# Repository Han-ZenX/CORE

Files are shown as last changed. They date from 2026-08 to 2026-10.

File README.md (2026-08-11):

# CORE - 高端频率计核心计算模块

本项目是高端频率计的核心计算模块，基于 **Xilinx ZYNQ7020** 核心板实现高精度频率测量。系统采用 **FPGA 采集 + DDR 存储 + ARM 计算** 的异构协同架构，充分发挥 ZYNQ 平台 PL（可编程逻辑）与 PS（处理系统）协同工作的优势，实现高精度、高实时性的频率测量。

## 核心架构

```
┌─────────────────────────────────────────────────┐
│                 ZYNQ7020 核心板                  │
│                                                  │
│  ┌────────────┐   AXI   ┌─────────┐   ┌───────┐ │
│  │ FPGA (PL)  │ ──────► │   DDR   │ ─► │ ARM   │ │
│  │ 信号采集    │         │ 数据缓存 │    │ (PS)  │ │
│  │ 高精度计数  │         └─────────┘    │ 频率  │ │
│  └────────────┘                        │ 计算  │ │
│                                        └───────┘ │
└─────────────────────────────────────────────────┘
```

- **FPGA 采集**：利用 PL 端实现高速信号采集与精密计数，保证测量闸门时间的硬件级精度
- **DDR 存储**：采集数据经 AXI 总线高速写入 DDR，实现大容量、连续测量数据缓存
- **ARM 计算**：PS 端运行本仓库固件，完成数据处理、频率解算与结果输出

## 仓库结构

```
CORE-master/
├── firmware/            # 固件源码（ARM 端，分层架构）
│   ├── boards/          # 板级配置（支持多硬件平台切换）
│   ├── src/
│   │   ├── app/         # 应用层：测量任务与业务流程
│   │   ├── hal/         # 硬件抽象层：屏蔽底层差异
│   │   ├── drivers/     # 驱动层：外设与 PL 交互驱动
│   │   └── services/    # 服务层：日志、通信等通用服务
│   └── CMakeLists.txt   # 固件构建配置
├── hardware/            # 硬件设计资料
│   ├── schematic/       # 原理图
│   ├── pcb/             # PCB 设计文件
│   ├── pinout/          # 引脚定义
│   ├── bom/             # 物料清单
│   ├── gerber/          # Gerber 制板文件
│   └── 3d/              # 结构 3D 模型
├── software/            # 上位机软件
│   ├── desktop/         # 桌面端
│   ├── mobile/          # 移动端
│   └── cloud/           # 云端服务
├── tests/               # 测试代码（单元 / 集成 / 硬件在环）
├── tools/               # 构建脚本与工具
└── docs/                # 架构、API、用户手册等文档
```

## 固件分层设计

固件采用四层架构，配合 `boards/` 板级配置系统实现多硬件平台适配：

| 层级 | 职责 |
|---|---|
| `app` | 应用逻辑：测量流程控制、频率解算、结果管理 |
| `services` | 通用服务：日志、通信协议、系统服务管理 |
| `hal` | 硬件抽象：统一接口，隔离平台差异 |
| `drivers` | 外设驱动：PL 端数据交互、外设控制 |

## 构建

固件使用 CMake 构建：

```powershell
cd firmware
cmake -B build
cmake --build build
```

也可使用项目脚本：

```powershell
python tools/scripts/build.py
```

## 许可

详见 [LICENSE](LICENSE)。

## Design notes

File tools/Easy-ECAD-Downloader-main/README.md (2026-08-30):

<p align="center">
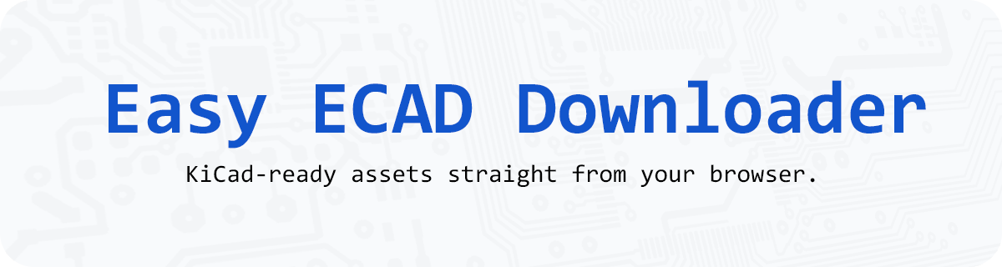
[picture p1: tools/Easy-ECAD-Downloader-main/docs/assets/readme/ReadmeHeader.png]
Easy ECAD Downloader
  
</p>

<p align="center">
  
  
  
  
  
</p>

<p align="center">
  <a href="https://chromewebstore.google.com/detail/easyeda-downloader/egbkokdcahpjimldjjaobimnofbdnncb"><strong>Install for Chrome</strong></a>
  &nbsp;|&nbsp;
  <a href="https://addons.mozilla.org/en-GB/firefox/addon/easy-ecad-downloader/"><strong>Install for Firefox</strong></a>
  &nbsp;|&nbsp;
  <a href="#quick-start"><strong>Quick start</strong></a>
  &nbsp;|&nbsp;
  <a href="#faq"><strong>FAQ</strong></a>
</p>

Easy ECAD Downloader is a browser extension for exporting KiCad-compatible CAD assets from supported distributor product pages.

It works on supported JLCPCB, LCSC, Mouser, Farnell, element14, and Newark part pages, and can download the available KiCad files for you: symbols, footprints, 3D models, and datasheets.

<br>

<p>
  
  <strong>Important:</strong> Generated library files should always be reviewed before manufacturing. Verify pin mapping, footprint dimensions, 3D model alignment, and datasheet accuracy before using exported files in production designs.
</p>
<br clear="left">

##  Contents

- [Installation](#installation)
- [Quick start](#quick-start)
- [Usage walkthrough](#usage-walkthrough)
- [Output structure](#output-structure)
- [Supported sources and outputs](#supported-sources-and-outputs)
- [Settings](#settings)
- [FAQ](#faq)
- [Technical overview](#technical-overview)
- [Contributing](#contributing)
- [Supporting docs](#supporting-docs)
- [License and attribution](#license-and-attribution)

##  Installation

| Browser | Install from | Notes |
|---|---|---|
| Chrome, Edge, Brave, and other Chromium browsers | [Chrome Web Store](https://chromewebstore.google.com/detail/easyeda-downloader/egbkokdcahpjimldjjaobimnofbdnncb) | Full support for EasyEDA-backed pages and SamacSys-backed Mouser/Farnell/element14/Newark downloads. |
| Firefox | [Firefox Add-ons](https://addons.mozilla.org/en-GB/firefox/addon/easy-ecad-downloader/) | Works for EasyEDA-backed pages. SamacSys-backed Mouser/Farnell/element14/Newark downloads need the optional Firefox relay setup. |

##  Quick start

1. Open a supported JLCPCB, LCSC, Mouser, Farnell, element14, or Newark component page.
2. Click the Easy ECAD Downloader extension icon.
3. Review the detected manufacturer and source part details.
4. Choose which assets to export.
5. Click `Download`.
6. Open the generated files from KiCad and review them before use.

##  Usage walkthrough

### 1. Open a supported component page

The content script detects supported part contexts from EasyEDA-backed JLCPCB/LCSC pages or SamacSys-backed Mouser/Farnell/element14/Newark pages.

<p align="center">
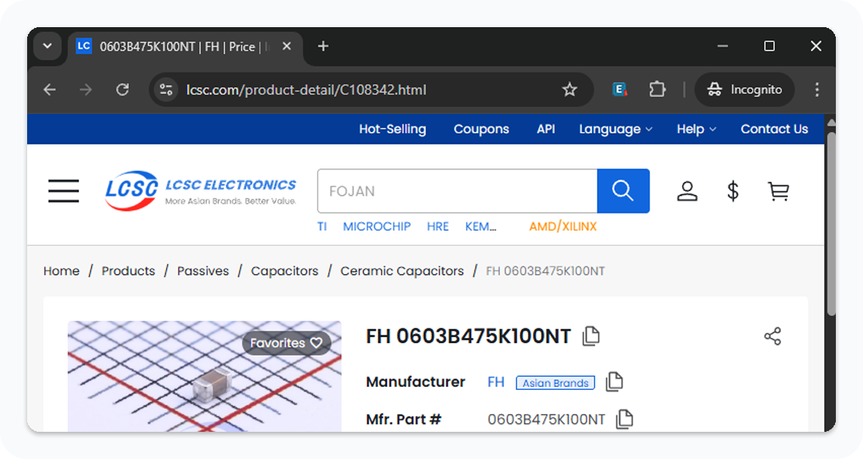
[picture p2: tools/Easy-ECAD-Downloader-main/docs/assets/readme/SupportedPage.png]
Supported component page
  
</p>

### 2. Preview and download from the popup

The popup shows manufacturer details, source-specific part metadata, symbol and footprint previews, and the available export options.

<p align="center">
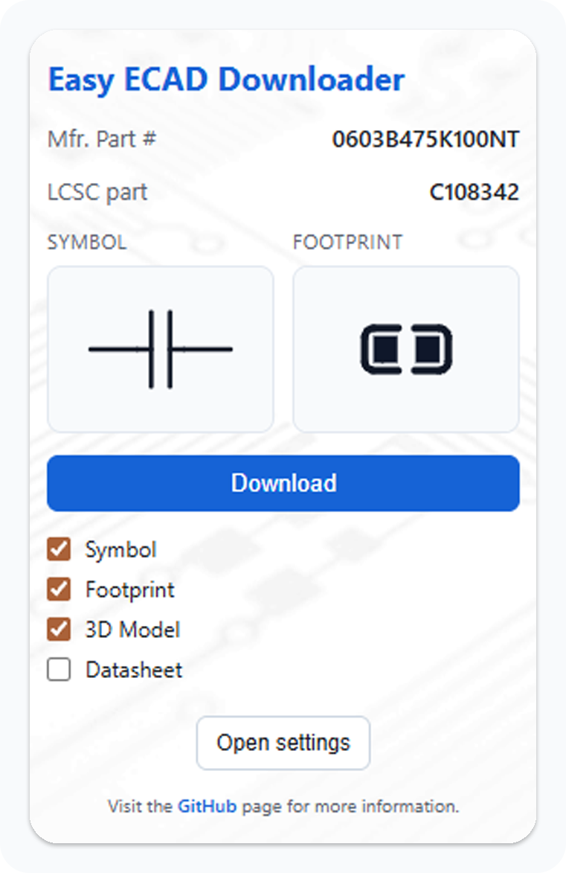
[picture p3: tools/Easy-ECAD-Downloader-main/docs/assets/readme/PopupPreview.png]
Easy ECAD Downloader popup preview
  
</p>

### 3. Use the generated KiCad files

Library mode creates a KiCad-style symbol library, footprint library, model folder, and datasheet folder under your browser downloads directory.

<p align="center">
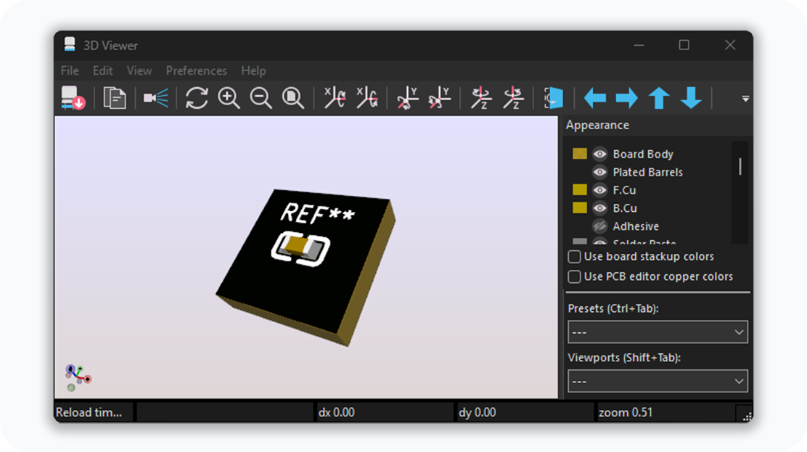
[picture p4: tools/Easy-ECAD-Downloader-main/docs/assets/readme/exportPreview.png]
KiCad 3D viewer export preview
  
</p>

##  Output structure

When `Save each file separately` is disabled, files are grouped under `Downloads/<library root>/`. The default library root is `easyECADDownloader`.

```text
Downloads/
`-- easyECADDownloader/
    |-- easyECADDownloader.kicad_sym
    |-- easyECADDownloader.pretty/
    |   `-- <component>.kicad_mod
    |-- easyECADDownloader.3dshapes/
    |   |-- <component>.step
    |   `-- <component>.wrl
    `-- datasheets/
        `-- <component>.pdf
```

When `Save each file separately` is enabled, selected files are saved as loose downloads instead of being grouped into a shared KiCad library folder. Exact filenames can vary by source.

```text
Downloads/
|-- <component>.kicad_sym
|-- <component>.kicad_mod
|-- <component>.step
|-- <component>.wrl
`-- <component>-datasheet.pdf
```

When a footprint and matching 3D model are exported together, the footprint model reference is rewritten to the generated model path. If no 3D model is exported, stale model references are removed from the generated footprint.

##  Supported sources and outputs

| Source flow | Pages | Symbol | Footprint | 3D model | Datasheet | Notes |
|---|---|---:|---:|---:|---:|---|
| EasyEDA-backed | JLCPCB, LCSC | Yes | Yes | When available | When available | Uses the detected LCSC id and upstream EasyEDA payload. |
| SamacSys-backed | Mouser, Farnell, element14, Newark | Yes | Yes | When available | No | Downloads the upstream KiCad ZIP and repackages selected assets. |

##  Settings

<p align="center">
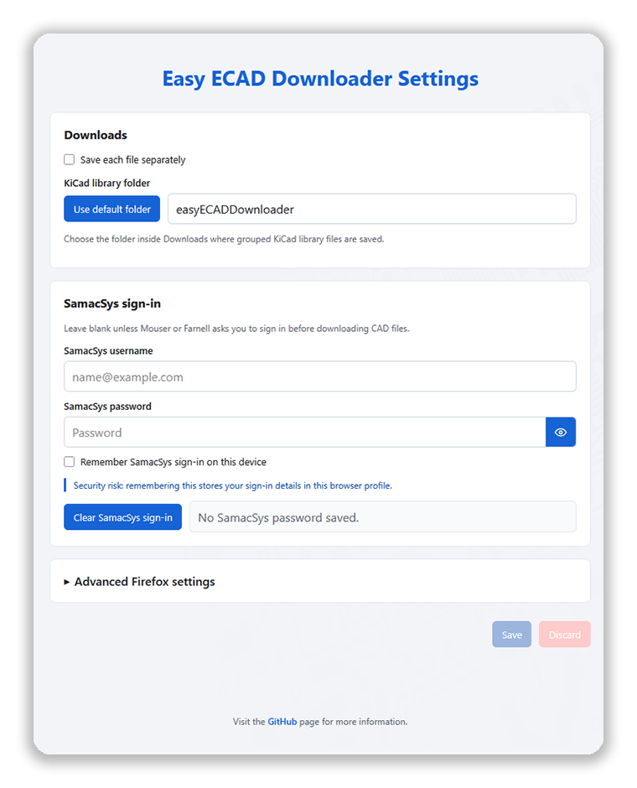
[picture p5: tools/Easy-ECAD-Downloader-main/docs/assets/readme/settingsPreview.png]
Easy ECAD Downloader settings page
  
</p>

| Setting | Purpose |
|---|---|
| `Save each file separately` | Switches between loose downloads and grouped KiCad library output. |
| `KiCad library folder` | Sets the Downloads-relative folder used for library mode, such as `easyECADDownloader` or `KiCad/easyECAD`. |
| `SamacSys username` and `SamacSys password` | Optional upstream sign-in details for Mouser/Farnell/element14/Newark CAD ZIP downloads. |
| `Advanced Firefox settings` | Configures the user-managed Firefox relay URL and helper-service auth when SamacSys export is needed in Firefox. |

Password and token fields are blank when the settings page opens, and each field has a local show/hide button for checking typed values. New values are kept for the current browser session by default. Tick the relevant `Remember ... on this device` box only if you accept the risk of storing that secret in the browser profile.

##  FAQ

<details>
<summary><strong>View frequently asked questions</strong></summary>

<br>

<details>
<summary><strong>What does Easy ECAD Downloader do?</strong></summary>

<br>

Easy ECAD Downloader is a browser extension for downloading KiCad-compatible ECAD assets from supported distributor pages. It helps export available symbols, footprints, 3D models, and datasheets from JLCPCB, LCSC, Mouser, Farnell, element14, and Newark product pages.

</details>

<details>
<summary><strong>Which websites does Easy ECAD Downloader support?</strong></summary>

<br>

Easy ECAD Downloader supports JLCPCB, LCSC, Mouser, Farnell, element14, and Newark product pages. JLCPCB and LCSC use EasyEDA-backed component data, while Mouser, Farnell, element14, and Newark use SamacSys-backed CAD downloads.

</details>

<details>
<summary><strong>What KiCad files can Easy ECAD Downloader create?</strong></summary>

<br>

Depending on the part and source data, Easy ECAD Downloader can create KiCad symbol libraries, footprint files, 3D model files, and datasheet PDFs. Common output files include `.kicad_sym`, `.kicad_mod`, `.pretty`, `.step`, `.wrl`, and PDF datasheets.

</details>

<details>
<summary><strong>Where are the downloaded KiCad files saved?</strong></summary>

<br>

In library mode, Easy ECAD Downloader saves files into a KiCad-style library folder under your browser Downloads directory. By default, this is `Downloads/easyECADDownloader/`. The output is grouped into a symbol library, a `.pretty` footprint folder, a 3D models folder, and a datasheets folder when applicable. If `Save each file separately` is enabled, selected files are saved directly into the browser downloads folder.

</details>

<details>
<summary><strong>Do I still need to check the downloaded symbol or footprint?</strong></summary>

<br>

Yes. Generated CAD assets should always be reviewed before manufacturing. Check pin mapping, pad numbering, footprint dimensions, polarity, orientation, courtyard and clearance assumptions, 3D model placement, and datasheet accuracy before ordering boards.

</details>

<details>
<summary><strong>How do I import JLCPCB or EasyEDA footprints and symbols into KiCad easily?</strong></summary>

<br>

Open a supported JLCPCB or LCSC component page, click the Easy ECAD Downloader extension icon, preview the available assets, and download the KiCad output. The extension converts the available EasyEDA-backed component data into KiCad-compatible symbol, footprint, and 3D model files where those assets exist.

</details>

<details>
<summary><strong>Can I download EasyEDA footprints for KiCad?</strong></summary>

<br>

Yes. For supported JLCPCB and LCSC pages, Easy ECAD Downloader downloads EasyEDA-backed component data and exports KiCad-compatible footprint files. When available, it can also export the matching symbol, 3D model, and datasheet.

</details>

<details>
<summary><strong>How do I download JLCPCB footprints for KiCad?</strong></summary>

<br>

Find the supported JLCPCB or LCSC component page, open Easy ECAD Downloader, and download the available KiCad footprint. This avoids manually redrawing the land pattern when source CAD data is already available.

</details>

<details>
<summary><strong>Can I convert an LCSC part number into a KiCad symbol, footprint, and 3D model?</strong></summary>

<br>

Yes, for supported LCSC or JLCPCB parts with available EasyEDA-backed data. Easy ECAD Downloader detects the part from the browser page and exports the available KiCad assets without requiring a command-line workflow.

</details>

<details>
<summary><strong>Is Easy ECAD Downloader an EasyEDA to KiCad converter?</strong></summary>

<br>

Yes, for component-level library assets. Easy ECAD Downloader converts supported EasyEDA-backed component data into KiCad-compatible symbols, footprints, and 3D models. It is not a full EasyEDA project, schematic, or PCB-layout migration tool.

</details>

<details>
<summary><strong>Can I download KiCad footprints from Mouser?</strong></summary>

<br>

Yes, when the Mouser product page provides supported ECAD data. Easy ECAD Downloader uses the Mouser and SamacSys CAD flow to download the available KiCad files and organize the selected symbol, footprint, and 3D model assets.

</details>

<details>
<summary><strong>Can I download KiCad footprints from Farnell, element14, or Newark?</strong></summary>

<br>

Yes, when the Farnell, element14, or Newark product page links to supported SamacSys ECAD data. Easy ECAD Downloader can export the available KiCad symbol, footprint, and 3D model files from the supported download flow.

</details>

<details>
<summary><strong>Is Easy ECAD Downloader a Library Loader alternative for KiCad?</strong></summary>

<br>

For supported JLCPCB, LCSC, Mouser, Farnell, element14, and Newark pages, yes. Easy ECAD Downloader can reduce the need for a separate Library Loader workflow by detecting the part page, downloading the available CAD assets, and organizing KiCad-compatible output. Library Loader may still be useful for unsupported distributors, unsupported parts, or non-KiCad workflows.

</details>

<details>
<summary><strong>How do I add downloaded symbols and footprints to KiCad?</strong></summary>

<br>

Add the generated `.kicad_sym` file through KiCad's symbol library manager and add the generated `.pretty` folder through KiCad's footprint library manager. KiCad tracks symbol and footprint libraries separately, so add both if you downloaded both asset types.

</details>

<details>
<summary><strong>Why is a KiCad symbol, footprint, 3D model, or datasheet missing?</strong></summary>

<br>

Easy ECAD Downloader can only export files that are available from the source page or linked component metadata. Some components have a footprint but no symbol, no 3D model, no datasheet, or incomplete upstream CAD data.

</details>

</details>

##  Technical overview

<p align="center">
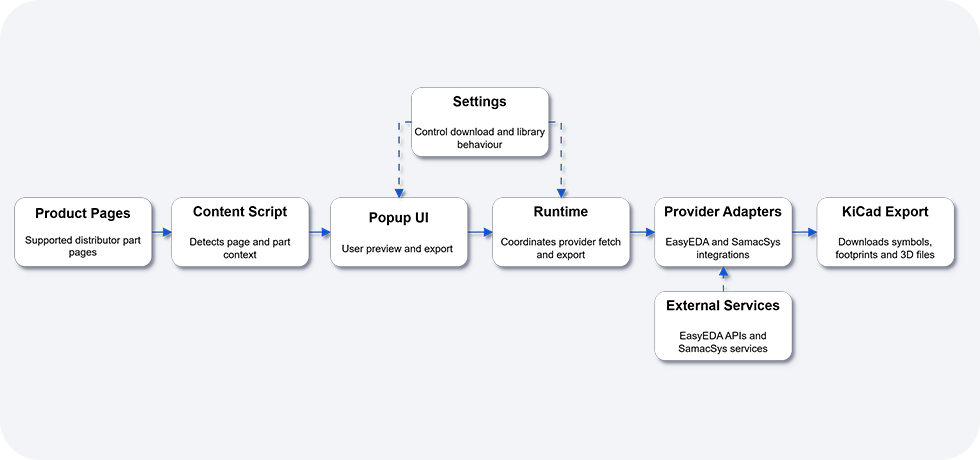
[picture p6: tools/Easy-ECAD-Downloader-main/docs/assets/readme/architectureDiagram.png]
Extension architecture overview
  
</p>

At a high level, the content script detects supported part pages, the popup requests previews and downloads, the service-worker runtime routes provider-specific work, and the source adapters fetch or repackage upstream CAD assets for KiCad.

Key implementation areas:

- `src/content_script.js`: DOM inspection and provider-aware part detection.
- `src/popup.js`: popup UI, settings, preview requests, and export requests.
- `src/service_worker_runtime.js`: provider routing and worker orchestration.
- `src/core/`: shared settings, downloads, preview data, and storage-backed library helpers.
- `src/sources/`: EasyEDA and SamacSys source adapters.
- `src/kicad/`: EasyEDA parsing, KiCad emitters, shared conversion helpers, and OBJ-to-WRL conversion.
- `tests/`: regression suite for behavior, conversion, browser runtime boundaries, and repository hygiene.

##  Contributing

Read [contributing.md](contributing.md) for development setup, local validation, contribution expectations, and manual extension-loading instructions. Read [AGENTS.md](AGENTS.md) for repository working rules.

Good contributions include parser fixes for real component pages, regression tests for failed exports, output-format corrections, browser compatibility fixes, and documentation that makes the workflow clearer for KiCad users.

##  Supporting docs

- [systemDesign.md](systemDesign.md): design source of truth.
- [CHANGELOG.md](CHANGELOG.md): notable changes by release or branch delta.
- [SECURITY.md](SECURITY.md): vulnerability reporting and credential-handling notes.
- [docs/architecture-notes.md](docs/architecture-notes.md): short implementation notes.
- [docs/firefox-samacsys-proxy.md](docs/firefox-samacsys-proxy.md): Cloudflare Worker relay example for Firefox SamacSys support.

##  License and attribution

This project includes and is derived from:

`easyeda2kicad.py`  
Copyright (c) uPesy  
Licensed under the GNU Affero General Public License v3.0

Additional code in this repository remains under the repository license.

See [LICENSE](LICENSE) for details.

<p align="center" style="font-size: 18px;">
  Made with heart for open-source electronics.
</p>

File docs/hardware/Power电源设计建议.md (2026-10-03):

# Power 电源设计建议

> 针对 `hardware/schematic/v1.0/CORE/Power.kicad_sch` 的审查结果。**第 1、2 条是原理图错误，不改上不了电**；其余为设计改进。

@fig:pw_now 图 1　当前电源网络与问题位置

## 一、必须修改

| 问题 | 依据 | 建议 |
|---|---|---|
| 1. **核心板 +5V 没有电源来源** | Power 页输出叫 `+VBUS_5V`，ZynqCore 页（核心板 5V 输入）和 Comm_Periph 页叫 `+5V`。KiCad 按电源符号 Value 区分网络，**两者不连通** | 统一网络名，或用 0Ω / 磁珠把 `+VBUS_5V` 接到 `+5V` |
| 2. USB_D+ / USB_D- 无去向 | Power 页的本地标签，其他页没有同名网络 | J10 只供电：D+/D- 打 NC、删标签。要接 PS 端 USB OTG：改层次标签接到核心板 |

（Storage 页 FT2232H 的 J12 电源网络叫 `+VBUS`，是第三个独立网络；若只用于 VBUS 检测则没问题，需确认。）

## 二、供电能力不够

| 问题 | 说明 | 建议 |
|---|---|---|
| 3. **Rd=5.1k 只能拿到 USB 默认电流** | 接电脑 USB 2.0 口仅 500 mA（2.5 W）。7020 核心板 + DDR3 + 千兆 PHY + LCD + 底板外设满载约 **3~5 W** | 加 DC 圆座（5V/3A）做主电源，与 VBUS 二极管 OR；或明确要求 5V/3A Type-C 适配器 |
| 4. TPS78633 散热 | 压差 1.7 V，0.8 A 时耗散 **约 1.4 W**；SOT-223 热阻约 50~60 °C/W，温升 70~80 °C | 先估算底板 3.3V 电流，**超过 0.5 A 换同步 Buck**（TPS62130 / SY8089）；否则 TAB 下铺铜加散热过孔 |

## 三、保护与可靠性

| 问题 | 建议 |
|---|---|
| 5. VBUS 入口无保护 | 串 **PPTC（2A）→ TVS（SMBJ5.0A）→ 防反接**（PMOS 或肖特基） |
| 6. VBUS 电容总量约 20 µF | USB 规范要求 **≤10 µF**，否则插入浪涌可能触发电脑口过流保护。入口留 10 µF + 100 nF，大电容放到开关之后 |
| 7. 无电源开关、无指示灯 | 加拨动开关或负载开关（TPS22918），加一颗电源 LED |
| 8. SHIELD 直接接 GND | 可用；重视 EMC/ESD 时改 1 MΩ ∥ 4.7 nF 接地 |

## 四、1.8V 支路

| 问题 | 建议 |
|---|---|
| 9. AMS1117-1.8 压差仅 1.5 V | 典型压差 1.1~1.3 V，大电流余量不足；负载几十 mA 可接受 |
| 10. 1.8V 是否需要 | FT2232HL **自带 1.8V 片内 LDO**（VREGOUT）。若只给 FT2232H 用，**AMS1117 可整个去掉**；TXS02612 等也需要则换 ME6211-1.8 / RT9013-18 |
| 11. AMS1117 输出电容稳定性 | 老款要求一定 ESR（手册推荐 22 µF 钽电容），全陶瓷可能振荡；换钽电容或换陶瓷稳定型 LDO |

（TPS78633 外围正确：EN 经 0Ω 接 IN，NR 10 nF，输出 10 µF 陶瓷，均符合手册。）

## 五、修改后拓扑

@fig:pw_fix 图 2　建议的电源路径（绿色为新增器件；只用 USB 供电时可省去 DC 圆座一路，但须用 5V/3A 适配器；1.8V 支路见第四节）

| 优先级 | 修改项 | 涉及文件 |
|---|---|
| **立即** | `+VBUS_5V` 与 `+5V` 统一；处理 `USB_D±` | Power、ZynqCore |
| **高** | 确认整板功耗，决定是否加 DC 圆座、3.3V 是否换 Buck | Power |
| 中 | PPTC + TVS + 防反接，VBUS 电容 ≤10 µF，开关与 LED | Power |
| 低 | 1.8V 支路精简或换 LDO | Power、Storage |

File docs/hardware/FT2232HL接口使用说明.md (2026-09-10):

# FT2232HL 接口使用说明

本文说明 FT2232HL 在 CORE 板上作为调试桥的用法：双通道如何分配、JTAG 与 UART 如何共存、主机端如何识别、配置 EEPROM 如何接线与量产烧录。

> 适用范围：FT2232HL（LQFP-64），配置 EEPROM 为 93LC56BT-I/OT。文中 `x` 代表通道字母，A 通道引脚为 `ADBUS/ACBUS`，B 通道为 `BDBUS/BCBUS`。

---

## 0. 总览

@fig:ft_arch 图 1　双通道架构与主机端枚举关系

FT2232HL 是一颗 **USB 复合设备**：一个 USB 口、一组 VID:PID（默认 `0403:6010`），下挂 **两个完全独立的 USB Interface**，各驱动一个通道引擎。

这带来本文最重要的一个结论：

**JTAG 和 UART 不需要"切换"，让 Channel A 跑 JTAG、Channel B 跑 UART，两者同时在线。**

绝大多数商用调试器（FT2232H Mini Module、Digilent HS2、Olimex ARM-USB-OCD）都是这个方案。只有在引脚实在不够、被迫让一个通道兼两职时，才会遇到切换问题（见第 4 节）。

---

## 1. 支持的全部通讯模式

每个通道可独立配置为下列任一模式：

| 模式 | 可用通道 | 最高速率 | 用途 |
| --- | --- | --- | --- |
| UART / RS232 | A、B | 12 Mbaud | 串口，带 RTS/CTS、DTR/DSR 硬件流控 |
| MPSSE 之 JTAG | A、B | 30 MHz | 芯片调试 |
| MPSSE 之 SPI | A、B | 30 MHz | **仅 Master**，支持模式 0/1/2/3 |
| MPSSE 之 I2C | A、B | 约 400 kHz | 软件模拟，有硬件前提，见第 6 节 |
| 异步 Bit-Bang | A、B | 约 1 MB/s | 8 位 GPIO 直接读写 |
| 同步 Bit-Bang | A、B | — | 时钟驱动的 GPIO |
| 异步 245 FIFO | A、B | 8 MB/s | 8 位并口 |
| 同步 245 FIFO | **仅 A** | 40 MB/s | FPGA 高速数据流 |
| CPU-FIFO（同步/异步） | A、B | — | 模拟 CPU 总线，带地址线 |
| Fast Opto-Isolated Serial | A、B | — | 光隔离串行 |

### 1.1 一条硬限制

**同步 245 FIFO 会让整颗芯片进入单通道状态**，启用后 Channel B 完全不可用。

如果需要"40 MB/s 高速口 + 独立串口"的组合，FT2232HL 做不到，应改用 FT600/FT601，或另加一颗 FT232。

### 1.2 不支持的

- **SPI Slave**：只能做主机
- **CAN / LIN 协议层**：RS485 可外挂收发器，用 RTS 或 TXDEN 引脚控方向
- **USB Host**：本芯片只能作为 USB device
- **硬件 I2C 控制器**：I2C 是 MPSSE 模拟出来的

---

## 2. 推荐的通道分配

| 方案 | Channel A | Channel B | 说明 |
| --- | --- | --- | --- |
| **调试板标配** | MPSSE 之 JTAG | UART | 最常用，两者同时可用 |
| **带 Flash 烧录** | MPSSE（JTAG / SPI 运行时切） | UART | 用 `flashrom` 直烧板载 SPI Flash，省一个编程器 |

第二种方案之所以成立，是因为 **JTAG 与 SPI 的引脚天然对应**：TCK 即 SCK、TDI 即 MOSI、TDO 即 MISO，硬件走线不用动，只有片选 CS# 需要单独安排（占用 TMS 那根线，或改用某个 GPIOL 引脚）。

`flashrom` 原生支持本芯片作 SPI 编程器：

```
flashrom -p ft2232_spi:type=2232H,port=A -w firmware.bin
```

---

## 3. 引脚复用对照

@fig:ft_pinmux 图 2　同一组数据引脚在四种模式下的功能

图 2 中红框标出的 **xD0 至 xD3 是复用冲突区**。这四根线在不同模式下含义完全不同，所以同一通道换模式时，**外部走线也必须跟着换**，否则会出现 JTAG 的 TCK 直接怼到目标板串口 RX 上这类硬件冲突。

xD4 至 xD7 与 xCBUS0 至 xCBUS7 在 MPSSE 下恒为通用 GPIO（GPIOL0-3 / GPIOH0-7），可自由用作复位、片选、LED 指示等。

---

## 4. 同一通道内切换模式

**只在被迫共用一个通道时才需要这一节。** 优先用第 2 节的分通道方案。

### 4.1 MPSSE 不是 EEPROM 选项

这是最容易误解的一点：**EEPROM 里只能选 `RS232 UART` 或 `245 FIFO`，没有 MPSSE 这个选项。**

MPSSE 是**运行时**通过 D2XX 命令进入的：

```c
FT_SetBitMode(h, 0x00, FT_BITMODE_RESET);   // 0x00 -> back to UART
FT_SetBitMode(h, 0x00, FT_BITMODE_MPSSE);   // 0x02 -> enter MPSSE (JTAG/SPI/I2C)
```

完整流程：关闭串口应用 → `FT_Open` → `FT_SetBitMode(MPSSE)` → 执行 JTAG 操作 → 用完 `FT_BITMODE_RESET` 退回 UART。

### 4.2 驱动占用问题

同一个通道不能同时被 VCP 和 D2XX 打开，这是切换时最常卡住的地方。

**Windows**：VCP 驱动把通道枚举成 COM 口后，D2XX 抢不到。用 FT_PROG 把该通道的 Driver 从 `Virtual COM Port` 改成 `D2XX Direct`，重新插拔生效。

**Linux**：`ftdi_sio` 会自动绑定，OpenOCD 打不开。先解绑：

```
echo -n "1-1.2:1.0" | sudo tee /sys/bus/usb/drivers/ftdi_sio/unbind
```

其中 `:1.0` 是 Channel A，`:1.1` 是 Channel B，具体总线编号用 `lsusb -t` 查。

按第 8 节的建议把 A 通道 EEPROM 配成 D2XX，这一步就可以省掉。

---

## 5. 主机端如何识别 JTAG 与 UART

### 5.1 Type-C 接口本身不参与识别

Type-C 只是 USB 的物理载体。CC 引脚负责插入检测、正反插方向、供电能力广播（Rp/Rd）以及 DP/TBT 这类 Alt Mode 协商，**没有"这个口是 JTAG 还是 UART"的语义**，也不该有 —— 正反插必须功能一致。

板子作为纯 UFP 时，CC1/CC2 各接一个 **5.1 kΩ 下拉到 GND** 即可。不要试图用 CC 状态去切 JTAG/UART，那是滥用协议。

### 5.2 识别发生在 USB 枚举层

| 项目 | Channel A | Channel B |
| --- | --- | --- |
| USB Interface | `0` | `1` |
| 默认描述符 | `Dual RS232-HS A` | `Dual RS232-HS B` |
| Linux 设备节点 | `/dev/ttyUSB0` | `/dev/ttyUSB1` |
| Linux 稳定路径 | `/dev/serial/by-id/...-if00-port0` | `...-if01-port0` |
| Windows | `USB Serial Converter A` | `USB Serial Converter B` |

**枚举顺序是固定的**，A 恒为 Interface 0，不会因插拔顺序改变。

生产上不要依赖 `ttyUSB0` 这种会随插拔顺序变化的名字，用 `by-id` 路径或序列号定位。

### 5.3 让设备自我标识

按第 8 节配置后，OpenOCD 可以精确锁定目标：

```
ftdi vid_pid 0x0403 0x6010
ftdi device_desc "CORE Debug A"
ftdi serial "CORE001"
ftdi channel 0
```

`ftdi channel` 的取值：`0` 为 Channel A，`1` 为 Channel B。

---

## 6. I2C 的两个硬件前提

@fig:ft_i2c 图 3　MPSSE 做 I2C 时的外部接线要求

MPSSE 的 I2C 是模拟出来的，必须满足两个外部条件，否则完全不工作：

1. **xD1 与 xD2 必须外部短接成一根 SDA。** MPSSE 的输入与输出引脚物理分离，不短接就读不到从机的 ACK。
2. **SCL 与 SDA 都要外接 2.2 kΩ 至 4.7 kΩ 上拉。** MPSSE 引脚不是真开漏，靠固件把引脚切成输入态来模拟高阻态，没有上拉就没有高电平。

结论：**I2C 能用但别扭**。做产线烧录 EEPROM、读配置芯片够用；做高速传感器采集不合适，速率上限约 400 kHz。

---

## 7. 配置 EEPROM 的接线

@fig:ft_eeprom 图 4　93LC56B 接法与救砖测试点

| FT2232H | 93LC56B | 备注 |
| --- | --- | --- |
| EECS | CS | 直连 |
| EECLK | CLK | 直连 |
| EEDATA | DI | 直连 |
| EEDATA | DO | **必须串 2.2 kΩ** |

**2.2 kΩ 不能省。** FT2232H 把 DI 与 DO 合并到一根 EEDATA 线上，靠这个电阻避免双向驱动冲突。FTDI 官方参考设计（FT2232H 数据手册典型应用电路、AN_113）即为此接法。

### 7.1 选型注意

- **必须用 B 版**。`93LC56B` 是固定 128 x 16（x16 组织），FT2232H 只认这种；`93LC56A` 是 x8 组织，**不能用**。
- SOT-23-6（后缀 `OT`）封装的 ORG 引脚不引出，内部固定为 x16，正合适。
- 引脚编号请对照 Microchip 数据手册的 OT 封装图确认，**不要照搬 SOIC-8 的顺序**。
- 工作电压 2.5 V 至 5.5 V，与 FT2232H 的 3.3 V EEPROM 接口兼容。

### 7.2 留一个救砖测试点

**布板时给 EEPROM 的 CS 引脚留一个测试点。** 一旦写错 VID/PID 导致设备无法枚举，把 CS（或 DO）临时短接到 GND，FT2232H 读不到有效 EEPROM 就会回退片内默认值重新枚举；此时松开短接，用 FT_PROG 的 `Erase` 擦掉重烧即可。

有这个测试点，能省掉一次返修。

---

## 8. 出厂配置与量产烧录

### 8.1 先澄清一个概念

**FT_PROG 是运行在 PC 上的 Windows 上位机软件，不是芯片里的东西。** 它通过 USB 与 FT2232H 通信，由 FT2232H 代为读写旁边的 EEPROM。

**93LC56BT-I/OT 出厂是空白的（全 `0xFF`）**，不含任何 FTDI 配置数据，Microchip 出厂只做电性测试。

### 8.2 空白 EEPROM 时的行为

芯片检测到 EEPROM 空白（或根本没挂 EEPROM）时，会回退到片内固化默认值，**照样能枚举**：

| 项目 | 空白 EEPROM 时的默认值 |
| --- | --- |
| VID:PID | `0403:6010` |
| Product Description | `Dual RS232-HS` |
| Serial Number | **无**，所有板子都一样 |
| Channel A / B 模式 | 都是 UART + VCP |

所以首件焊好后直接插 USB 就能被 FT_PROG 认到并烧录，**不需要预烧 EEPROM**。代价是没有序列号、没有自定义描述符、JTAG 通道会被 VCP 驱动抢走。

### 8.3 CORE 板建议配置

| 配置项 | 值 | 理由 |
| --- | --- | --- |
| VID:PID | 保持 `0403:6010` | 省掉自签驱动的麻烦 |
| Product Description | `CORE Debug` | 设备管理器里一眼可辨 |
| Serial Number | `CORE` + 自动递增 | 多板同插时可区分 |
| Channel A Driver | **D2XX Direct** | JTAG 通道，不产生 COM 口 |
| Channel B Driver | **Virtual COM Port** | UART 通道，产生 COM 口 |
| Channel A / B Hardware | 都填 `RS232 UART` | MPSSE 是运行时切的，EEPROM 无此选项 |

这样配置后，**系统里只有一个 COM 口，那必然是 UART**，零歧义；`ftdi_sio` 也不会去抢 JTAG 通道，第 4.2 节的解绑操作可以省掉。

### 8.4 小批量烧录

1. 拿第一块板在 FT_PROG 里配好所有选项
2. `File` → `Save As Template`，存成 `.xml`
3. 后续板子：`Devices` → `Scan and Parse` → 载入模板 → `Program`

**务必开启序列号自动递增**：在 `USB String Descriptors` 里勾选 `Auto Generate Serial No.`，设好 Prefix（如 `CORE`），每次 Program 自动加一。没有唯一序列号的话，两块板同时插上就分不清了。

FT_PROG 支持一次扫描多个已连接设备并批量 Program，接 USB Hub 可以同时烧一排。

### 8.5 产线脚本化

| 方案 | 平台 | 说明 |
| --- | --- | --- |
| `ftdi_eeprom`（libftdi） | Linux | 配置文件驱动，最容易接入产线脚本，推荐 |
| D2XX `FT_EEPROM_Program` | 跨平台 | 自写烧录程序，可对接 MES 或序列号数据库 |
| FT_PROG 命令行 | Windows | 3.x 版本带 CLI，参数见软件内 Help |

---

## 9. 检查清单

投板前逐项确认：

- Channel A 与 Channel B 的用途已明确分配，未出现一个通道兼两职
- 若用 I2C：xD1 与 xD2 已外部短接，SCL/SDA 上拉电阻已放置
- EEPROM 的 DO 到 EEDATA 之间已串 2.2 kΩ
- EEPROM 型号是 `93LC56B`（x16），不是 `93LC56A`
- EEPROM CS 引脚已引出测试点
- Type-C 的 CC1/CC2 各有 5.1 kΩ 下拉到 GND
- 未使用同步 245 FIFO 模式，或已接受 Channel B 不可用的代价

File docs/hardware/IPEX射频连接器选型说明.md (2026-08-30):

# IPEX 射频连接器选型说明

IPEX 是 I-PEX 公司的微型射频同轴连接器系列,正式名称是 **MHF 系列**。1 代和 3 代最核心的区别是**尺寸**,但最要命的实用区别是——**两者物理上完全不能互配。**

## 主要参数对比

| | IPEX 1 (MHF1) | IPEX 3 (MHF3) |
|---|---|---|
| 别名 | U.FL(Hirose 等效型号) | — |
| 配对后高度 | 约 2.5 mm | 约 1.6 mm |
| 插座尺寸 | 约 2.6 x 2.6 mm | 约 2.0 x 2.0 mm |
| 频率范围 | DC ~ 6 GHz | DC ~ 12 GHz |
| 常配线径 | 1.13 mm / 1.37 mm | 0.81 mm / 1.13 mm |
| 特性阻抗 | 50 ohm | 50 ohm |
| 插拔寿命 | 约 30 次 | 约 30 次 |
| 普及度 / 成本 | 最高 / 最低 | 较低 / 较高 |

(具体数值各厂商略有出入,正式选型请以对应料号的 datasheet 为准。线径越细走线越柔,但插入损耗越大,长走线优先选粗线。)

完整代际关系顺带列一下,方便辨认:

| 代次 | 型号 | 高度 | 典型场景 |
|---|---|---|---|
| 1 代 | MHF1 / U.FL | ~2.5 mm | WiFi 模块、路由器、开发板 |
| 2 代 | MHF2 / W.FL | ~2.0 mm | 过渡型号,较少见 |
| 3 代 | MHF3 | ~1.6 mm | 小型化设备、部分 M.2 |
| 4 代 | MHF4 | ~1.2 mm | M.2 无线网卡、5G 模组主流 |
| 4L | MHF4L | ~1.0 mm | 极限薄型设备 |

需要注意 **U.FL 是 Hirose(广濑)的商标**,与 I-PEX 的 MHF1 是互相兼容的等效产品,不是同一家公司的型号。

---

## 几个实际会踩的坑

**① 绝对不能混插。** 1 代和 3 代的插座内径、中心针尺寸都不同。强行按压 3 代插头到 1 代插座上(或反过来),轻则接触不良、驻波比飙升,重则直接把插座撑坏。需要跨代连接**只能用转接线**。

**② 插拔寿命只有约 30 次,且这是个真实限制。** 这类连接器设计上是"装配一次"的,不是给你反复调试用的。频繁插拔会导致外圈弹片失去弹性,表现为接触时好时坏、天线性能忽高忽低——这种间歇性故障很难排查。**建议做法:调试期用一根 IPEX 转 SMA 的转接线固定在板上,后续所有插拔都在 SMA 那一端进行。**

**③ 拔的时候要用专用拔具,或垂直向上撬。** 斜着拽会把插座从 PCB 上撕下来,连焊盘一起。

**④ 频率上限影响选型。** 2.4G / 5.8G 应用(WiFi、蓝牙、图传)用 1 代完全够。但 WiFi 6E 的 6 GHz 频段、或更高频段会触及 1 代上限,应选 3 代或 4 代。

---

## 怎么选

| 使用场景 | 推荐 |
|---|---|
| 开发板、原型验证 | **IPEX 1** — 最便宜,线材最好买,装配最省心 |
| 2.4G / 5.8G 应用 | **IPEX 1** — 频率完全覆盖 |
| 成品设备空间紧张,或需 6 GHz 以上 | IPEX 3 / 4 |
| 对接 M.2 形态无线模组 | 先查模组 datasheet,**现在主流是 MHF4,不是 3 代** |

**没有明确的高度约束或频率需求时,默认选 IPEX 1**,不要仅为"更先进"而选高代次。

## 怎么识别手上的是哪一代

最可靠的方法是量插座外径:

| 实测外径 | 判定 |
|---|---|
| 约 2.6 mm | **1 代** |
| 约 2.0 mm | **3 代** |
| 约 1.6 mm | **4 代** |

目视对比也行,1 代明显比 3 代粗一圈。

## 采购提醒

电商平台上 IPEX 代次的**标注错误率很高**,同一卖家不同链接口径不一致的情况常见。买线材时优先看实物尺寸标注,或直接买注明 I-PEX 原厂料号的产品(如 `20279-001E-01`、`20449-001E-01`)。转接线要**同时确认两端的代次和线径**。

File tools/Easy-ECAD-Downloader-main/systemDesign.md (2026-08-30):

# System Design: Easy ECAD Downloader

## 1. Purpose

This document describes the current implemented design of the Easy ECAD Downloader browser extension.

The extension supports three provider flows:

- EasyEDA-backed JLCPCB and LCSC pages
- Mouser pages that expose the SamacSys / Component Search Engine ECAD button
- Farnell, element14, and Newark pages that expose the Supplyframe / SamacSys ECAD link

The repository remains intentionally compact. If code and design diverge, update one of them in the same change.

## 2. Implemented workflow

### 2.1 Supported operator flow

1. Open a supported JLCPCB, LCSC, Mouser, Farnell, element14, or Newark product page.
2. Optionally open the extension settings page to configure download layout or advanced SamacSys options.
3. Open the extension popup.
4. Ask the content script for a provider-aware part context via `GET_PART_CONTEXT`.
5. Ask the service worker for `GET_PART_PREVIEWS`.
6. Choose which artifacts to export.
7. Ask the service worker to export the current part with `EXPORT_PART`.

### 2.2 Explicit non-goals

The current repository does not implement:

- browser automation outside the popup/content-script/service-worker model
- end-to-end browser-run integration tests in real Chrome or Firefox
- a project-hosted proxy or cloud backend for Mouser / SamacSys Firefox support
- a broader application-layer architecture beyond the existing file split

## 3. Supported contexts and assumptions

- The content script is injected only on matching JLCPCB, LCSC, Mouser, Farnell, element14, and Newark pages.
- EasyEDA-backed pages expose an LCSC-style part id such as `C12345`.
- Mouser support depends on the ECAD button `#lnk_CadModel[data-testid="ProductInfoECAD"]`.
- Farnell, element14, and Newark support depend on a Supplyframe / SamacSys link exposed in the `ECAD / MCAD` section.
- The content script returns a generic part context, not a provider-specific ad hoc message shape.
- EasyEDA previews are generated locally from CAD payload primitives.
- SamacSys distributor previews come from SamacSys JSON preview endpoints and are displayed as PNG data URLs.
- EasyEDA datasheet availability comes from URLs exposed by the upstream payload.
- SamacSys distributor datasheet export is currently unsupported.
- SamacSys distributor preview and export work directly in Chrome.
- Firefox SamacSys support is opt-in and depends on a user-managed relay URL stored by the extension settings page.
- SamacSys ZIP export may still require upstream authentication.
- On Chrome direct requests, the worker first tries the normal browser session and retries the ZIP request once with configured upstream auth if the first ZIP request returns `401`.
- On Firefox relay mode, the worker uses the relay path and returns a sign-in-required error if the upstream ZIP request remains unauthorized.
- In Firefox relay mode, the service worker forwards matching `componentsearchengine.com` cookies through the relay so authenticated ZIP downloads can reuse the user's upstream browser session.
- Firefox relay mode can send a separate relay `Authorization` header on the Worker POST when the user configures helper-service auth.
- Firefox relay mode can forward an upstream SamacSys `Authorization` header for ZIP endpoints that rely on HTTP Basic auth instead of cookies alone.
- The Manifest V3 background is declared for both Chrome and Firefox: Chrome uses `background.service_worker`, while Firefox uses the background-document fallback from `background.scripts`. This combined manifest relies on Firefox 121 or newer.
- The configurable library download root must remain relative to the browser's Downloads directory.

## 4. Repository architecture

### 4.1 User-to-backend flow

There is no application-owned cloud backend in this repository. The service worker is the browser-local backend boundary, and it calls external upstream provider services when previews or exports require network data.

```mermaid
flowchart LR
    user["User on supported product page"]
    productPage["JLCPCB / LCSC / Mouser / Farnell / element14 / Newark DOM"]
    contentScript["Content script\nsrc/content_script.js"]
    popup["Extension popup\nsrc/popup.js"]
    settingsPage["Settings page\nsrc/settings_page.js"]
    storage["Browser storage\nchrome.storage.local/session"]
    serviceWorker["Extension backend\nsrc/service_worker.js"]
    converter["EasyEDA converter\nsrc/kicad_converter.js"]
    zipReader["SamacSys ZIP reader\nsrc/vendor/zip_reader.js"]
    downloads["Browser downloads\nchrome.downloads"]
    easyeda["EasyEDA APIs\nCAD, STEP, OBJ, datasheet URLs"]
    samacsys["SamacSys / Component Search Engine\nentry, preview, ZIP, WRL"]

    user --> productPage
    user --> popup
    user --> settingsPage
    popup -- "GET_PART_CONTEXT" --> contentScript
    contentScript --> productPage
    contentScript -- "provider-aware part context" --> popup
    popup <--> storage
    settingsPage <--> storage
    popup -- "GET_PART_PREVIEWS / EXPORT_PART" --> serviceWorker
    serviceWorker <--> storage
    serviceWorker --> easyeda
    serviceWorker --> samacsys
    serviceWorker --> converter
    serviceWorker --> zipReader
    converter --> serviceWorker
    zipReader --> serviceWorker
    serviceWorker --> downloads
    downloads --> user
```

### 4.2 `src/content_script.js`

Owns page inspection only:

- detect EasyEDA/LCSC identifiers from definition lists, known tables, and page text
- detect Mouser SamacSys ECAD availability from the ECAD button
- detect Farnell, element14, or Newark SamacSys ECAD availability from the `Supply Frame Models Link`
- read provider-specific source part metadata from the page DOM
- reconstruct the Mouser SamacSys entry URL from `loadPartDiv(...)`
- reconstruct the Farnell, element14, or Newark SamacSys entry URL from the Supplyframe link metadata
- reply to popup-originated `GET_PART_CONTEXT` requests

It remains a DOM-reading boundary with no network or download logic.

### 4.3 `src/popup.js`

Owns popup UI state and user interaction:

- cache popup DOM elements
- load current settings from extension storage for provider gating
- query the active tab and request the current provider-aware part context
- render the fixed `Mfr. Part #` row plus a dynamic provider-specific source row
- request previews and datasheet availability
- gate downloads based on provider support and checkbox selection
- open the dedicated settings page from the popup settings button
- send `EXPORT_PART` requests to the service worker

It remains the UI-facing boundary. It does not own fetch, archive extraction, or conversion logic.

### 4.4 `src/settings_page.js`

Owns persistent settings UI:

- load and save ordinary settings through `chrome.storage.local`
- keep helper tokens and SamacSys credentials in `chrome.storage.session` unless the user explicitly opts to remember them on this device
- keep form edits local to the page until the user chooses `Save`, with `Discard` restoring the last loaded settings
- expose the download layout controls, including loose-file mode and library folder root
- expose SamacSys username/password auth inputs for Mouser/Farnell/element14/Newark downloads
- let users temporarily show or hide typed password and token values without changing stored settings
- expose Firefox-only helper-service auth and relay URL inside a hidden-by-default advanced Firefox settings menu
- normalize settings through `src/core/settings.js`

It does not request part contexts, previews, exports, or downloads.

### 4.5 `src/service_worker.js`

Owns runtime registration only:

- register the Manifest V3 background message listener
- delegate request handling to the runtime/router module

The operational core now lives behind this entrypoint rather than inside one file.

### 4.6 `src/service_worker_runtime.js` and supporting modules

Own the service-worker backend orchestration:

- normalize part context and route preview/export requests by provider
- enforce runtime-specific blocking such as Firefox SamacSys gating when no relay is configured
- compose source adapters with shared download, storage, and settings helpers
- shape success and error responses back to the popup

The runtime is intentionally split into:

- source adapters under `src/sources/`
- shared worker business logic under `src/core/`

Within `src/sources/`, the current SamacSys-backed distributors share:

- `src/sources/samacsys_distributor_adapter.js` for provider-facing preview/export orchestration
- `src/sources/samacsys_common.js` for shared SamacSys page, preview, ZIP, and asset-rewrite helpers

This keeps the message boundary stable while allowing future sources to be added without expanding the entrypoint.

### 4.7 `src/kicad_converter.js`

Keeps the public conversion API stable and delegates implementation to focused converter modules under `src/kicad/`.

Those modules own:

- EasyEDA symbol parsing
- EasyEDA footprint parsing
- coordinate, unit, and text-style conversion
- KiCad symbol text generation
- KiCad footprint text generation
- OBJ-to-WRL conversion

Mouser parts do not flow through this converter for symbol or footprint generation because the upstream ZIP already contains KiCad assets.

### 4.8 `src/vendor/zip_reader.js`

Owns small runtime archive extraction support:

- ZIP central-directory parsing
- stored-entry reads
- deflate-entry reads through runtime decompression primitives

It exists so the service worker can extract the KiCad subtree from the SamacSys ZIP without adding a build step.

### 4.9 `tests`

The test suite remains the primary regression net for:

- page-detection logic
- popup state transitions and messaging
- service-worker orchestration and download behavior
- EasyEDA conversion behavior
- repository governance and footer discipline

## 5. Core data flow

### 5.1 Detect the current part

- The popup queries the active tab.
- The popup asks the content script for `GET_PART_CONTEXT`.
- On EasyEDA-backed pages, the content script returns:
  - provider `easyedaLcsc`
  - source label `LCSC part`
  - source part number equal to the detected LCSC id
  - manufacturer part number when the page exposes `Mfr. Part #`
  - lookup metadata containing the LCSC id
- On Mouser pages, the content script returns:
  - provider `mouserSamacsys`
  - source label `Mouser part`
  - source part number equal to `Mouser No`
  - manufacturer part number equal to `Mfr. No`
  - lookup metadata containing manufacturer name and a reconstructed SamacSys entry URL
- On Farnell, element14, and Newark pages, the content script returns:
  - provider `farnellSamacsys`
  - source label `Farnell part`, `element14 part`, or `Newark part` based on the current site
  - source part number equal to the detected page order code or page part identifier
  - manufacturer part number from the SamacSys link metadata or page text
  - lookup metadata containing manufacturer name and a reconstructed SamacSys entry URL

### 5.2 Request previews

- The popup asks the service worker for `GET_PART_PREVIEWS`.
- EasyEDA-backed pages:
  - fetch the EasyEDA CAD payload
  - synthesize symbol and footprint SVG previews
  - derive datasheet availability from the payload
- Mouser, Farnell, element14, and Newark pages:
  - fetch the SamacSys entry URL
  - follow the part-page redirect and parse the ZIP form and preview token
  - fetch `symbol.php` and `footprint.php` JSON previews
  - return PNG data URLs
  - report datasheet unavailable
- In Firefox, those same SamacSys requests are sent through the optional user-managed relay when configured; otherwise they fail early with the existing proxy-required error.
- In Firefox relay mode, the worker attaches the current SamacSys cookie header to proxied requests when browser cookies are available.
- In Firefox relay mode, the worker sends any configured relay `Authorization` header only on the Worker POST itself.
- In Firefox relay mode, the worker forwards upstream SamacSys `Authorization` only when it can generate one from configured SamacSys username/password credentials.
### 5.3 Export EasyEDA-backed parts

- The service worker fetches the EasyEDA payload using the detected LCSC id.
- The converter produces KiCad symbol and footprint text.
- Symbol, footprint, 3D, and datasheet exports follow the existing current-provider settings:
  - loose-file downloads when `downloadIndividually` is `true`
  - KiCad-style library structure when `downloadIndividually` is `false`
- Library-mode symbol exports merge into a stored symbol library keyed by the resolved library root.
- Footprint model references are reconciled after 3D export attempts finish:
  - loose-file footprints reference `${KIPRJMOD}/<modelFilename>` when a model was exported
  - library-mode footprints reference `../<libraryName>.3dshapes/<modelFilename>` when a model was exported
  - stale footprint `(model ...)` blocks are removed when no selected 3D model artifact is exported
- EasyEDA OBJ-to-WRL conversion recenters model geometry in X/Y, bottom-aligns the model in Z, and writes footprint model offsets in KiCad 3D units so the WRL aligns with the generated footprint.
- Library-mode datasheet exports are written under `<libraryRoot>/datasheets/`.

### 5.4 Export SamacSys distributor parts

- The service worker fetches the SamacSys entry URL and resolves the part page.
- In Firefox with a configured relay, the service worker sends those SamacSys HTTP requests through the relay instead of fetching upstream directly.
- In Firefox with a configured relay, the service worker also reads the matching upstream cookies through `chrome.cookies` and forwards them with those proxied requests.
- For authenticated ZIP flows that use HTTP Basic auth, the service worker resolves upstream SamacSys `Authorization` from the shared precedence and:
  - on Chrome direct requests, retries one ZIP request with that auth after an initial `401`
  - on Firefox relay requests, forwards that auth through the relay as part of the proxied upstream request
- When helper-service auth is configured, the relay POST itself also carries a separate relay `Authorization` header that is never forwarded upstream.
- The part page supplies:
  - a stable `partID`
  - a preview token
  - ZIP download form metadata
- The service worker downloads the SamacSys ZIP and extracts only:
  - `KiCad/*.kicad_sym`
  - `KiCad/*.kicad_mod`
  - `3D/*.stp` and `3D/*.step`
  - optional `3D/*.wrl`
- Loose-file mode downloads the extracted files directly into Downloads.
- Library mode repackages the extracted assets into the current KiCad structure:
  - symbol library merge into `<libraryRoot>/<libraryName>.kicad_sym`
  - footprints into `<libraryRoot>/<libraryName>.pretty/`
  - 3D assets into `<libraryRoot>/<libraryName>.3dshapes/`
- Library mode rewrites:
  - the symbol `Footprint` property to `<libraryName>:<footprintName>`
  - the footprint `(model ...)` path to `../<libraryName>.3dshapes/<modelFilename>`
- When 3D export is selected, the worker exports STEP models and any WRL files already present in the SamacSys ZIP without probing extra remote WRL endpoints.

## 6. Storage and settings behavior

- The popup stays focused on detection, previews, export selection, and opening the dedicated settings page.
- The settings page owns persistent controls for download layout, Firefox relay configuration, and optional SamacSys auth values.
- The settings page uses explicit `Save` and `Discard` actions rather than writing every field edit immediately.
- The settings page hides the advanced Firefox settings menu when opened in Chrome.
- `chrome.storage.local` stores ordinary extension settings:
  - `downloadIndividually`
  - `libraryDownloadRoot`
  - `samacsysFirefoxProxyBaseUrl`
  - `rememberSamacsysCredentials`
  - `rememberSamacsysFirefoxProxyAuthorizationHeader`
- `chrome.storage.session` stores session-only secret values by default:
  - `samacsysFirefoxProxyAuthorizationHeader`
  - `samacsysFirefoxUsername`
  - `samacsysFirefoxPassword`
- If a remember-on-this-device box is checked, the corresponding helper token or SamacSys username/password is stored in `chrome.storage.local` instead.
- `chrome.storage.local` also stores accumulated symbol library text used for append-style symbol exports in library mode.
- Stored symbol-library content is keyed by the resolved library root so separate library folders keep separate merged symbol libraries.

## 7. Error and warning handling

- Detection failures in the popup produce user-facing status messages and disable export.
- Service-worker preview failures return structured error responses to the popup.
- Export failures return structured error responses to the popup.
- Partial export issues that do not invalidate the whole request, such as missing selected datasheets, unavailable selected 3D models, or selected SamacSys asset categories absent from the upstream ZIP, are accumulated as warnings.
- SamacSys distributor requests in Firefox fail early with a structured unsupported error message when no relay is configured.
- Relay transport failures are surfaced distinctly from upstream SamacSys HTTP failures.
- SamacSys ZIP `401 Unauthorized` responses are rewritten into a sign-in-required error so the popup can tell the user what upstream precondition is missing.

## 8. External dependencies and browser APIs

### 8.1 Network dependencies

- EasyEDA component API for CAD payloads
- EasyEDA module endpoints for STEP and OBJ assets
- SamacSys / Component Search Engine entry page, preview JSON endpoints, and ZIP download endpoint

### 8.2 Browser APIs

- `chrome.runtime`
- `chrome.storage.local`
- `chrome.storage.session`
- `chrome.downloads`
- `chrome.cookies` for Firefox relay cookie forwarding on SamacSys requests
- `Blob` and `URL.createObjectURL`
- runtime decompression primitives used by the vendored ZIP reader

## 9. Output artifacts and naming rules

- EasyEDA symbol output uses a standalone `<lcscId>-<symbolName>.kicad_sym` file in loose mode or the shared library file in library mode.
- SamacSys distributor loose-file symbol output keeps the extracted `.kicad_sym` filename from the ZIP.
- Footprint output uses the extracted or generated `.kicad_mod` filename.
- SamacSys distributor footprint library-mode downloads rewrite the model path into the library `.3dshapes` directory.
- EasyEDA footprint downloads rewrite the first KiCad `(model ...)` path to the exported STEP or WRL artifact, preferring WRL when both are produced, and remove stale model blocks when no model artifact is exported.
- EasyEDA datasheet output uses a sanitized base name plus `-datasheet` and the detected extension. In library mode it is saved under `<libraryRoot>/datasheets/`.
- The library root name defaults to `easyECADDownloader` and can be changed to another Downloads-relative folder for library mode.

## 10. Maintainability and testing boundaries

- `src/kicad_converter.js` should stay the main unit-test target for pure conversion rules.
- `src/content_script.js` should stay small enough to test through DOM fixtures and message mocks.
- `src/popup.js` should be tested with DOM fixtures and mocked browser APIs rather than real extension runs.
- `src/service_worker_runtime.js` should be tested with mocked browser APIs, mocked fetch, mocked archive extraction, and controlled converter stubs.
- The current Vitest/Vite/jsdom test stack requires Node `20.19.0+`, `22.13.0+`, or `24+`.
- Production source should not be refactored solely to make tests easier; harnesses should adapt to the existing code shape.
- Local and CI validation share `npm run validate`, which runs ESLint, Vitest, `npm audit --audit-level=moderate`, and `git diff --check`.
- GitHub Actions runs validation with `npm ci` on Node `20.19.0`, `22.13.0`, and `24.x`.
- `SECURITY.md` owns vulnerability reporting expectations and credential-handling guidance.
- Repository hygiene tests reject high-confidence secret patterns plus common local environment, archive, log, editor, and temporary files.
- Repository hygiene tests reject non-placeholder email addresses in code and fixture text while leaving documentation and canonical source footer contact details intact.
- Repository hygiene tests decode long HTTP Basic auth examples and require decoded identities to use placeholder email domains.
- Git-history security tests run those security checks across every reachable commit; CI uses a full-history checkout so rewritten or rebased branches are scanned beyond the tip tree. This is a full-validation and CI gate, not a manual per-intermediate-commit requirement while iterating locally.
- Repository hygiene tests also enforce conventional file names, lower camelCase function declarations, and maintained-file line-count limits.

## 11. Repository rules that should remain true

- Do not change extension runtime behavior casually.
- Do not reorganize production files without a real architectural reason.
- Keep browser API orchestration in the service worker, UI state in the popup, DOM extraction in the content script, and conversion rules in the converter.
- Keep governance files and hygiene tests aligned with the codebase.

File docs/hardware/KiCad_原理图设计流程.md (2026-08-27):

# KiCad 原理图设计流程

本文按实际执行顺序，梳理 KiCad 原理图（Eeschema）从新建工程到输出网表的完整流程。

> 环境：KiCad 10.0.4，简体中文界面。界面项以「中文 / English」成对给出；标注 `[英文]` 的表示该处界面显示的就是英文原文（官方中文翻译未覆盖）。快捷键取自本机实际配置。

---

## 0. 流程总览

@fig:sch_flow 图 1　原理图设计八阶段

原理图的产出物只有一个：**一份准确描述电气连接、且每个元件都对应到可采购实物的网表**。所有工作都服务于这个目标。

其中阶段六（分配封装）和阶段七（ERC）是两个卡点：

- **封装错了**，板子回来元件焊不上，直接报废
- **ERC 没查干净**，漏连、短路会一路带到 PCB，等调试时才发现

---

## 1. 阶段一：工程与图纸准备

### 1.1 新建工程

用 KiCad 项目管理器新建工程，会同时生成 `.kicad_pro`、`.kicad_sch`、`.kicad_pcb`。

**不要单独打开 `.kicad_sch` 文件工作**——脱离工程时，库路径、网络类等工程级设置不会生效。

### 1.2 页面设置

`文件(F) / File` → `页面设置... / Page Settings...`

- 选择图幅（A4 / A3）。电路复杂时优先用层次化拆分成多张 A4，而不是硬塞进一张 A3
- 填写标题栏：图纸标题、版本号、日期、作者、公司

标题栏是后续版本管理的依据，每次改动改版本号，比事后翻 git log 直观。

### 1.3 原理图配置

`文件(F) / File` → `原理图配置... / Schematic Setup...`

重点是两项：

- **格式化**：字号、线宽、字段可见性的全局默认值
- **电气规则**：ERC 各类违规的严重级别（错误 / 警告 / 忽略）

### 1.4 栅格

原理图**必须在栅格上绘制**。KiCad 默认符号引脚间距是 2.54 mm（100 mil），连线时栅格也应保持 2.54 mm 或 1.27 mm。

栅格不对齐是新手最常见的隐性错误：**看上去线连到引脚上了，实际差几个像素，电气上没连接**。放大后能看到引脚末端的小方块没有变成连接点。

### 1.5 常见错误

- 用极小的栅格画线，导致连线与引脚"看起来连上了"但实际没连
- 一张图纸塞下整个系统，后期无法阅读也无法维护
- 标题栏留空，多版本迭代后分不清哪张是最新的

---

## 2. 阶段二：符号库准备

### 2.1 管理符号库

`偏好设置 / Preferences` → `管理符号库... / Manage Symbol Libraries...`

分全局库和工程库两级。**工程专用的自建符号应放工程库**，跟着工程走，换电脑不会丢。

### 2.2 什么时候需要自建符号

标准库覆盖不了的情况：

- 特定型号的芯片（本项目的 `ZYNQ7010&7020_CB` 核心板座）
- 非标连接器
- 需要按功能拆分成多个单元（Unit）的复杂器件

### 2.3 符号编辑器

`工具(T) / Tools` → `符号编辑器 / Symbol Editor`

画符号时的要点：

- 引脚必须放在 2.54 mm 栅格上，否则原理图里连不上线
- **引脚电气类型必须设对**，它直接决定 ERC 的判断
- 多单元器件（如四运放）拆成 Unit A/B/C/D，电源引脚单独放一个 Unit
- 引脚名和引脚号要与数据手册严格一致

### 2.4 引脚电气类型

| 中文 / English | 用于 |
|---|---|
| 输入 / Input | 只接收信号的引脚 |
| 输出 / Output | 驱动信号的引脚 |
| 双向 / Bidirectional | 数据总线、GPIO |
| 三态 / Tri-state | 可高阻的输出 |
| 无源 / Passive | 电阻、电容、连接器引脚 |
| 电源输入 / Power input | 芯片的 VCC、GND 引脚 |
| 电源输出 / Power output | 稳压器输出、电源符号 |
| 集电极开路 / Open collector | OC 门、I²C |
| 发射极开路 / Open emitter | OE 门 |
| 未指定 / Unspecified | 不参与 ERC 判断 |

**把不确定的引脚设成"无源"是常见的偷懒做法**，代价是 ERC 失去检查能力。宁可花时间设对。

### 2.5 常见错误

- 引脚不在栅格上，原理图里怎么都连不上
- 引脚号与数据手册对不上，PCB 焊盘全错
- 芯片的 VCC 设成"电源输出"，导致 ERC 漏报电源冲突

---

## 3. 阶段三：绘制电路

### 3.1 六种建立连接的方式

@fig:sch_connect 图 2　原理图中六种建立连接的方式

这是原理图最核心的知识点。**连接是否成立与视觉无关，只与上述规则有关。**

### 3.2 基本操作

| 操作 | 中文 / English | 快捷键 |
|---|---|---|
| 放置符号 | Add Symbol | `A` |
| 画导线 | Add Wire | `W` |
| 画总线 | Add Bus | `B` |
| 画图形线（非电气） | Draw Lines | `I` |
| 放置结点 | 添加结点 / Add Junction | `J` |
| 网络标签 | Add Net Label | `L` |
| 全局标签 | Add Global Label | `Ctrl+L` |
| 层次标签 | 添加层次标签 / Add Hierarchical Label | `H` |
| 电源符号 | Add Power Symbol | `P` |
| 无连接标志 | 添加 '无连接' 标志 / Add No Connect Flag | `Q` |
| 放置文本 | 添加文本 / Add Text | `T` |
| 总线入口 | Add Bus Entry | `Z` |
| 展开总线 | Unfold Bus | `C` |
| 切换连线朝向 | Switch Posture | `/` |
| 撤销上一段连线 | — | `Backspace` |

### 3.3 编辑操作

| 操作 | 快捷键 |
|---|---|
| 属性 / Properties | `E` |
| 编辑数值 / Value | `V` |
| 编辑位号 / Reference | `U` |
| 编辑封装 / Footprint | `F` |
| 移动 / Move | `M` |
| 拖动（保持连线）/ Drag | `G` |
| 逆时针旋转 / 顺时针旋转 | `R` / `Shift+R` |
| 水平镜像 / 垂直镜像 | `X` / `Y` |
| 自动摆放字段 | `O` |
| 重复上一次放置 | `Ins` |
| 交换位置 / Swap | `Alt+S` |

`M`（移动）和 `G`（拖动）的区别很重要：**`M` 会把元件拖走并断开连线，`G` 会保持连线跟随**。调整已连好的电路要用 `G`。

### 3.4 电源与地

用**电源符号（`P`）**处理电源和地，不要用导线到处拉。同名电源符号自动全局连通，图纸干净得多。

`PWR_FLAG` 是一个特殊符号：告诉 ERC "这个网络确实有电源驱动"。当电源来自连接器、电池等被标为"无源"的引脚时，必须加 `PWR_FLAG`，否则 ERC 会报"电源未驱动"。

### 3.5 绘图规范

好的原理图是给人读的，规范直接影响后期维护和评审效率：

- **信号从左到右**：输入在左，处理在中，输出在右
- **电源在上，地在下**
- **功能分区**：一个区域画一个功能模块，用文本框标注模块名
- **去耦电容画在芯片附近**，并标注它服务于哪个电源引脚
- **不要让导线穿过符号**
- **交叉但不相连的线不要放结点**，相连的必须放

### 3.6 网络命名规范

- 差分对必须成对命名 `xxx_P` / `xxx_N` 或 `xxx+` / `xxx-`，否则 PCB 里无法用差分对布线
- 名字用途明确：`CLK_125M` 好过 `NET1`
- 避免中文和空格

### 3.7 常见错误

- **交叉处漏放结点**：该连的没连，ERC 有时也查不出来
- **用网络标签跨图纸连接**：网络标签只在本张图纸内生效，跨图纸必须用全局标签
- **未使用的引脚不加无连接标志（`Q`）**：ERC 会一直报警告，淹没真正的错误
- **用 `M` 移动已连线元件**，连线断开而不自知
- **电源用导线拉**，图纸乱成一团

---

## 4. 阶段四：层次化设计

### 4.1 何时需要

超过一张图纸装不下、或电路有清晰的功能模块划分时，就应该层次化。本项目按功能拆成电源、射频前端、核心板接口、通信接口等子图是合适的。

@fig:sch_hierarchy 图 3　层次化原理图的父子对应关系

### 4.2 操作步骤

1. 在顶层图纸按 `S` 放置**图纸符号**，指定子图文件名
2. 双击进入子图（或 `进入图纸 / Enter Sheet`）
3. 在子图中用 `H` 放置**层次标签**，作为对外接口
4. 回到顶层，在图纸符号上添加**图纸引脚 / Add Sheet Pin**，名称与层次标签一致
5. 顶层用导线连接各图纸符号的引脚

**层次标签与图纸引脚同名即相连**，这是子图与父图之间唯一的连接方式。

### 4.3 导航

| 操作 | 中文 / English | 快捷键 |
|---|---|---|
| 层次导航 | 层次导航 / Hierarchy Navigator | `Ctrl+H` |
| 离开图纸 | 离开图纸 / Leave Sheet | `Alt+Back` |
| 上一层 | — | `Alt+Up` |
| 上一页 / 下一页 | — | `PgUp` / `PgDn` |
| 后退 / 前进 | — | `Alt+Left` / `Alt+Right` |

### 4.4 常见错误

- **层次标签与图纸引脚不同名**：看起来连了，实际断开
- **在子图里用全局标签代替层次标签**：能连通但破坏了模块封装性，子图无法复用
- **同一个子图文件被多个图纸符号引用**：这是 KiCad 支持的复用特性，但会共享同一份电路，位号需要特别处理

---

## 5. 阶段五：批注位号

### 5.1 执行批注

`工具(T) / Tools` → `批注原理图... / Annotate Schematic...`

给每个元件分配唯一位号（`R1`、`C2`、`U3`）。存在 `R?` 时无法导入 PCB。

### 5.2 批注选项

- **排序方式**：建议按 X 位置或 Y 位置排序，位号在图上分布有规律，查找方便
- **范围**：整个原理图 / 仅当前图纸
- **编号起点**：层次化设计中可以给每张子图分配不同的编号段（如电源图 100 起、射频图 200 起），一眼就能看出元件属于哪个模块

### 5.3 重新批注的风险

**PCB 已经布局布线后不要重新批注。** 位号变化会导致 PCB 里的元件与原理图对不上，更新 PCB 时可能出现大量"删除并重新添加"，布局白做。

如果必须调整，用 `从 PCB 更新原理图... / Update Schematic from PCB...` 反向同步。

---

## 6. 阶段六：分配封装

@fig:sch_dataflow 图 4　符号库 → 原理图 → 封装库 → PCB 的数据流

### 6.1 三种分配方式

1. **符号属性里直接填**：按 `F` 编辑封装字段
2. **分配封装工具**：`工具(T) / Tools` → `分配封装... / Assign Footprints...`，左侧库、中间元件、右侧候选封装，适合批量处理
3. **符号字段表**：`工具(T) / Tools` → `符号字段表 / Symbol Fields Table`，表格形式批量编辑，适合同类元件统一修改

### 6.2 核对清单

**这一步是全流程最容易埋雷的地方**，逐个核对：

- 封装的**焊盘数**与符号的**引脚数**一致
- 封装尺寸与**实际采购的元件**一致——原理图画 0402、实物买 0603，板子回来焊不上
- 连接器、插座与实物型号完全对应，注意**引脚顺序和镜像方向**
- 有极性的器件（二极管、电解电容、LED、钽电容）确认引脚 1 的位置
- 芯片封装确认是 QFN 还是 QFP、脚距对不对

### 6.3 建议做法

- 采购前就确定封装，按封装买料，而不是买完再找封装
- 自建封装必须对照数据手册的推荐焊盘图，不要凭感觉画
- 关键器件（BGA、精密连接器）打样前用 1:1 打印纸样比对实物

### 6.4 常见错误

- 封装尺寸与实物不符（最常见）
- 连接器封装镜像，导致信号全部接反
- 二极管、LED 极性反了
- 只顾着填封装名，没检查库里是否真的存在该封装

---

## 7. 阶段七：ERC 电气规则检查

`检查(I) / Inspect` → `电气规则检查 (ERC) / Electrical Rules Checker`

### 7.1 引脚类型冲突

ERC 的核心是根据引脚电气类型判断连接是否合法：

@fig:sch_erc 图 5　ERC 引脚类型冲突矩阵（常见组合）

### 7.2 必须清零的错误

| 错误 | 含义 | 处理 |
|---|---|---|
| 引脚未连接 | 有引脚悬空 | 确实不用的加无连接标志 `Q`；否则补线 |
| 输出引脚短接 | 两个输出直连 | 检查电路，改为总线或加缓冲 |
| 电源未驱动 | 电源网络没有驱动源 | 加 `PWR_FLAG` 或检查电源来源 |
| 标签只出现一次 | 网络标签只有一个引用 | 拼写错误，或漏连 |
| 层次标签无对应图纸引脚 | 父子接口不匹配 | 核对名称 |

### 7.3 关于 PWR_FLAG

电源来自连接器、电池、稳压器输出时，这些引脚往往被标为"无源"或"输出"，ERC 认为该网络"没有电源驱动"而报错。

在该网络上放一个 `PWR_FLAG` 符号即可——它相当于告诉 ERC "我确认这里有电源"。

**不要滥用**：如果到处贴 PWR_FLAG 来消除错误，等于关掉了电源检查。

### 7.4 哪些可以忽略

- 明确不使用的引脚（已加 `Q` 标志的）
- 测试点、预留焊盘
- 某些库符号自带的隐藏电源引脚警告

忽略之前要逐条确认，不要为了让 ERC 变绿而批量忽略。

### 7.5 完成判据

ERC 错误为 0；所有警告已逐条确认是可接受的。

---

## 8. 阶段八：输出

### 8.1 更新到 PCB

`工具(T) / Tools` → `从原理图更新 PCB... / Update PCB from Schematic...`

这是原理图与 PCB 之间的唯一同步通道。每次改完原理图都要执行一次。

### 8.2 物料清单

`工具(T) / Tools` → `生成物料清单... / Generate Bill of Materials...`

导出前确认每个元件的关键字段完整：数值、封装、型号、供应商编号。缺字段的 BOM 采购时要返工。

### 8.3 导出网表

`文件(F) / File` → `导出网表... / Export Netlist...`

只在需要给第三方 PCB 工具使用时才需要。KiCad 内部同步用"从原理图更新 PCB"即可，不需要手工导出网表。

### 8.4 输出 PDF

`文件(F) / File` → `绘制 / Plot`，格式选 PDF。用于评审、归档、发给同事。层次化设计会输出为多页 PDF。

---

## 9. 常用快捷键速查

| 分类 | 操作 | 快捷键 |
|---|---|---|
| 放置 | 符号 / 电源符号 | `A` / `P` |
| 放置 | 导线 / 总线 / 图形线 | `W` / `B` / `I` |
| 放置 | 结点 / 无连接标志 | `J` / `Q` |
| 放置 | 网络标签 / 全局标签 / 层次标签 | `L` / `Ctrl+L` / `H` |
| 放置 | 图纸 / 文本 / 总线入口 | `S` / `T` / `Z` |
| 放置 | 重复上一次放置 | `Ins` |
| 编辑 | 属性 | `E` |
| 编辑 | 数值 / 位号 / 封装 | `V` / `U` / `F` |
| 编辑 | 移动 / 拖动（保持连线） | `M` / `G` |
| 编辑 | 旋转（逆/顺） | `R` / `Shift+R` |
| 编辑 | 水平镜像 / 垂直镜像 | `X` / `Y` |
| 编辑 | 自动摆放字段 / 交换 | `O` / `Alt+S` |
| 编辑 | 用符号编辑器编辑 | `Ctrl+E` |
| 导航 | 层次导航 | `Ctrl+H` |
| 导航 | 离开图纸 / 上一层 | `Alt+Back` / `Alt+Up` |
| 导航 | 上一页 / 下一页 | `PgUp` / `PgDn` |
| 导航 | 后退 / 前进 | `Alt+Left` / `Alt+Right` |
| 网络 | 高亮 / 清除高亮 | `` ` `` / `~` |
| 网络 | 下一个 / 上一个网络项 | `Tab` / `Shift+Tab` |
| 连线 | 切换朝向 / 撤销上一段 | `/` / `Backspace` |

---

## 10. 本项目检查清单

CORE 底板原理图：73 个元件，主要接口为 8 路 SMA 射频输入、`ZYNQ7010&7020_CB` 核心板座、HR911131A 网口、USB-C、两路差分时钟。

| 检查项 | 状态 |
|---|---|
| 按功能层次化拆分（电源 / 射频 / 核心板 / 通信） | 待确认 |
| 差分网络成对命名 `_P` / `_N` | 待确认 |
| 8 路 SMA 通道电路一致，位号规律编号 | 待确认 |
| 核心板座引脚号与实物完全对应 | 待确认 |
| HR911131A 网口变压器引脚与数据手册核对 | 待确认 |
| USB-C 接口 CC 电阻、ESD 器件齐全 | 待确认 |
| 每个芯片电源引脚都有去耦电容 | 待确认 |
| 电源网络已加 PWR_FLAG | 待确认 |
| 未使用引脚全部加无连接标志 `Q` | 待确认 |
| 所有元件封装与实际采购件核对 | 待确认 |
| ERC 错误清零 | 待确认 |

---

## 相关文档

- 《KiCad PCB 设计流程》——原理图完成后的 PCB 阶段
- 《KiCad 传输线计算器使用说明》——阻抗线宽计算
- 《KiCad 差分对走线阻抗设计说明》——差分阻抗概念
- 《XC7Z020 PL 侧时钟引脚说明》——时钟引脚选型

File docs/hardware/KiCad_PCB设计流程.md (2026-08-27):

# KiCad PCB 设计流程

本文按实际执行顺序，梳理 KiCad 从原理图收尾到输出制造文件的完整 PCB 设计流程。

> 环境：KiCad 10.0.4，简体中文界面。界面项以「中文 / English」成对给出；标注 `[英文]` 的表示该处界面显示的就是英文原文（官方中文翻译未覆盖）。快捷键取自本机实际配置。

---

## 0. 流程总览

@fig:flow 图 1　PCB 设计十阶段与返工代价

| 阶段 | 主要工作 | 完成标志 | 返工代价 |
|---|---|---|---|
| 一 | 开工前决策 | 层数、板厂、板框尺寸确定 | **极高**，推翻重来 |
| 二 | 原理图收尾 | ERC 无错误，封装全部分配 | 高 |
| 三 | 电路板配置 | 叠层、设计规则、网络类填写完毕 | **高**，已布线全部失效 |
| 四 | 从原理图更新 PCB | 元件全部导入，无封装错误 | 低 |
| 五 | 板框与结构 | Edge.Cuts 闭合，安装孔与接口定位 | 高 |
| 六 | 布局 | 器件摆放完成并锁定 | **高**，布线全废 |
| 七 | 布线 | 全部网络连通，阻抗线达标 | 中 |
| 八 | 铺铜与回流 | 平面完整，缝合过孔布置 | 低 |
| 九 | 检查 | DRC 零错误，目视清单通过 | — |
| 十 | 制造输出 | Gerber、钻孔、位置文件、BOM | 低 |

核心原则：**越难改的越先定。** 上表中"返工代价"高的阶段，必须在进入下一阶段前彻底确认。

新手最常见的失败模式是**跳过阶段一到三直接开始摆件布线**，等到布了一半才发现层数不够、线宽不对、叠层没定，此时前面的工作几乎全部作废。

---

## 1. 阶段一：开工前的决策

这一阶段不碰 KiCad，但决定后面所有工作。

### 1.1 层数与叠层

**这是最不可逆的决策。** 判断依据：

- 有 BGA、大量高速信号、需要阻抗控制 → **至少四层**
- 只有低速数字和电源 → 两层可行
- 高密度 BGA、多组差分总线 → 六层及以上

四层板的标准分配：**信号 - GND - 电源 - 信号**。中间的完整 GND 平面是所有高速信号的参考层，价值远超省下的板费。

@fig:stackup 图 2　四层板 1.6 mm 叠层剖面（嘉立创 JLC04161H-7628）

注意图中标红的 **H**：F.Cu 层走线的参考平面是紧邻的 In1.Cu，两者间距只有 0.2104 mm。这个值决定了外层走线的阻抗，也是后面计算线宽时唯一该填进 `H` 的数。

### 1.2 向板厂索取工艺参数

下单前需要拿到：

- 叠层结构表（各层厚度、Dk、Df、铜厚）
- 最小线宽/线距、最小过孔、最小焊环
- 阻抗计算器或阻抗表

嘉立创四层板（1oz 外层）的关键限值：最小线宽/线距 **0.09/0.09 mm**，最小过孔 **0.15/0.25 mm**，线宽公差 **±20%**，阻抗公差 **±10%**。

### 1.3 列出阻抗需求清单

把所有需要控制阻抗的网络列出来，逐条确定目标值。这份清单在阶段三要填进网络类。

### 1.4 确定板框与结构约束

外壳尺寸、安装孔位置、连接器朝向、限高区域。这些由结构决定，PCB 必须服从。

### 1.5 常见错误

- **为省钱选两层板**，结果高速信号没有完整参考平面，调试阶段耗掉的时间远超省下的板费
- **没问板厂就自己假设叠层参数**，算出的线宽与实际阻抗对不上
- **板框尺寸等结构确认后再说**，导致布局返工

---

## 2. 阶段二：原理图收尾

### 2.1 差分对网络命名

**必须在画 PCB 之前做对。** KiCad 靠网络名后缀识别差分对：

- 成对命名为 `xxx_P` / `xxx_N`，或 `xxx+` / `xxx-`
- 命名不匹配的话，PCB 里按差分对布线快捷键 `6` 不会进入差分模式

### 2.2 批注原理图

`工具(T) / Tools` → `批注原理图... / Annotate Schematic...`

给所有元件分配唯一位号。存在 `R?`、`C?` 这类未批注元件时无法导入 PCB。

### 2.3 分配封装

`工具(T) / Tools` → `分配封装... / Assign Footprints...`

**这一步最容易埋雷。** 逐个核对：

- 封装的引脚数与符号一致
- 封装尺寸与实际采购的元件一致（0402 还是 0603）
- 连接器、插座的封装要与实物型号完全对应
- 有极性的器件（二极管、电解电容、LED）确认引脚顺序

### 2.4 电气规则检查

`检查(I) / Inspect` → `电气规则检查 (ERC) / Electrical Rules Checker`

必须清零的错误：引脚未连接、输出引脚短接、电源未驱动。可以忽略的：明确知道悬空的测试点、未使用的引脚（应加"未连接"标记）。

### 2.5 常见错误

- **封装选错尺寸**：原理图画 0402、实物买 0603，板子回来焊不上
- **连接器封装引脚顺序反了**：镜像错误，插上去信号全串
- **ERC 报错直接忽略**：未驱动的电源网络往往意味着真的漏连了
- **差分网络名不成对**：`CLK_P` 配 `CLK_M`，KiCad 认不出来

### 2.6 完成判据

ERC 零错误；所有元件有唯一位号和已验证的封装。

---

## 3. 阶段三：电路板配置

`文件(F) / File` → `电路板配置 / Board Setup`

**这一阶段的所有设置必须在布线之前定死。** 布完线再改，已有走线会全部违规甚至需要重布。

### 3.1 物理叠层

左侧 `电路板堆叠 / Board Stackup` → `物理叠层 / Physical Stackup`

1. `铜层 / Copper Layers` 选择层数
2. 逐层填写厚度、材料、`Epsilon R`、`Loss Tan`——**用板厂给的实际值，不要用 KiCad 默认值**
3. 确认底部 `电路板叠层厚度 / Board Thickness` 符合目标
4. 需要板厂做阻抗测试时，勾选 `阻抗控制 / Impedance controlled`

> 注意：叠层表里那一列中文叫「线宽」，实际是英文的 **Thickness（厚度）**，与走线宽度无关。这是中文翻译不准确。

### 3.2 板层编辑器

`板层编辑器 / Board Editor Layers`

给内层改名并设置类型，例如 `In1.Cu` 改名 `GND`（类型选电源层）、`In2.Cu` 改名 `PWR`。层类型不影响电气，但布线时不容易点错层。

### 3.3 约束

`设计规则 / Design Rules` → `约束 [Constraints]`

按板厂工艺能力填写全局最小值：最小线宽、最小间距、最小过孔内外径、最小焊环、最小孔间距。同时确认**盲埋孔保持禁用**（四层板用通孔即可，开盲埋孔打样价格翻数倍）。

### 3.4 网络类

`设计规则 / Design Rules` → `网络类 / Net Classes`

按用途建立独立网络类，把阶段一的阻抗清单填进来：

| 网络类 | 走线宽度 / Track Width | Diff Pair Width | 差分对间隙 / Diff Pair Gap |
|---|---|---|---|
| `Default` | 0.2 mm | — | — |
| `POWER` | 0.5~1 mm（按电流） | — | — |
| `RF_50R` | 阻抗计算结果 | — | — |
| `CLK_DIFF` | — | 阻抗计算结果 | 阻抗计算结果 |
| `USB_DIFF` | — | 阻抗计算结果 | 阻抗计算结果 |

线宽从叠层参数算出，各参数的物理含义如下图：

@fig:microstrip 图 3　微带线截面与 KiCad 计算器参数对应

详细算法见《KiCad 传输线计算器使用说明》。

### 3.5 泪滴

`设计规则 / Design Rules` → `泪滴 / Teardrops`

**此时先不要开启。** 泪滴会让走线的选择和拖动变得别扭，应在布线全部完成后再加。

### 3.6 违规严重级别

`设计规则 / Design Rules` → `违规严重级别 / Violation Severity`

把确实要管的规则设为错误，明确不管的设为忽略。目的是让后期 DRC 的输出干净可读，不被噪声淹没。

### 3.7 常见错误

- **沿用 KiCad 默认叠层参数**（εr = 4.5、介质 0.1 mm）去算线宽，与实际板厂叠层差一倍
- **把 H 填成板厚 1.6 mm**，算出的线宽宽到离谱
- **布完线才改网络类线宽**：已布走线不会自动更新，需要全部重布
- **改了 `Diff Pair Gap` 以为差分对会自动更新**：不会，已布的差分对保持旧间距，DRC 也未必报错
- **一上来就开泪滴**，整个布线过程被拖慢

### 3.8 完成判据

叠层参数与板厂一致；所有阻抗网络的线宽/间距已填入对应网络类；约束值不超出板厂工艺能力。

---

## 4. 阶段四：从原理图更新 PCB

在 PCB 编辑器中：`工具(T) / Tools` → `从原理图更新 PCB... / Update PCB from Schematic...`

### 4.1 检查导入结果

对话框会列出将要执行的操作。重点看：

- **封装缺失**：符号未分配封装，或封装库路径失效
- **引脚数不匹配**：符号 5 个引脚、封装 4 个焊盘之类
- **意外的删除操作**：说明原理图和 PCB 的位号对不上

有错误就回原理图修正，不要强行导入。

### 4.2 后续每次修改原理图

改完原理图都要重新执行一次这个操作，PCB 才会同步。反向操作是 `从 PCB 更新原理图... / Update Schematic from PCB...`，一般只在 PCB 里调整了引脚交换时才用。

### 4.3 常见错误

- **看到一堆"删除元件"仍然点确定**：位号对不上时会把已布好的部分清掉
- **改完原理图忘了更新 PCB**：板子按旧网表布线，回来发现连错

---

## 5. 阶段五：板框与结构

### 5.1 绘制板框

选中 `Edge.Cuts` 层，用 `放置(P) / Place` 里的绘制工具画板框。

要点：

- 板框必须**完全闭合**，不能有断点或重叠线段，否则无法生成外形
- 圆角用圆弧，不要用多段折线近似
- 板框尺寸以结构图为准

### 5.2 安装孔与结构件

- 安装孔按结构图精确定位，用带焊盘的孔（金属化）还是无铜孔（非金属化）要明确
- 定位孔、螺柱避让区先摆上
- 板边连接器（本项目的 SMA、USB-C、RJ45）位置由结构决定，**先摆并锁定**

### 5.3 规则域

`规则域 / Rule Area`（旧称 Keepout Area）用于定义禁布区，例如：

- 天线下方禁止铺铜
- 网口变压器隔离带禁止铺铜
- 螺柱周围禁止走线

### 5.4 3D 核对

`视图(V) / View` → `3D 查看器 / 3D Viewer`（`Alt+3`）

在布局前先看一次 3D，确认板框、安装孔、板边接口的位置和朝向正确。

### 5.5 常见错误

- **板框没闭合**：Gerber 出来没有外形，板厂无法加工
- **板框用折线拟合圆角**：锣边不平滑，且尺寸有误差
- **安装孔忘了设为非金属化**：螺丝导通到 GND 造成意外短路
- **板边器件距板框太近**：走线和焊盘距板边需 ≥ 0.2 mm，V 割处 ≥ 0.4 mm

---

## 6. 阶段六：布局

**布局决定 70% 的成败。布局没定死，绝不进入布线。**

@fig:layout 图 4　CORE 底板布局分区示意

### 6.1 布局顺序

1. **结构约束件**：板边连接器、安装孔、指示灯、按键——位置由外壳决定，摆完立即 `锁定 / Lock`
2. **主芯片**：核心板座、主控、FPGA，决定整板走线走向
3. **去耦电容**：紧贴对应芯片的电源引脚，越近越好
4. **电源模块**：稳压器、电感、大电容，注意大电流路径短而宽
5. **晶振与时钟源**：紧靠使用它的芯片，远离干扰源
6. **接口相关器件**：网口变压器、ESD 器件、共模电感，靠近对应接口
7. **其余小器件**：上下拉电阻、滤波电容等，随后填空

### 6.2 三条布局原则

**就近原则**：有电气关联的器件放在一起。去耦电容到电源引脚的环路面积必须最小。

**分区原则**：模拟区、数字区、电源区、射频区物理分开。本项目的 SMA 射频前端应与数字部分明确分区。

**信号流向原则**：按信号从输入到输出的顺序排列器件，避免信号来回穿越板面。

### 6.3 常用操作

| 操作 | 快捷键 |
|---|---|
| 移动 / Move | `M` |
| 单独移动（不带走线）/ Move Individually | `Ctrl+M` |
| 逆时针旋转 / Rotate | `R` |
| 顺时针旋转 | `Shift+R` |
| 翻转到另一面 / Flip | `F` |
| 属性 / Properties | `E` |
| 缩放到适合屏幕 | `Home` |

摆好位置的器件及时**锁定**，避免后续误拖动。

### 6.4 常见错误

- **去耦电容摆得离芯片很远**，中间还隔着过孔——等于没有去耦
- **射频区和数字区混在一起**，射频底噪被数字开关噪声淹没
- **晶振旁边走高速线或放开关电源**，时钟被干扰
- **只看平面不看 3D**，元件高度冲突或连接器朝向反了
- **布局没锁定**，布线过程中不小心拖动了器件

### 6.5 完成判据

所有器件摆放到位并锁定；3D 视图确认无干涉；分区清晰；去耦电容全部贴紧电源引脚。

---

## 7. 阶段七：布线

### 7.1 布线优先级

**越敏感、越难改的越先走。** 不要按原理图顺序或从左到右布。

@fig:priority 图 5　布线优先级阶梯

关键在于：优先级 3、4 类信号一旦被普通信号挤占空间就再也走不出干净路径，而 LED、按键这类线无论多晚布都能绕过去。

### 7.2 布线操作

| 操作 | 中文 / English | 快捷键 |
|---|---|---|
| 单端布线 | 布线(单端) / Route Single Track | `X` |
| 差分对布线 | 布线(差分) / Route Differential Pair | `6` |
| 放置过孔 | Add Via | `V` |
| 切换拐角朝向 | Switch Posture | `/` |
| 45° 圆弧拐角 | — | `Ctrl+Shift+W` |
| 90° 圆弧拐角 | — | `Alt+W` |
| 循环切换拐角模式 | — | `Ctrl+/` |
| 撤销上一段 | — | `Backspace` |
| 45° 拖动 | — | `D` |
| 自由角度拖动 | — | `G` |
| 切换上一层/下一层 | — | `+` / `-` |
| 高亮网络 | 高亮网络 / Highlight Net | `` ` `` |
| 清除高亮 | — | `~` |
| 走线显示模式（实心/线框） | — | `K` |

### 7.3 布线要点

- **参考平面完整性优先于走线美观**。高速线下方的 GND 平面不能有割缝。
- **换层要谨慎**。信号换层意味着回流路径也要换层，必须在换层过孔附近放 GND 缝合过孔。
- **差分对严格对称**，对内 skew 尽量小。
- **90° 直角拐弯避免**，用 45° 或圆弧。
- **差分对上尽量不串联元件**。若必须串（如调试跳线），两个元件必须并排、同朝向、同 X 坐标，且焊盘下方参考平面挖空。

### 7.4 等长调整

全部走线完成后再做，中途改线会毁掉蛇形线。

| 操作 | 快捷键 |
|---|---|
| 单端走线等长 / Tune Single Track | `7` |
| 差分对等长 / Tune Differential Pair | `8` |
| 差分对 skew / Tune Diff Pair Skew | `9` |
| 蛇形线间距增大/减小 | `1` / `2` |
| 蛇形线幅度增大/减小 | `3` / `4` |

**对内等长优先于对间等长。** 对内 skew 一般控制在 5 mil 以内。

### 7.5 常见错误

- **先布简单的信号**，把好路径占光，关键信号只能绕远
- **高速线跨越平面割缝**，DRC 不会报错但阻抗和 EMC 全毁
- **差分对中途分开绕行**，耦合中断
- **换层过孔附近没有 GND 回流过孔**
- **等长做完又改布线**，蛇形线全部作废

---

## 8. 阶段八：铺铜与回流

### 8.1 为什么参考平面不能割断

@fig:refplane 图 6　参考平面完整与被割断时的回流路径对比

高频回流电流总是沿信号线正下方的最短路径返回。平面上的任何割缝都会迫使回流绕行，同时造成阻抗突变、辐射增加和串扰。这是 In1.Cu 上不允许走任何信号线的根本原因。

### 8.2 内层平面

选中内层，用 `放置(P) / Place` → 填充区域（`Ctrl+Shift+Z`）沿板框画一圈：

- **GND 层保持完整，不做任何分割**
- 电源层按供电域划分区域，各区域间留足间距

### 8.3 顶底层铺铜

顶底层大面积铺 GND 铜有助于散热和屏蔽。注意：

- 铺铜网络设为 GND
- 多个铺铜区重叠时，`Priority level` 高的先填充并挖掉低优先级的——优先级设错会导致铜皮互相吞掉
- 网口变压器隔离带、天线区域用规则域挖空

### 8.4 缝合过孔

在板边、大面积铜皮、高速信号换层处布置 GND 缝合过孔，把各层地平面连成一体。间距一般取最高频率波长的 1/20 以下。

### 8.5 填充与更新

| 操作 | 中文 / English | 快捷键 |
|---|---|---|
| 填充所有铺铜区 | 填充所有填充区 / Fill All Zones | `B` |
| 取消填充所有铺铜区 | 取消填充所有填充区 / Unfill All Zones | `Ctrl+B` |
| 画铺铜区 | Add Filled Zone | `Ctrl+Shift+Z` |
| 铺铜挖空 | Zone Cutout | `Shift+C` |

**每次改动走线后都要按 `B` 重新填充**，否则铺铜显示的是旧状态。

### 8.6 焊盘连接方式

`Zone Properties` 里的 `Pad connection` 决定焊盘与铜皮的连接：

- `缓释热焊盘 (花焊盘) / Thermal relief`：默认，便于手工焊接
- `实心 / Solid`：导热导电最好，但手焊困难，适合大电流和散热焊盘

### 8.7 常见错误

- **在 GND 平面层上走信号线**，把平面切得七零八落
- **铺铜优先级设错**，电源铜皮被 GND 铜皮吞掉
- **改完线忘记按 `B` 重新填充**，看到的是旧铺铜
- **孤岛铜皮没清理**，形成天线
- **大电流焊盘用了花焊盘**，散热和载流不足

---

## 9. 阶段九：检查

### 9.1 设计规则检查

`检查(I) / Inspect` → `设计规则检查 / Design Rules Checker`

运行前务必勾选 **`Refill all zones before DRC`**（DRC 前重新填充所有铺铜），否则检查的是旧的铺铜状态。

必须清零的项目：

- `Violations`：间距、线宽、过孔等规则违规
- `Unconnected Items`：未连接的网络——**这一项必须为 0**
- `原理图一致性检验 / Schematic Parity`：PCB 与原理图不一致
- `Footprint Warnings`：封装本身的问题

### 9.2 目视检查清单

**DRC 通过不代表设计正确。** 以下问题 DRC 一律查不出来，必须人工检查：

- 高速线下方的参考平面是否被割断
- 差分对是否全程保持等距
- 去耦电容是否真的靠近了电源引脚
- 大电流路径是否足够宽
- 晶振周围是否有干扰源
- 丝印是否被焊盘覆盖、位号是否可读
- 板边器件是否距板框足够远
- 极性器件的丝印标记是否正确
- 测试点是否预留且可探针接触

### 9.3 3D 检视

`Alt+3` 打开 `3D 查看器 / 3D Viewer`，检查元件干涉、连接器朝向、高度限制、板边对齐。

常用视角：`Z` 顶视、`Shift+Z` 底视、`Y` 前视、`X` 右视、`Home` 复位。

### 9.4 电路板统计报告

`检查(I) / Inspect` → `电路板统计报告 / Board Statistics`

核对元件总数、过孔数、板子面积，与预期比对，能发现意外遗漏。

---

## 10. 阶段十：制造输出

`文件(F) / File` → `制造输出 / Fabrication Outputs`

### 10.1 需要输出的文件

| 文件 | 菜单项 | 用途 |
|---|---|---|
| Gerber | `绘制... / Plot...` | 各层图形数据 |
| 钻孔文件 | `生成钻孔文件... / Generate Drill Files...` | 孔位与孔径 |
| 位置文件 | `Generate Position File...` | SMT 贴片坐标 |
| BOM | 原理图端 `生成物料清单... / Generate Bill of Materials...` | 采购与贴片 |

### 10.2 Gerber 输出要点

绘制对话框中需要勾选的层，至少包括：

- 所有铜层（`F.Cu`、`In1.Cu`、`In2.Cu`、`B.Cu`）
- 阻焊层 `F.Mask`、`B.Mask`
- 丝印层 `F.Silkscreen`、`B.Silkscreen`
- 锡膏层 `F.Paste`、`B.Paste`（需要钢网时）
- 板框 `Edge.Cuts`

格式选 **Gerber X2** 或按板厂要求。多数国内板厂接受 RS-274X。

### 10.3 送厂前自查

- 用 KiCad 自带的 **Gerber 查看器（GerbView）** 打开输出的文件，逐层确认无误
- 确认钻孔文件的单位和格式与板厂要求一致
- 打包时把叠层要求、阻抗要求写进说明文件一并提交
- 阻抗控制板需在下单时明确标注（通常是收费项）

### 10.4 常见错误

- **没用 GerbView 检查就直接下单**：漏层、丝印错位等问题到板子回来才发现
- **忘了勾选 Edge.Cuts**：板厂拿不到外形
- **阻抗要求只写在心里**：板厂按普通板生产，阻抗不受控
- **位置文件的原点与板厂要求不一致**：贴片坐标全错

---

## 11. 常用快捷键速查

| 分类 | 操作 | 快捷键 |
|---|---|---|
| 编辑 | 移动 / 单独移动 | `M` / `Ctrl+M` |
| 编辑 | 旋转（逆/顺时针） | `R` / `Shift+R` |
| 编辑 | 翻转到另一面 | `F` |
| 编辑 | 属性 | `E` |
| 视图 | 缩放到适合屏幕 | `Home` |
| 视图 | 切换上/下一层 | `+` / `-` |
| 视图 | 3D 查看器 | `Alt+3` |
| 视图 | 走线显示模式 | `K` |
| 布线 | 单端 / 差分 | `X` / `6` |
| 布线 | 放置过孔 | `V` |
| 布线 | 拐角朝向 / 循环拐角模式 | `/` / `Ctrl+/` |
| 布线 | 45° 圆弧 / 90° 圆弧 | `Ctrl+Shift+W` / `Alt+W` |
| 布线 | 撤销上一段 | `Backspace` |
| 布线 | 45° 拖动 / 自由角度拖动 | `D` / `G` |
| 等长 | 单端 / 差分 / 差分 skew | `7` / `8` / `9` |
| 铺铜 | 画铺铜区 / 挖空 | `Ctrl+Shift+Z` / `Shift+C` |
| 铺铜 | 填充全部 / 取消填充全部 | `B` / `Ctrl+B` |
| 网络 | 高亮 / 清除高亮 | `` ` `` / `~` |

---

## 12. 本项目执行清单

CORE 底板：四层、1.6 mm、外层 1oz、内层 0.5oz、73 个元件。

主要接口：8 路 SMA 射频输入、`ZYNQ7010&7020_CB` 核心板座、HR911131A 网口、USB-C、两路差分时钟（312.5 MHz / 350 MHz）。

| 检查项 | 状态 |
|---|---|
| 叠层参数按板厂实际值填写 | 待确认 |
| In1.Cu 设为完整 GND 平面 | 待完成 |
| 阻抗线宽计算并填入网络类 | 待完成 |
| 8 路 SMA 射频通道优先布线，50Ω 控制 | 待完成 |
| 差分时钟短、直、下方 GND 完整 | 待完成 |
| 网口变压器隔离带铺铜挖空 | 待完成 |
| USB-C D+/D- 按 90Ω 差分布线 | 待完成 |
| 射频区与数字区物理分区 | 待完成 |
| DRC 未连接项清零 | 待完成 |
| Gerber 用 GerbView 逐层核对 | 待完成 |

关键提醒：**所有阻抗控制线走 F.Cu，以 In1.Cu 完整地平面为参考。In1.Cu 上不允许有任何分割或走线**，否则参考平面不连续，阻抗设计全部失效。

---

## 相关文档

- 《KiCad 传输线计算器使用说明》——50Ω 单端与 100Ω 差分线宽的具体算法
- 《KiCad 差分对走线阻抗设计说明》——差分阻抗概念与常见误区
- 《XC7Z020 PL 侧时钟引脚说明》——时钟引脚选型与核实方法

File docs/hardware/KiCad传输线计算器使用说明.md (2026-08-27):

# KiCad 传输线计算器使用说明

本文说明如何用 KiCad 自带的计算工具，计算 50Ω 单端微带线和 100Ω 差分对的线宽与间距。

> 环境：KiCad 10.0.4，简体中文界面。全文界面项以「中文 / English」成对给出，中文为界面实际显示文字，英文为原版术语，便于对照英文资料与网络教程。

---

## 1. 前提条件

计算之前必须先拿到**板厂的叠层参数**。阻抗完全由叠层决定，没有叠层数据算出来的结果没有意义。

需要向板厂索取的四个数：

- 信号层到参考层的**介质厚度**（填入 `H`）
- 该介质的**相对介电常数 Dk**（填入 `εr`）
- 该介质的**损耗角正切 Df**（填入 `tan δ`）
- **成品铜厚**（填入 `T`），外层通常 1oz = 0.035 mm，内层默认 0.5oz = 0.0152 mm

本文以嘉立创 1.6 mm 四层标准叠层 `JLC04161H-7628` 为例。

---

## 2. 打开计算工具

三种入口，任选其一：

1. PCB 编辑器菜单：`工具(T) / Tools` → `计算工具 / Calculator Tools`
2. KiCad 项目管理器主界面的计算器图标
3. 直接运行 `<KiCad安装目录>\bin\pcb_calculator.exe`

窗口标题为「**计算工具 / Calculator Tools**」，菜单栏为 `文件(F) / File`、`设置(S) / Preferences`、`帮助(H) / Help`。

---

## 3. 找到传输线页面

KiCad 10.0 的计算工具用**左侧导航树**组织功能，不是标签页。完整结构如下：

| 分组（中文 / English） | 子项 |
|---|---|
| 通用系统设计 / General System Design | 稳压器 / Regulators，电阻计算器 / Resistor Calculator |
| 电源，电流和隔离 / Power, Current & Isolation | 电气间距 / Electrical Spacing，过孔外径 / Via Size，走线宽度 / Track Width，熔断电流 / Fusing Current，线缆尺寸 / Cable Size |
| **高速 / High Speed** | 波长 / Wavelength，RF 衰减器 / RF Attenuators，**传输线 / Transmission Lines** |
| 备忘录 / Memo | E 系列 / E-Series，色环电阻 / Color Code，电路板类别 / Board Classes，电偶腐蚀 / Galvanic Corrosion |

**点击 `高速 / High Speed` → `传输线 / Transmission Lines`。**

> 注意区分：左侧还有一个 `走线宽度 / Track Width`，那是按**载流能力**（IPC-2221 温升）算线宽的，与阻抗无关。算阻抗必须用 `传输线 / Transmission Lines`。

---

## 4. 传输线类型 / Transmission Line Type

页面左侧第一栏，9 个单选项。**选错类型结果完全不对。**

| 中文 | English | 适用场景 |
|---|---|---|
| **微带线** | **Microstrip Line** | **外层单端线**（F.Cu / B.Cu），下方有参考平面 |
| **耦合微带线** | **Coupled Microstrip Line** | **外层差分对** |
| 带状线 | Stripline | 内层单端线，上下都有参考平面 |
| 耦合带状线 | Coupled Stripline | 内层差分对 |
| 共面波导 | Coplanar wave guide | 两侧有地铜，下方无参考平面 |
| 共面波导与接地层 | Coplanar wave guide w/ ground plane | 两侧有地铜且下方有参考平面 |
| 矩形波导 | Rectangular Waveguide | 微波波导，PCB 不用 |
| 同轴线 | Coaxial Line | 同轴电缆 |
| 双绞线 | Twisted Pair | 双绞线缆 |

选择原则：**走线在外层用微带线，走线在内层用带状线。** 本项目的射频输入与差分时钟都走 F.Cu，因此用微带线 / 耦合微带线。

---

## 5. 页面的五个区域

| 区域（中文 / English） | 作用 |
|---|---|
| 传输线类型 / Transmission Line Type | 选择线型 |
| 基板参数 / Substrate Parameters | 叠层与材料，**输入** |
| 元件参数 / Component Parameters | 工作频率 |
| 物理参数 / Physical Parameters | 线宽 W、长度 L（差分对还有间距 S） |
| 电气参数 / Electrical Parameters | 特性阻抗 Z0、电长度 Ang_l |
| 结果 / Results | 有效介电常数、时延、损耗等派生量 |

中间两个按钮决定计算方向：

| 按钮 | English | 方向 | 何时用 |
|---|---|---|---|
| **分析** | **Analyze** | 物理参数 → 电气参数 | 已知线宽求阻抗（**验算**） |
| **合成** | **Synthesize** | 电气参数 → 物理参数 | 已知目标阻抗求线宽（**主要用这个**） |

按钮旁的向下 / 向上箭头指示的就是这个数据流向。

---

## 6. 基板参数逐项说明

界面上用的是**符号**，不是全称。对照如下：

| 界面符号 | 中文含义 / English | 填什么 | 本例值 |
|---|---|---|---|
| `εr` | 相对介电常数 / Epsilon R | 介质 Dk | `4.4` |
| `tan δ` | 损耗角正切 / Tan delta | 介质 Df | `0.02` |
| `ρ` | 导体电阻率 / Conductor resistivity | 铜，保持默认 | `1.72e-08` Ω·m |
| `H` | 底材高度 / Height of substrate | **信号层到参考层的介质厚度** | `0.2104` mm |
| `H(top)` | 顶部空间高度 / Height of box top | 走线上方空间 | 保持 `1e+20` |
| `T` | 铜层厚度 / Strip thickness | 成品铜厚 | `0.035` mm |
| `粗糙度` | 导体粗糙度 / Conductor roughness | 铜箔粗糙度 | `0`（或板厂给值） |
| `μr (基质)` | 基板相对磁导率 / mu Rel S | 保持默认 | `1` |
| `μr (导体)` | 导体相对磁导率 / mu Rel C | 保持默认 | `1` |

### 6.1 两个最容易填错的值

**`H` 填的是介质厚度，不是板厚。** 四层板上 F.Cu 走线的参考层是 In1.Cu，所以填 F.Cu 与 In1.Cu 之间的 prepreg 厚度（本例 0.2104 mm）。**填成 1.6 mm 是最常见的错误**，会得到宽得离谱的线宽。

**`H(top)` 必须保持默认的 `1e+20`。** 微带线上方是空气，没有金属盖板，这个极大值表示"上方无限远处才有边界"。若误填成板厚，等于告诉计算器上方有个金属盖，算出来会明显偏离。

### 6.2 KiCad 默认值需要改

打开时 `εr` 默认是 **4.5**（通用 FR4 值）。如果按嘉立创 7628 prepreg，应改为 **4.4**；其他板厂以其提供的数据为准。这个值直接影响结果，不要沿用默认值就开算。

---

## 7. 元件参数：频率的作用

`频率 / Frequency` 默认 `10 MHz`。

**这个值不影响线宽计算**，但影响：

- `结果 / Results` 里的导体损耗、介电损耗、趋肤深度
- 通过 `Ang_l` 换算出的线长 `L`

要看损耗数据时，把它改成信号的实际工作频率（本项目差分时钟填 `350` MHz）。只算线宽的话可以不管。

---

## 8. 计算 50Ω 单端微带线

### 8.1 操作步骤

1. `传输线类型` 选 **`微带线 / Microstrip Line`**
2. 按第 6 节填写**基板参数**
3. 在**电气参数 / Electrical Parameters** 区，`Z0` 填 **`50`**，单位选 `Ω`
4. 点击 **`合成 / Synthesize`**
5. 在**物理参数 / Physical Parameters** 区读 `W`，这就是 50Ω 线宽

### 8.2 实测示例

用 KiCad 默认 `εr = 4.5`、`H = 0.2 mm`、`T = 0.035 mm`、`粗糙度 = 0`、`Z0 = 50 Ω` 合成，得到：

| 输出项 | 数值 |
|---|---|
| `W`（线宽） | **0.355568 mm**（14.0 mil） |
| 有效 εr / Effective εr | 3.15527 |
| 单位传播时延 / Unit Propagation Delay | 59.4083 ps/cm |
| 导体损耗 / Conductor Losses | 1.25637 dB |
| 介电损耗 / Dielectric Losses | 0.137116 dB |
| 趋肤深度 / Skin Depth | 20.873 μm |

改成嘉立创实际参数（`εr = 4.4`、`H = 0.2104`）后重算，W 会略微变宽，落在 0.36~0.40 mm 区间属正常。

**量级判断**：50Ω 外层微带线的线宽通常是介质厚度的 1.8~2 倍。如果算出 0.1 mm 或 1 mm 这种量级，一定是 `H` 填错了。

### 8.3 关于 `L` 和 `Ang_l`

物理参数里的 `L` 常常显示一个巨大的数（例如 4828 mm），这**不是错误**：

- `Ang_l` 是**电长度 / Electrical length**，单位 rad
- `L` 由 `Ang_l` 和 `频率` 共同换算而来
- 10 MHz 下 1.8 rad 对应的物理长度确实是几米

**算线宽时完全不用管 `L` 和 `Ang_l`**，它们不影响 `W`。只有在做延迟线、匹配枝节这类应用时才需要。

---

## 9. 计算 100Ω 差分对

### 9.1 选择类型

`传输线类型` 选 **`耦合微带线 / Coupled Microstrip Line`**。基板参数与单端完全相同，不需要改。

选中后**物理参数区会多出间距 `S`**，电气参数区变成 `Zodd` 和 `Zeven`。

### 9.2 关键换算：Zdiff 与 Zodd

KiCad 用**奇模阻抗 Zodd** 和**偶模阻抗 Zeven** 描述差分对，而设计规范给的是**差分阻抗 Zdiff**。换算关系：

```
Zdiff   = 2 x Zodd
Zcommon = Zeven / 2
```

所以：

- **100Ω 差分 → `Zodd` 填 `50`**
- 90Ω 差分（USB 2.0）→ `Zodd` 填 `45`

### 9.3 Zeven 需要迭代

这是 KiCad 计算器最不好用的地方：它要求**同时**给出 `Zodd` 和 `Zeven`，但设计时通常只知道 Zdiff 一个数。

实用做法：

1. `Zodd` 填 `50`
2. `Zeven` 先填估计值，紧耦合外层微带线典型在 60~70 之间，先填 `65`
3. 点 `合成 / Synthesize`，得到 `W` 和 `S`
4. 检查 `S` 是否落在工艺允许且合理的范围（一般与 `W` 同量级）
5. 若 `S` 过大或过小，调整 `Zeven` 重算

**`Zeven` 恒大于 `Zodd`**，两者差距越大表示耦合越强。若算出 `Zeven` 小于 `Zodd`，说明填反了。

### 9.4 中文翻译陷阱（重要）

KiCad 10.0 简体中文版的**鼠标悬停提示存在翻译错误**：

| 位置 | 原文 | 中文翻译 | 是否正确 |
|---|---|---|---|
| 字段标签 | `Zodd` | Zodd (奇模阻抗) | 正确 |
| 字段标签 | `Zeven` | Zeven (偶模阻抗) | 正确 |
| 悬停提示 | Odd mode impedance (...differential voltages) | 奇模阻抗 (通过驱动线相反 (差分) 电压) | 正确 |
| 悬停提示 | Even mode impedance (lines driven by common voltages) | **奇模阻抗** (由通用电压的线路驱动) | **错误，应为"偶模"** |

两个字段的悬停提示都写着"奇模阻抗"，极易让人把 `Zeven` 和 `Zodd` 填反。

**以字段标签为准，不要看悬停提示。** 记忆方法：`Zodd` 对应差分（两线反相驱动），`Zeven` 对应共模（两线同相驱动），且 `Zeven` 永远更大。

### 9.5 读取结果

- `W` → 填入 KiCad 的 `Diff Pair Width`（差分对单根线宽）
- `S` → 填入 KiCad 的 `差分对间隙 / Diff Pair Gap`

---

## 10. 把结果填回设计规则

`文件(F) / File` → `电路板配置 / Board Setup` → `设计规则 / Design Rules` → `网络类 / Net Classes`

| 计算结果 | 填入字段（中文 / English） |
|---|---|
| 50Ω 单端线宽 W | 走线宽度 / Track Width |
| 差分对单根线宽 W | Diff Pair Width |
| 差分对间距 S | 差分对间隙 / Diff Pair Gap |

建议按用途建立独立网络类，例如 `RF_50R`、`CLK_DIFF`、`ETH_DIFF`、`USB_DIFF`，各自填写对应参数。

---

## 11. 验算

线宽取整后（例如把 0.3556 取整成 0.35 或 0.4），阻抗会变化，需要反向确认：

1. 传输线类型与基板参数保持不变
2. 在**物理参数**区把 `W` 改成实际打算用的值
3. 点 **`分析 / Analyze`**
4. 读**电气参数**区的 `Z0`，确认仍在目标值 ±10% 以内

嘉立创的阻抗公差就是 ±10%，所以设计值本身应尽量落在中心。

---

## 12. 顺带能用上的两个派生量

`结果 / Results` 区里有两个值在布线阶段很实用：

**单位传播时延 / Unit Propagation Delay**（示例 59.4083 ps/cm）

用来算等长和延迟：本例外层微带线上信号速度约 16.8 cm/ns。做对内 skew 匹配时，5 ps 的偏差对应约 0.84 mm 的长度差——这个数能帮你判断等长要做到多精细。

**趋肤深度 / Skin Depth**（示例 20.873 μm）

当趋肤深度远小于铜厚（35 μm）时，电流只在导体表面流动，此时铜箔粗糙度开始显著影响损耗。高频下应向板厂索取实际粗糙度值填入 `粗糙度` 字段。

---

## 13. 局限性

KiCad 传输线计算器适合设计阶段的估算与验证，但有几点必须清楚：

- **不计入阻焊层**。实际阻焊油墨会使外层微带线阻抗降低约 2~5Ω，KiCad 结果偏高。
- **不计入玻纤编织效应**。FR4 玻纤布不均匀造成的阻抗波动，对高速差分对影响明显。
- **差分部分需手工迭代 `Zeven`**，不如板厂计算器直接输入 Zdiff 方便。
- **不知道板厂的蚀刻补偿和叠层公差**。

因此：

> **KiCad 计算器用于理解参数关系和快速估算，最终线宽以板厂阻抗计算器的输出为准。**

嘉立创的阻抗计算工具可直接输入目标差分阻抗，并同时给出推荐叠层，下单时以它的结果更稳妥。

---

## 14. 本项目参考配置

CORE 底板：四层、1.6 mm 板厚、外层 1oz、内层 0.5oz。

| 信号 | 目标阻抗 | 传输线类型 | 走线层 | 参考层 |
|---|---|---|---|---|
| SMA 射频输入 | 50Ω 单端 | 微带线 | F.Cu | In1.Cu (GND) |
| 差分时钟 `clk_fs_p` / `clk_fx_p` | 100Ω 差分 | 耦合微带线 | F.Cu | In1.Cu (GND) |
| 以太网差分对 | 100Ω 差分 | 耦合微带线 | F.Cu | In1.Cu (GND) |
| USB-C `D+/D-` | 90Ω 差分 | 耦合微带线 | F.Cu | In1.Cu (GND) |

所有阻抗控制线走 F.Cu，以 In1.Cu 完整地平面为参考。**In1.Cu 上不允许有任何分割或走线**，否则参考平面不连续，上述计算全部失效。

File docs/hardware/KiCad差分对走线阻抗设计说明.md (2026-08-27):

# KiCad 差分对走线阻抗设计说明

差分线是否要走 50Ω 微带线？

> 结论：**不是。** 差分线要按"差分阻抗（Zdiff）"设计，而不是按 50Ω 单端阻抗设计。

---

## 1. 概念区分

| 线型 | 目标阻抗 | 典型用途 |
|---|---|---|
| 单端微带线 | 50Ω（射频常用），一般 40~60Ω | 时钟、单端高速信号、RF |
| 差分对 | 差分阻抗 Zdiff = 90Ω / 100Ω 等 | USB、以太网、HDMI、MIPI、LVDS |

### 常见接口的差分阻抗规范

| 接口 | 差分阻抗 Zdiff | 容差 |
|---|---|---|
| USB 2.0（D+/D-） | 90Ω | ±10% |
| USB 3.x / PCIe / SATA | 100Ω | ±10% |
| HDMI / Ethernet | 100Ω | ±10% |
| MIPI D-PHY | 100Ω | ±10% |
| LVDS | 100Ω | ±10% |

---

## 2. 为什么不能直接"每根走 50Ω"

差分阻抗与单端阻抗的关系为：

```
Zdiff = 2 x Z0 x (1 - k)
```

其中 Z0 为单根线的单端阻抗，k 为两根线之间的耦合系数。

- 若两线**间距很大**（弱耦合，k → 0）：Zdiff ≈ 2 × 50 = 100Ω，此时"每根 50Ω"确实近似成立；
- 但差分对通常是**紧耦合**布线（线间距 ≈ 线宽），k 明显不为 0。若仍照搬单端 50Ω 的线宽与间距，Zdiff 会掉到 80~90Ω，无法满足 100Ω ±10% 的要求。

正确做法：**使用差分阻抗计算器，同时解出线宽 W 与线间距 S**，而不是先算 50Ω 单端阻抗再照抄线宽。

---

## 3. KiCad 中的具体操作流程

1. **先向板厂索取叠层表**（层间介质厚度、介电常数 Dk、铜厚、阻焊厚度）。阻抗完全由叠层决定，没有叠层信息就无法计算。
2. 用 KiCad 自带的 `工具(T) / Tools` → `计算工具 / Calculator Tools` → `高速 / High Speed` → `传输线 / Transmission Lines`，或板厂提供的阻抗计算表 / Saturn PCB Toolkit / Polar SI9000，算出 W 与 S。
3. 在 `电路板配置 / Board Setup` → `设计规则 / Design Rules` → `网络类 / Net Classes` 中为差分网络设置 `Track Width`、`Diff Pair Width`、`差分对间隙 / Diff Pair Gap` 以及 `Diff Pair Via Gap`。
4. 使用**差分对布线工具**（快捷键 `6`）走线，再用 `布线(U) / Route` → `Tune Differential Pair Skew`（快捷键 `9`）完成对内等长调整。

---

## 4. 实践中的注意事项

- **必须有完整的参考平面。** 差分对正下方的 GND 平面不能有割缝，跨分割会同时破坏阻抗连续性和回流路径。
- **对内等长优先于对间等长。** 对内 skew 一般控制在 5 mil 以内；USB 2.0 可放宽至约 50 mil，但越小越好。
- **短走线可以不做严格阻抗控制。** 若 USB 2.0 走线仅 2~3 cm 且为低速/全速，阻抗失配的影响通常可以接受；但 USB HS（480 Mbps）及以上建议严格执行。
- **两层板做不好阻抗控制。** 1.6 mm FR4 两层板要做 90Ω 差分，线宽会非常宽且耦合很差。高速差分建议至少四层板（信号 - GND - 电源 - 信号）。

---

说明：具体的 W/S 数值依赖实际叠层参数，需针对本项目的接口类型与板层数单独计算后填入。计算方法见《KiCad 传输线计算器使用说明》。

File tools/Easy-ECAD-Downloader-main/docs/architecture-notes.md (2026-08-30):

# Architecture Notes

This file records short implementation notes that supplement, but do not replace, [systemDesign.md](../systemDesign.md).

## Layer boundaries

- `src/content_script.js`: DOM inspection and provider-aware part-context detection only
- `src/popup.js`: popup UI state, preview requests, Firefox SamacSys relay gating, settings-page launch, and export requests
- `src/settings_page.js`: persistent download layout plus session-first SamacSys auth settings and Firefox-only advanced helper settings
- `src/service_worker.js`: thin runtime entrypoint only
- `src/service_worker_runtime.js`: provider routing, runtime gating, response shaping, and composition of worker dependencies
- `src/core/*.js`: shared worker business logic for settings, downloads, storage-backed symbol-library handling, shared export artifact writing, and common normalization
- `src/sources/*.js`: source adapters plus source-specific fetch/parse/export helpers
  - `src/sources/samacsys_distributor_adapter.js` is the shared backend adapter for Mouser, Farnell, element14, and Newark
- `src/sources/samacsys_common.js` holds the shared SamacSys preview, ZIP, relay-cookie, relay-auth, upstream-auth, direct-request ZIP-auth fallback, and asset-rewrite helpers
- `src/kicad_converter.js`: stable public converter facade
- `src/kicad/*.js`: EasyEDA parsing, KiCad text generation, shared conversion math, and OBJ-to-WRL conversion
- `src/vendor/zip_reader.js`: minimal runtime ZIP extraction for SamacSys archives

## Testability notes

- `src/kicad_converter.js` should stay the stable facade for converter tests, while pure conversion details live under `src/kicad/`.
- `src/content_script.js` should stay small and DOM-driven so it can be exercised with markup fixtures.
- `src/popup.js` should keep browser messaging and DOM updates visible enough to test with mocked `chrome.*` APIs.
- `src/service_worker_runtime.js` should hold browser-dependent orchestration, with tests using mocks instead of browser-run end-to-end flows.
- Source-specific helpers should be testable directly without exposing router internals just for test coverage.

## Current implementation caveats worth preserving

- The popup does not fetch, extract, or convert CAD assets directly; it only requests that work.
- The runtime/router owns provider branching, while source adapters own source-specific preview and export behavior.
- Farnell, element14, and Newark do not have their own backend adapter files because they intentionally reuse the shared SamacSys distributor backend.
- Symbol library append behavior depends on `chrome.storage.local`, not on local filesystem reads.
- Library-mode download paths remain relative to Downloads and are resolved from extension settings, not absolute filesystem paths.
- EasyEDA footprints are written after 3D export attempts so their KiCad `(model ...)` path can match the artifact that was actually downloaded, or be stripped when no model artifact was produced.
- EasyEDA WRL conversion keeps OBJ geometry centered in X/Y and bottom-aligned in Z; the footprint model offset is emitted in KiCad 3D units rather than footprint millimetres.
- SamacSys distributor support is still Chrome-first, but Firefox can opt into a user-managed relay through the advanced Firefox settings menu.
- Chrome direct SamacSys ZIP export now retries once with configured upstream auth after a `401`, but preview requests still use the normal direct browser session without preemptive auth headers.
- Firefox relay mode forwards matching `componentsearchengine.com` cookies so authenticated SamacSys ZIP downloads can reuse the browser session instead of teaching the relay to log in.
- Firefox relay mode can also generate the upstream SamacSys HTTP Basic auth header locally from optional username/password credentials.
- Optional helper tokens and SamacSys passwords are session-only by default; the settings page requires explicit opt-in before remembering them in browser local storage.
- Relay auth and upstream SamacSys auth are separate: relay auth is sent only on the Worker POST, while upstream auth is forwarded inside the relay payload.
- SamacSys ZIP-export `401` responses are mapped to a sign-in-required error because upstream authentication can be stricter for downloads than for previews.
- SamacSys ZIP extraction treats `KiCad/` and `3D/` directories as valid whether they appear at the archive root or under a part-specific parent folder.
- The current repository is intentionally compact; add new sources through focused adapters or distributor detection changes rather than introducing a broader application framework.
- The manifest intentionally declares both `background.service_worker` and `background.scripts` so Chrome can run the service worker while Firefox falls back to a background document on Firefox 121+.

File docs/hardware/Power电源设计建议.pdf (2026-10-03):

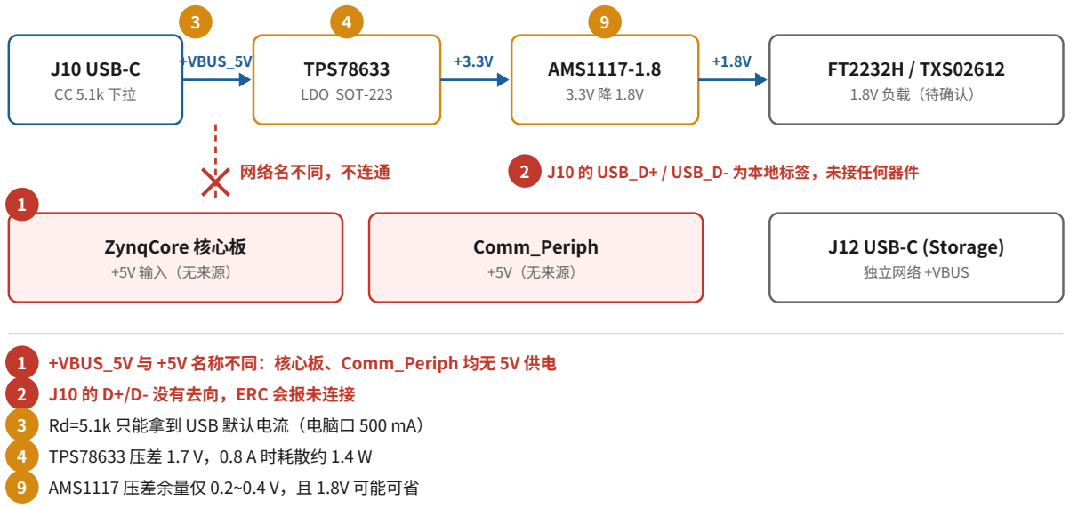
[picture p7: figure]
J10 USB-C; +VBUS_5V; TPS78633; LDO SOT-223; AMS1117-1.8; FT2232H / TXS02612; 1.8V 负载（待确认）; 网络名不同，不连通; ZynqCore 核心板; +5V 输入（无来源）; Comm_Periph; +5V（无来源）; 2 J10 的 USB_D+ / USB_D- 为本地标签，未接任何器件; J12 USB-C (Storage); 独立网络 +VBUS; 2 J10 的 D+/D- 没有去向，ERC 会报未连接; 3 Rd=5.1k 只能拿到 USB 默认电流（电脑口 500 mA）; 4 TPS78633 压差 1.7 V，0.8 A 时耗散约 1.4 W; 9 AMS1117 压差余量仅 0.2~0.4 V，且 1.8V 可能可省

CORE 项目 · 硬件设计文档 | 第 1 页

# Power 电源设计建议

CORE 项目 · 硬件设计文档

针对 hardware/schematic/v1.0/CORE/Power.kicad_sch 的审查结果。第 1、2 条是原理图错误，不改上不了电；其余为设计改进。

1 +VBUS_5V 与 +5V 名称不同：核心板、Comm_Periph 均无 5V 供电

图 1 当前电源网络与问题位置

## 一、必须修改

问题 | 依据 | 建议
1. 核心板 +5V 没有电 源来源 | Power 页输出叫 +VBUS_5V，ZynqCore 页（核心板 5V 输入）和 Comm_Periph 页叫 +5V。KiCad 按电源符号 Value 区分网络，两者不连通 | 统一网络名，或用 0Ω / 磁珠把 +VBUS_5V 接到 +5V
2. USB_D+ / USB_D-无去向 | Power 页的本地标签，其他页没有同名网络 | J10 只供电：D+/D- 打 NC、删标签。要接 PS 端 USB OTG：改层次标签接到核心板

（Storage 页 FT2232H 的 J12 电源网络叫 +VBUS，是第三个独立网络；若只用于 VBUS 检测则没问题，需确认。）

## 二、供电能力不够

问题 | 说明 | 建议
3. Rd=5.1k 只能拿到 USB 默认电流 | 接电脑 USB 2.0 口仅 500 mA（2.5 W）。7020 核心板 + DDR3 + 千兆 PHY + LCD + 底板外设满载约 3~5 W | 加 DC 圆座（5V/3A）做主电源，与 VBUS 二极管 OR；或明确要求 5V/3A Type-C 适配器
4. TPS78633 散热 | 压差 1.7 V，0.8 A 时耗散 约 1.4 W；SOT-223 热阻约 50~60 °C/W，温升 70~80 °C | 先估算底板 3.3V 电流，超过 0.5 A 换同步 Buck（TPS62130 / SY8089）；否则 TAB 下铺铜加散热过孔

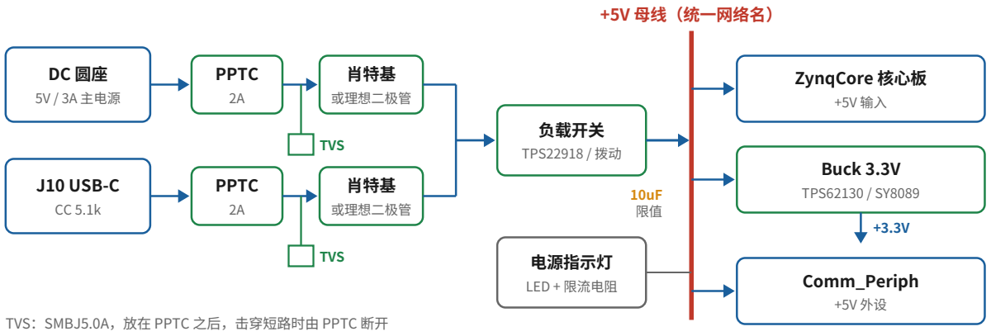
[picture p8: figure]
5V / 3A 主电源; J10 USB-C; PPTC; 肖特基; 或理想二极管; TVS; TVS：SMBJ5.0A，放在 PPTC 之后，击穿短路时由 PPTC 断开; 负载开关; TPS22918 / 拨动; +5V 母线（统一网络名）; ZynqCore 核心板; Buck 3.3V; TPS62130 / SY8089; Comm_Periph; 电源指示灯; LED + 限流电阻

CORE 项目 · 硬件设计文档 | 第 2 页

## 三、保护与可靠性

问题 | 建议
5. VBUS 入口无保护 | 串 PPTC（2A）→ TVS（SMBJ5.0A）→ 防反接（PMOS 或肖特基）
6. VBUS 电容总量约 20 µF | USB 规范要求 ≤10 µF，否则插入浪涌可能触发电脑口过流保护。入口留 10 µF + 100 nF，大电容放到开关之后
7. 无电源开关、无指示灯 | 加拨动开关或负载开关（TPS22918），加一颗电源 LED
8. SHIELD 直接接 GND | 可用；重视 EMC/ESD 时改 1 MΩ ∥ 4.7 nF 接地

## 四、1.8V 支路

问题 | 建议
9. AMS1117-1.8 压差仅 1.5 V | 典型压差 1.1~1.3 V，大电流余量不足；负载几十 mA 可接受
10. 1.8V 是否需要 | FT2232HL 自带 1.8V 片内 LDO（VREGOUT）。若只给 FT2232H 用，AMS1117 可整个去掉；TXS02612 等也需要则换 ME6211-1.8 / RT9013-18
11. AMS1117 输出电容稳定性 | 老款要求一定 ESR（手册推荐 22 µF 钽电容），全陶瓷可能振荡；换钽电容或换陶瓷稳定型 LDO

（TPS78633 外围正确：EN 经 0Ω 接 IN，NR 10 nF，输出 10 µF 陶瓷，均符合手册。）

## 五、修改后拓扑

图 2 建议的电源路径（绿色为新增器件；只用 USB 供电时可省去 DC 圆座一路，但须用 5V/3A 适配器；1.8V 支路见第四节）

优先级 | 修改项 | 涉及文件
立即 | +VBUS_5V 与 +5V 统一；处理 USB_D± | Power、ZynqCore
高 | 确认整板功耗，决定是否加 DC 圆座、3.3V 是否换 Buck | Power
中 | PPTC + TVS + 防反接，VBUS 电容 ≤10 µF，开关与 LED | Power
低 | 1.8V 支路精简或换 LDO | Power、Storage

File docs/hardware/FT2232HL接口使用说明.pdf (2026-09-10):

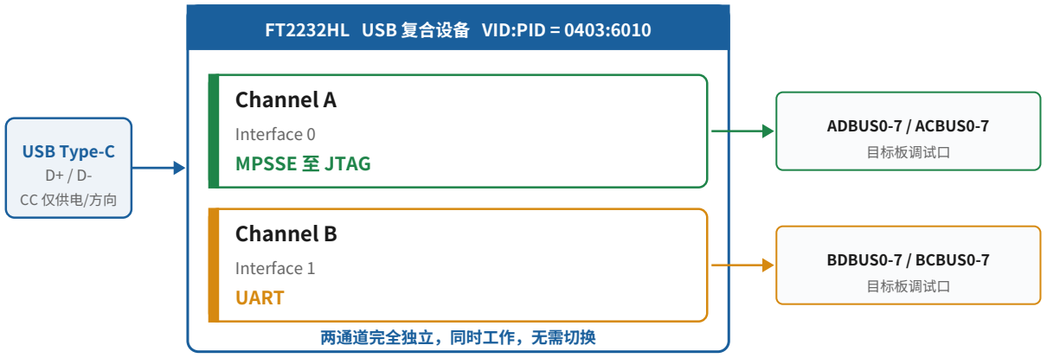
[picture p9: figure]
USB Type-C; CC 仅供电/方向; FT2232HL USB 复合设备 VID:PID = 0403:6010; Channel A; Interface 0; MPSSE 至 JTAG; ADBUS0-7 / ACBUS0-7; 目标板调试口; Channel B; Interface 1; UART; BDBUS0-7 / BCBUS0-7; 两通道完全独立，同时工作，无需切换

CORE 项目 · 硬件设计文档 | 第 1 页

# FT2232HL 接口使用说明

CORE 项目 · 调试桥接口设计

本文说明 FT2232HL 在 CORE 板上作为调试桥的用法：双通道如何分配、JTAG 与 UART 如何共存、主机端如何识别、配置 EEPROM 如何接线与量产烧录。

适用范围：FT2232HL（LQFP-64），配置 EEPROM 为 93LC56BT-I/OT。文中 x 代表通道字母，A 通道引脚为 ADBUS/ACBUS，B 通道为 BDBUS/BCBUS。

## 0. 总览

主机端枚举结果（EEPROM 按建议配置后）

Channel A | D2XX 驱动 | 不产生 COM 口，OpenOCD / flashrom 独占
Channel B | VCP 驱动 | Windows: COM 口　Linux: /dev/ttyUSB0

识别靠 USB Interface 号，与 Type-C 接口本身无关；A 恒为 Interface 0。
图 1 双通道架构与主机端枚举关系

FT2232HL 是一颗 USB 复合设备：一个 USB 口、一组 VID:PID（默认 0403:6010），下挂 两个完全独立的 USB Interface，各驱动一个通道引擎。

这带来本文最重要的一个结论：

JTAG 和 UART 不需要"切换"，让 Channel A 跑 JTAG、Channel B 跑 UART，两者同时在线。

绝大多数商用调试器（FT2232H Mini Module、Digilent HS2、Olimex ARM-USB-OCD）都是这个方案。只有在引脚实在不够、被迫让一个通道兼两职时，才会遇到切换问题（见第 4 节）。

## 1. 支持的全部通讯模式

每个通道可独立配置为下列任一模式：

模式 | 可用通道 | 最高速率 | 用途
UART / RS232 | A、B | 12 Mbaud | 串口，带 RTS/CTS、DTR/DSR 硬件流控

CORE 项目 · 硬件设计文档 | 第 2 页
模式 | 可用通道 | 最高速率 | 用途
MPSSE 之 JTAG | A、B | 30 MHz | 芯片调试
MPSSE 之 SPI | A、B | 30 MHz | 仅 Master，支持模式 0/1/2/3
MPSSE 之 I2C | A、B | 约 400 kHz | 软件模拟，有硬件前提，见第 6 节
异步 Bit-Bang | A、B | 约 1 MB/s | 8 位 GPIO 直接读写
同步 Bit-Bang | A、B | — | 时钟驱动的 GPIO
异步 245 FIFO | A、B | 8 MB/s | 8 位并口
同步 245 FIFO | 仅 A | 40 MB/s | FPGA 高速数据流
CPU-FIFO（同步/异步） | A、B | — | 模拟 CPU 总线，带地址线
Fast Opto-Isolated Serial | A、B | — | 光隔离串行

### 1.1 一条硬限制

同步 245 FIFO 会让整颗芯片进入单通道状态，启用后 Channel B 完全不可用。

如果需要"40 MB/s 高速口 + 独立串口"的组合，FT2232HL 做不到，应改用 FT600/FT601，或另加一颗 FT232。

### 1.2 不支持的

- SPI Slave：只能做主机
- CAN / LIN 协议层：RS485 可外挂收发器，用 RTS 或 TXDEN 引脚控方向
- USB Host：本芯片只能作为 USB device
- 硬件 I2C 控制器：I2C 是 MPSSE 模拟出来的

## 2. 推荐的通道分配

方案 | Channel A | Channel B | 说明
调试板标配 | MPSSE 之 JTAG | UART | 最常用，两者同时可用
带 Flash 烧录 | MPSSE（JTAG / SPI 运行时切） | UART | 用 flashrom 直烧板载 SPI Flash，省一个编程器

第二种方案之所以成立，是因为 JTAG 与 SPI 的引脚天然对应：TCK 即 SCK、TDI 即 MOSI、TDO 即 MISO，硬件走线不用动，只有片选 CS# 需要单独安排（占用 TMS 那根线，或改用某个 GPIOL 引脚）。

flashrom 原生支持本芯片作 SPI 编程器：

flashrom -p ft2232_spi:type=2232H,port=A -w firmware.bin

## 3. 引脚复用对照

CORE 项目 · 硬件设计文档 | 第 3 页
UART | MPSSE / JTAG | MPSSE / SPI | MPSSE / I2C
xD0 | TXD | TCK | SCK | SCL
xD1 | RXD | TDI | MOSI | SDA (out)
xD2 | RTS# | TDO | MISO | SDA (in)
xD3 | CTS# | TMS | CS# | —
xD4-7 | DTR#/DSR#/DCD#/RI# | GPIOL0-3 | GPIOL0-3 | GPIOL0-3
xCBUS0-7 | — | GPIOH0-7 | GPIOH0-7 | GPIOH0-7

xD0-xD3 是复用冲突区：同一通道换模式，外部走线也必须跟着换。
x 代表 A（Channel A）或 B（Channel B）。xD4-7 与 xCBUS 在 MPSSE 下恒为 GPIO。
图 2 同一组数据引脚在四种模式下的功能

图 2 中红框标出的 xD0 至 xD3 是复用冲突区。这四根线在不同模式下含义完全不同，所以同一通道换模式时， 外部走线也必须跟着换，否则会出现 JTAG 的 TCK 直接怼到目标板串口 RX 上这类硬件冲突。

xD4 至 xD7 与 xCBUS0 至 xCBUS7 在 MPSSE 下恒为通用 GPIO（GPIOL0-3 / GPIOH0-7），可自由用作复位、片选、LED 指示等。

## 4. 同一通道内切换模式

只在被迫共用一个通道时才需要这一节。 优先用第 2 节的分通道方案。

### 4.1 MPSSE 不是 EEPROM 选项

这是最容易误解的一点：EEPROM 里只能选 RS232 UART 或 245 FIFO，没有 MPSSE 这个选项。

MPSSE 是运行时通过 D2XX 命令进入的：

FT_SetBitMode(h, 0x00, FT_BITMODE_RESET); | // 0x00 -> back to UART
FT_SetBitMode(h, 0x00, FT_BITMODE_MPSSE); | // 0x02 -> enter MPSSE (JTAG/SPI/I2C)

完整流程：关闭串口应用 → FT_Open → FT_SetBitMode(MPSSE) → 执行 JTAG 操作 → 用完 FT_BITMODE_RESET 退回 UART。

### 4.2 驱动占用问题

同一个通道不能同时被 VCP 和 D2XX 打开，这是切换时最常卡住的地方。

Windows：VCP 驱动把通道枚举成 COM 口后，D2XX 抢不到。用 FT_PROG 把该通道的 Driver 从 Virtual COM Port 改成 D2XX Direct，重新插拔生效。

Linux：ftdi_sio 会自动绑定，OpenOCD 打不开。先解绑：

echo -n "1-1.2:1.0" | sudo tee /sys/bus/usb/drivers/ftdi_sio/unbind

其中 :1.0 是 Channel A，:1.1 是 Channel B，具体总线编号用 lsusb -t 查。

按第 8 节的建议把 A 通道 EEPROM 配成 D2XX，这一步就可以省掉。

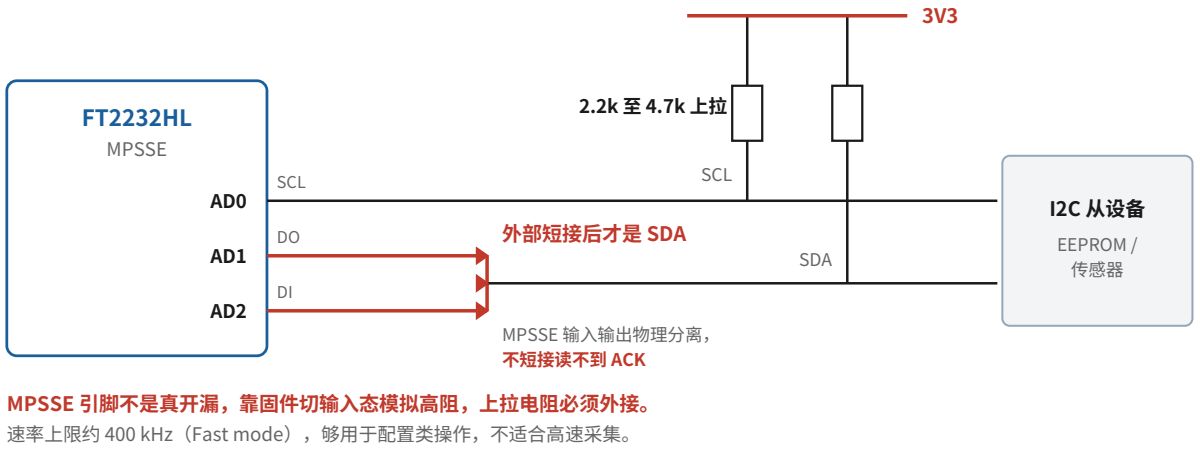
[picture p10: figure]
MPSSE; SCL; 外部短接后才是 SDA; MPSSE 输入输出物理分离， 不短接读不到 ACK; SDA; I2C 从设备; EEPROM / 传感器; MPSSE 引脚不是真开漏，靠固件切输入态模拟高阻，上拉电阻必须外接。; 速率上限约 400 kHz（Fast mode），够用于配置类操作，不适合高速采集。

CORE 项目 · 硬件设计文档 | 第 4 页

## 5. 主机端如何识别 JTAG 与 UART

### 5.1 Type-C 接口本身不参与识别

Type-C 只是 USB 的物理载体。CC 引脚负责插入检测、正反插方向、供电能力广播（Rp/Rd）以及 DP/TBT 这类 Alt Mode 协商，没有"这个口是 JTAG 还是 UART"的语义，也不该有 —— 正反插必须功能一致。

板子作为纯 UFP 时，CC1/CC2 各接一个 5.1 kΩ 下拉到 GND 即可。不要试图用 CC 状态去切 JTAG/UART，那是滥用协议。

### 5.2 识别发生在 USB 枚举层

项目 | Channel A | Channel B
USB Interface | 0 | 1
默认描述符 | Dual RS232-HS A | Dual RS232-HS B
Linux 设备节点 | /dev/ttyUSB0 | /dev/ttyUSB1
Linux 稳定路径 | /dev/serial/by-id/...-i f00-port0 | ...-if01-port0
Windows | USB Serial Converter A | USB Serial Converter B

枚举顺序是固定的，A 恒为 Interface 0，不会因插拔顺序改变。

生产上不要依赖 ttyUSB0 这种会随插拔顺序变化的名字，用 by-id 路径或序列号定位。

### 5.3 让设备自我标识

按第 8 节配置后，OpenOCD 可以精确锁定目标：

ftdi vid_pid 0x0403 0x6010
ftdi device_desc "CORE Debug A"
ftdi serial "CORE001"
ftdi channel 0

ftdi channel 的取值：0 为 Channel A，1 为 Channel B。

## 6. I2C 的两个硬件前提

CORE 项目 · 硬件设计文档 | 第 5 页

图 3 MPSSE 做 I2C 时的外部接线要求

MPSSE 的 I2C 是模拟出来的，必须满足两个外部条件，否则完全不工作：

1. xD1 与 xD2 必须外部短接成一根 SDA。 MPSSE 的输入与输出引脚物理分离，不短接就读不到从机的 ACK。
2. SCL 与 SDA 都要外接 2.2 kΩ 至 4.7 kΩ 上拉。 MPSSE
引脚不是真开漏，靠固件把引脚切成输入态来模拟高阻态，没有上拉就没有高电平。

结论：I2C 能用但别扭。做产线烧录 EEPROM、读配置芯片够用；做高速传感器采集不合适，速率上限约 400 kHz。

## 7. 配置 EEPROM 的接线

FT2232HL | 93LC56BT-I/OT 2 Kbit　128 x 16　SOT-23-6
EECS | CS
EECLK | CLK
EEDATA | DI

2.2k

DO

TP

必须串 2.2k 电阻：DI/DO 合并成一根线，防双向驱动冲突。
TP 为救砖测试点：短接到 GND 可让芯片忽略 EEPROM，回退默认值重新枚举。 必须用 B 版（x16 组织）。93LC56A 是 x8 组织，FT2232H 读不了。 出厂空白（全 0xFF）时芯片回退片内默认值照常枚举，可直接用 FT_PROG 烧录。

图 4 93LC56B 接法与救砖测试点

FT2232H | 93LC56B | 备注
EECS | CS | 直连
EECLK | CLK | 直连
EEDATA | DI | 直连
EEDATA | DO | 必须串 2.2 kΩ

### 2.2 kΩ 不能省。 FT2232H 把 DI 与 DO 合并到一根 EEDATA 线上，靠这个电阻避免双向驱动冲突。FTDI

官方参考设计（FT2232H 数据手册典型应用电路、AN_113）即为此接法。

### 7.1 选型注意

- 必须用 B 版。93LC56B 是固定 128 x 16（x16 组织），FT2232H 只认这种；93LC56A 是 x8 组织，不能用。
- SOT-23-6（后缀 OT）封装的 ORG 引脚不引出，内部固定为 x16，正合适。
- 引脚编号请对照 Microchip 数据手册的 OT 封装图确认，不要照搬 SOIC-8 的顺序。
- 工作电压 2.5 V 至 5.5 V，与 FT2232H 的 3.3 V EEPROM 接口兼容。

### 7.2 留一个救砖测试点

布板时给 EEPROM 的 CS 引脚留一个测试点。 一旦写错 VID/PID 导致设备无法枚举，把 CS（或 DO）临时短接到 GND，FT2232H 读不到有效 EEPROM 就会回退片内默认值重新枚举；此时松开短接，用 FT_PROG 的 Erase 擦掉重烧即可。

CORE 项目 · 硬件设计文档 | 第 6 页

有这个测试点，能省掉一次返修。

## 8. 出厂配置与量产烧录

### 8.1 先澄清一个概念

FT_PROG 是运行在 PC 上的 Windows 上位机软件，不是芯片里的东西。 它通过 USB 与 FT2232H 通信，由 FT2232H 代为读写旁边的 EEPROM。

93LC56BT-I/OT 出厂是空白的（全 0xFF），不含任何 FTDI 配置数据，Microchip 出厂只做电性测试。

### 8.2 空白 EEPROM 时的行为

芯片检测到 EEPROM 空白（或根本没挂 EEPROM）时，会回退到片内固化默认值，照样能枚举：

项目 | 空白 EEPROM 时的默认值
VID:PID | 0403:6010
Product Description | Dual RS232-HS
Serial Number | 无，所有板子都一样
Channel A / B 模式 | 都是 UART + VCP

所以首件焊好后直接插 USB 就能被 FT_PROG 认到并烧录，不需要预烧 EEPROM。代价是没有序列号、没有自定义描述符、JTAG 通道会被 VCP 驱动抢走。

### 8.3 CORE 板建议配置

配置项 | 值 | 理由
VID:PID | 保持 0403:6010 | 省掉自签驱动的麻烦
Product Description | CORE Debug | 设备管理器里一眼可辨
Serial Number | CORE + 自动递增 | 多板同插时可区分
Channel A Driver | D2XX Direct | JTAG 通道，不产生 COM 口
Channel B Driver | Virtual COM Port | UART 通道，产生 COM 口
Channel A / B Hardware | 都填 RS232 UART | MPSSE 是运行时切的，EEPROM 无此选项

这样配置后，系统里只有一个 COM 口，那必然是 UART，零歧义；ftdi_sio 也不会去抢 JTAG 通道，第 4.2 节的解绑操作可以省掉。

### 8.4 小批量烧录

1. 拿第一块板在 FT_PROG 里配好所有选项
2. File → Save As Template，存成 .xml
3. 后续板子：Devices → Scan and Parse → 载入模板 → Program

务必开启序列号自动递增：在 USB String Descriptors 里勾选 Auto Generate Serial No.，设好 Prefix（如 CORE），每次 Program 自动加一。没有唯一序列号的话，两块板同时插上就分不清了。

FT_PROG 支持一次扫描多个已连接设备并批量 Program，接 USB Hub 可以同时烧一排。

CORE 项目 · 硬件设计文档 | 第 7 页

### 8.5 产线脚本化

方案 | 平台 | 说明
ftdi_eeprom（libftdi） | Linux | 配置文件驱动，最容易接入产线脚本，推荐
D2XX FT_EEPROM_Program | 跨平台 | 自写烧录程序，可对接 MES 或序列号数据库
FT_PROG 命令行 | Windows | 3.x 版本带 CLI，参数见软件内 Help

## 9. 检查清单

投板前逐项确认：

- Channel A 与 Channel B 的用途已明确分配，未出现一个通道兼两职
- 若用 I2C：xD1 与 xD2 已外部短接，SCL/SDA 上拉电阻已放置
- EEPROM 的 DO 到 EEDATA 之间已串 2.2 kΩ
- EEPROM 型号是 93LC56B（x16），不是 93LC56A
- EEPROM CS 引脚已引出测试点
- Type-C 的 CC1/CC2 各有 5.1 kΩ 下拉到 GND
- 未使用同步 245 FIFO 模式，或已接受 Channel B 不可用的代价

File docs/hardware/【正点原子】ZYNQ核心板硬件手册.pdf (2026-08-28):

原子哥在线教学：https://www.yuanzige.com | 论坛：http://www.openedv.com/forum.php

## ZYNQ 核心板硬件手册

# ZYNQ 核心板

# 硬件手册 V1.0

# ATK-CF7010/7020S\ATK-CF7010/7020B

原子哥在线教学：https://www.yuanzige.com | 论坛：http://www.openedv.com/forum.php

## 正点原子公司名称：广州市星翼电子科技有限公司

### 公司电话：020 - 38271790

### 公司网址：www.alientek.com

### 在线教学平台：www.yuanzige.com

### 开源电子网：www.openedv.com/forum.php

### 天猫旗舰店：https://zhengdianyuanzi.tmall.com

### 正点原子 B 站：https://space.bilibili.com/394620890

## 扫码关注正点原子公众号，获取更多嵌入式学习资料

## 扫码正点原子 FPGA 公众号，获取更多 FPGA 学习资料

## 扫码关注 B 站正点原子官方，所有视频均可免费在线观看

## 扫码关注抖音正点原子，技术与娱乐结合体验双倍快乐

原子哥在线教学：https://www.yuanzige.com | 论坛：http://www.openedv.com/forum.php

# 文档更新说明

版本 | 版本更新说明 | 负责人 | 校审 | 发布日期
V1.0 | 初稿 | 正点原子 FPGA 团队 | 正点原子 FPGA 团队 | 2025.6.3

原子哥在线教学：https://www.yuanzige.com | 论坛：http://www.openedv.com/forum.php

目录

4.1 底板有对静电、信号隔离之类的要求请自行增加对应的处理避免损坏核心板....26

原子哥在线教学：https://www.yuanzige.com | 论坛：http://www.openedv.com/forum.php

### 1.1 ZYNQ 芯片

核心板使用的是 Xilinx 公司的 Zynq7000 系列的芯片，核心板有两种型号可选，主控 ZYNQ 芯片型号分别为XC7Z010CLG400与XC7Z020CLG400。芯片的PS系统集成了两个ARM Cortex-A9 处理器，以及一些内部存储器，外部存储器接口和外设。这些外设主要包括 USB 总线接口， 以太网接口，SD/SDIO 接口，GPIO，UART 接口，CAN 总线接口，I2C 总线接口，SPI 接口等。 PS 可以独立运行并在上电或复位下启动。ZYNQ7000 芯片的总体框图如下图所示：

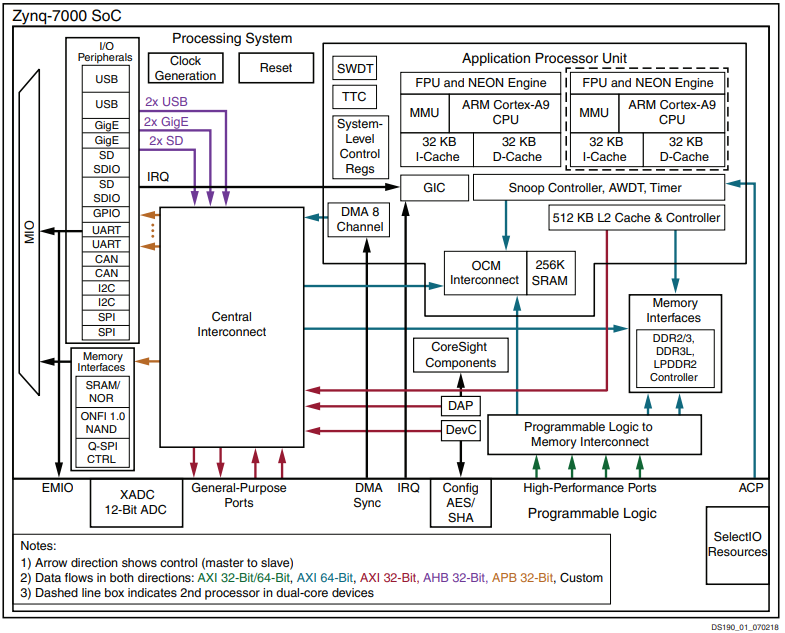
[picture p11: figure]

图 1.1.1 ZYNQ7000 芯片的总体框图
其中 PS 系统部分的主要参数如下：
（1）ARM 双核 CortexA9 的应用处理器，基于指令集 ARMv7 的 A 系列处理器架构，ZYNQ-7010 核心板双核 CortexA9 处理器最大频率为 666MHz，ZYNQ-7020 核心板双核 CortexA9 处理 器最大频率为 766MHz。
（2）每个 CPU 配备 32KB L1 级指令缓存与 32KB L1 级数据缓存，2 个 CPU 共享 512KB L2 级缓存
（3）外部存储接口，支持 16/32bit DDR2、DDR3 接口
（4）两个 10/100/1000 三模式以太网 MAC 外围设备，支持 IEEE Std 802.3 和 IEEE Std 1588 修订版 2.0
（5）两个 USB2.0 OTG 接口，每个最多支持 12 节点

原子哥在线教学：https://www.yuanzige.com | 论坛：http://www.openedv.com/forum.php
（6）两个 CAN2.0B 总线接口
（7）两个 SD 卡、SDIO、MMC 兼容控制器
（8）2 个 SPI，2 个 UART，2 个 I2C 接口
（9）54 个多功能配置的 IO，可以软件配置成普通 IO 或者外设控制接口 （10）PS 内和 PS 到 PL 的高带宽连接
其中 PL 逻辑部分的主要参数如下：
表 1.1.1 ZYNQ 核心板 7010 与 7020 的 PL 逻辑资源总结对比
FPGA 型号 | XC7Z010CLG400 | XC7Z020CLG400
逻辑单元数量（Logic Cells） | 28K | 85K
触发器数量(Flip-Flops) | 35K | 106K
查找表(LUT) | 17,600 | 53,200
乘法器数量(DSP) | 80 | 220
BLOCK RAM | 2.1Mbit | 4.9Mbit

### 1.2 核心板资源

ZYNQ 核心板板载 CPU、DDR3、QSPI FLASH、EMMC、以太网、晶振、电源、LED、USB （邮票孔独有）等硬件资源，并通过板对板连接器/邮票孔连接方式引出 IO，下图为 BTB 与邮 票孔 ZYNQ 核心板上资源的详细介绍：

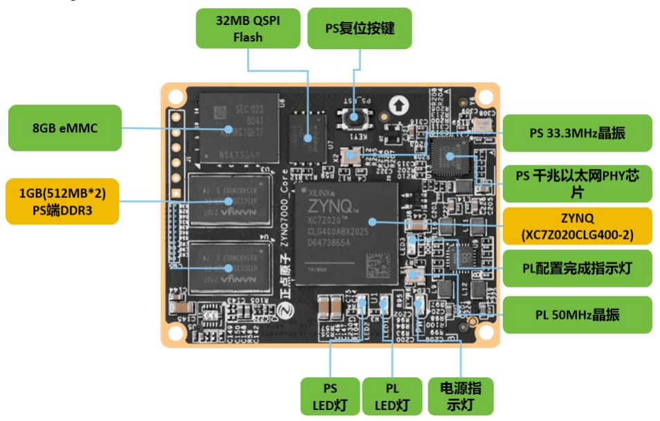
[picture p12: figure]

图 1.2.1 BTB ZYNQ-7020 核心板

原子哥在线教学：https://www.yuanzige.com | 论坛：http://www.openedv.com/forum.php

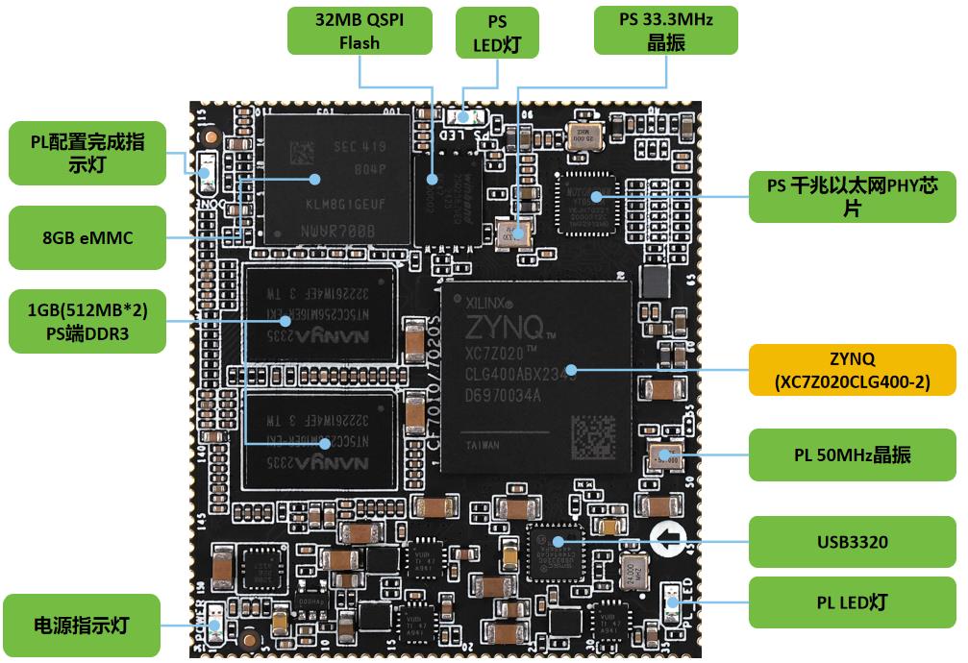
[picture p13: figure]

图 1.2.2 邮票孔 ZYNQ-7020 核心板

### 1.3 DDR3 SDRAM

ZYNQ 核心板板载 2 片 DDR3 SDRAM，BTB 版本 ZYNQ 核心板 7020 的 DDR3 型号为 NT5CC256M16，每片 4Gbit，总容量为 8Gbit（1GB）；7010 的 DDR3 型号为 NT5CC128M16， 每片 2Gbit，总容量为 4Gbit（512MB）。邮票孔版本 ZYNQ 核心板 7020 与 7010 的 DDR3 型号 均为 NT5CC256M16，每片 4Gbit，总容量为 8Gbit（1GB）。两片 DDR 都挂载在 PS 端，两片 DDR 组成 32bit 的总线宽度。PS 端的 DDR3 SDRAM 的最高运行速度可达 533MHz(数据速率 1066Mbps)，两片 DDR 存储系统直接连接到了 ZYNQ 处理系统（PS）的 BANK502 的存储器接 口上。
DDR 的硬件设计需要严格考虑信号完整性，我们在电路设计和 PCB 设计的时候已经充分 考虑了匹配电阻/终端电阻，走线阻抗控制，走线等长控制，保证 DDR3 的高速稳定的工作。PS 端的 DDR 的硬件连接方式如下图所示:

原子哥在线教学：https://www.yuanzige.com | 论坛：http://www.openedv.com/forum.php

U1

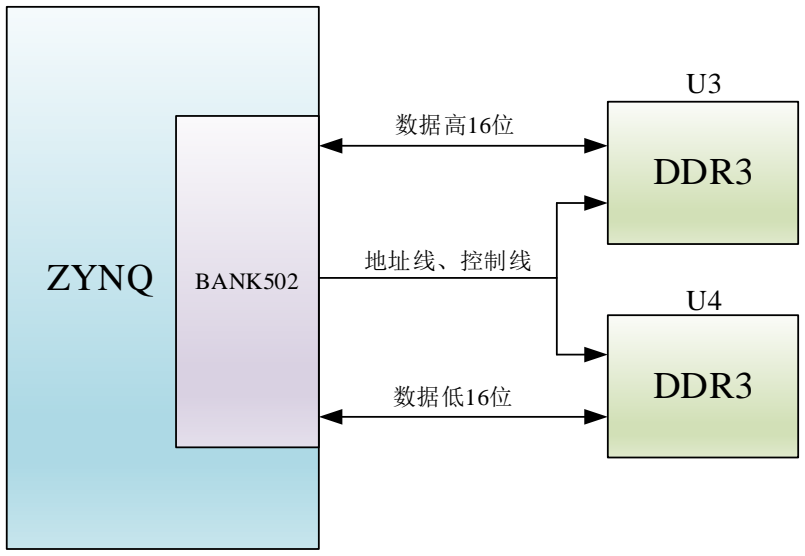
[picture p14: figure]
BANK502; DDR3; ZYNQ; 数据高16位; 数据低16位; 地址线、控制线

图 1.3.1 PS 端的 DDR 的硬件连接

### 1.4 QSPI Flash

核心板板载 1 片 Quad-SPI FLASH 芯片，容量大小为 32MB，FLASH 型号为 W25Q256FV， 工作电压标准是 3.3V CMOS。因为 QSPI FLASH 的非易失特性，所以我们可以将它作为系统的 启动设备来存储系统的启动镜像。这些镜像主要包括 FPGA 的 bit 文件、ARM 的应用程序代码 以及其它的用户数据文件。
QSPI FLASH 连接到 ZYNQ 芯片的 PS 部分 BANK500 的 GPIO 口上，在系统设计中需要配 置这些 PS 端的 GPIO 口功能为 QSPI FLASH 接口。QSPI Flash 的硬件连接如下图所示。

U1

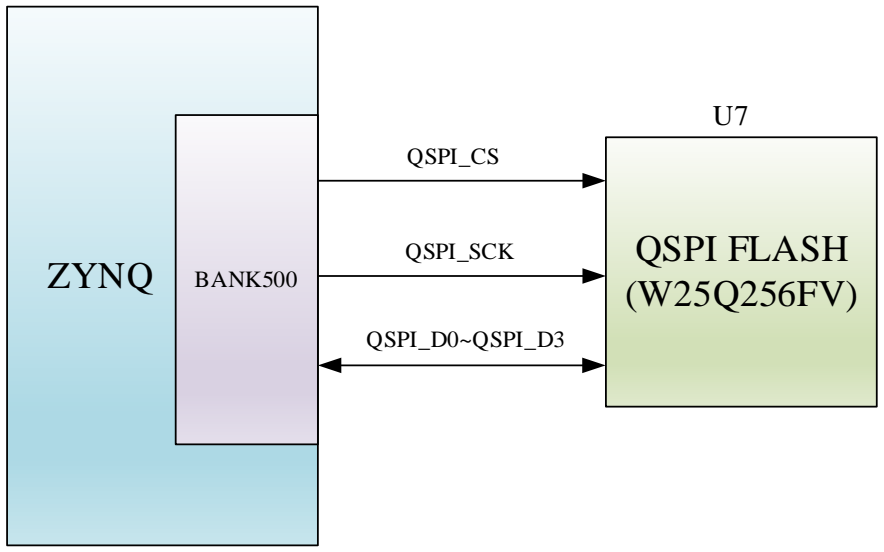
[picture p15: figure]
BANK500; QSPI FLASH (W25Q256FV) ZYNQ; QSPI_D0~QSPI_D3; QSPI_SCK; QSPI_CS

图 1.4.1 PS 端的 QSPI FLASH 的硬件连接

原子哥在线教学：https://www.yuanzige.com | 论坛：http://www.openedv.com/forum.php

### 1.5 eMMC Flash

核心板板载一片大容量的 8GB 大小的 eMMC FLASH 芯片，型号为 KLM8G1GETF。eMMC FLASH 和 ZYNQ 连接的数据宽度为 4bit。由于 eMMC FLASH 的大容量和非易失特性，在 ZYNQ 系统使用中，它可以作为系统大容量的存储设备，比如存储 ARM 的应用程序、系统文件以及 其它的用户数据文件。
eMMC FLASH 连接到 ZYNQ 芯片的 PS 部分 BANK501 的 GPIO 口上，在系统设计中需要 配置这些 PS 端 GPIO 口功能为 SD 接口。eMMC 的硬件连接如下图所示：

U1

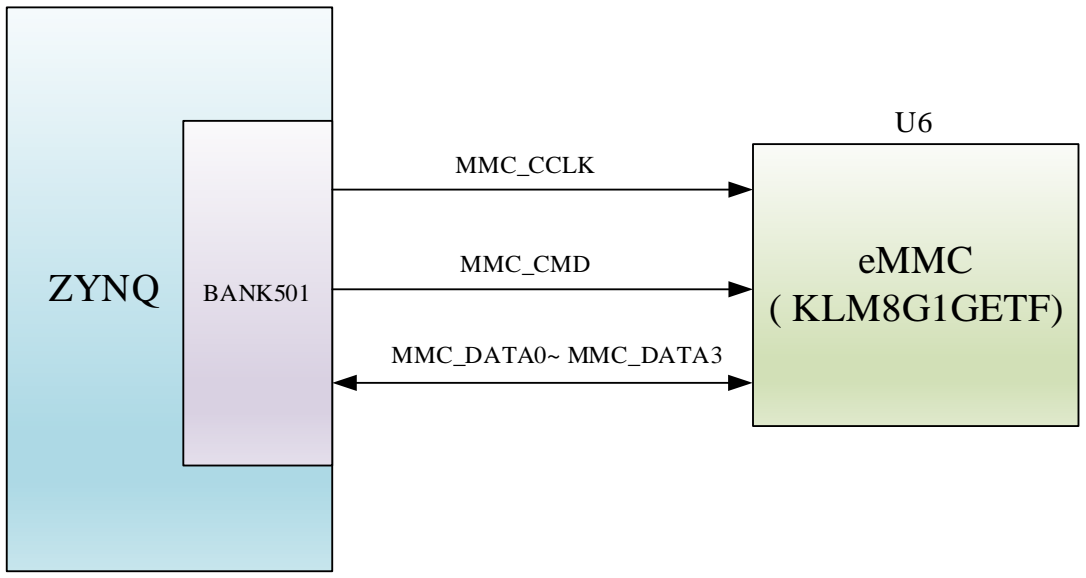
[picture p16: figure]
BANK501; eMMC ( KLM8G1GETF) ZYNQ; MMC_DATA0~ MMC_DATA3; MMC_CMD; MMC_CCLK

图 1.5.1 PS 端的 eMMC 的硬件连接

### 1.6 PS 端网口芯片

核心板板载一颗 PS 端千兆以太网 PHY（物理）芯片，实现了 10/100/1000M 以太网物理层 功能。该 PHY 芯片的引脚连接到了底板上的 RJ45 接口上，能够满足高带宽通信的需求。网口 芯片连接到了 PS 端的 BANK501 上面。

原子哥在线教学：https://www.yuanzige.com | 论坛：http://www.openedv.com/forum.php

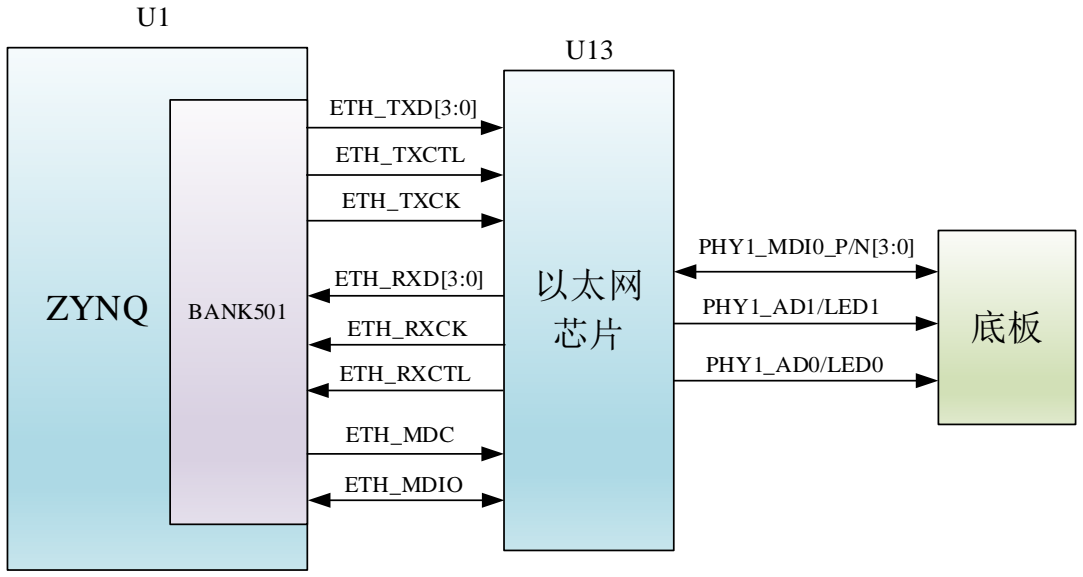
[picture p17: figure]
ZYNQ; ETH_RXD[3:0]; BANK501; 以太网 芯片; ETH_TXCK; ETH_RXCK; ETH_RXCTL; ETH_TXCTL; ETH_TXD[3:0]; ETH_MDC; ETH_MDIO; PHY1_MDI0_P/N[3:0]; PHY1_AD1/LED1; PHY1_AD0/LED0

图 1.6.1 PS 端的以太网的硬件连接
芯片支持 10/100/1000Mbps 网络传输速率，通过 RGMII 接口跟 ZYNQ PS 系统的 MAC 层 进行数据通信，并支持通过 MDIO 总线进行 PHY 寄存器的管理。除此之外，网口上电会检测 一些特定 IO 引脚的电平状态，从而确定自己的工作模式，用于配置芯片的工作状态。网口芯片 支持 10/100/1000Mbps 网络传输速率，由通信双方所能达到的最高通信速率决定。当以太网 PHY 芯片通信速率为 1000Mbps 时，以太网接口时钟频率为 125Mhz，数据在时钟的上升沿和下降样 被采样；当以太网 PHY 芯片通信速率为 100Mbps 时，以太网接口时钟频率为 25Mhz，数据在 时钟的上升沿被采样；当以太网PHY芯片通信速率为10Mbps时，以太网接口时钟频率为2.5Mhz， 数据在时钟的上升沿被采样。

### 1.7 时钟配置

核心板上分别为 PS 系统，PL 逻辑部分提供了参考时钟，使 PS 系统和 PL 逻辑可以单独工 作。时钟电路设计的示意图如下图所示：

原子哥在线教学：https://www.yuanzige.com | 论坛：http://www.openedv.com/forum.php

U1

BANK500

## ZYNQ

PS_CLK

BANK34

PL_GCLK

X1

## 50MHz

X2

33.33

## MHz

图 1.7.1 核心板时钟源
ZYNQ 芯片通过核心板上的 X2 晶振为 PS 部分提供 33.333333MHz 的时钟输入。时钟的输 入连接到 ZYNQ 芯片的 BANK500 的 PS_CLK_500 的管脚上。其原理图如下图所示：

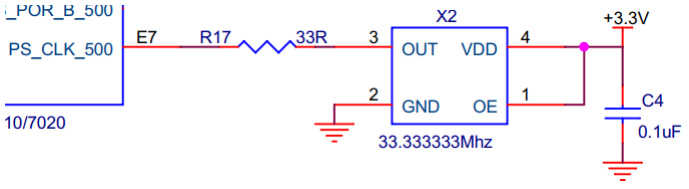
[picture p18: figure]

图 1.7.2 PS 部分时钟输入源
ZYNQ 芯片通过核心板上的 X1 晶振作为 PL 系统时钟源。晶振输出连接到 FPGA BANK34 的全局时钟(MRCC)，这个全局时钟可以用来驱动 FPGA 用户逻辑电路。该时钟源的原理图如 下图所示：

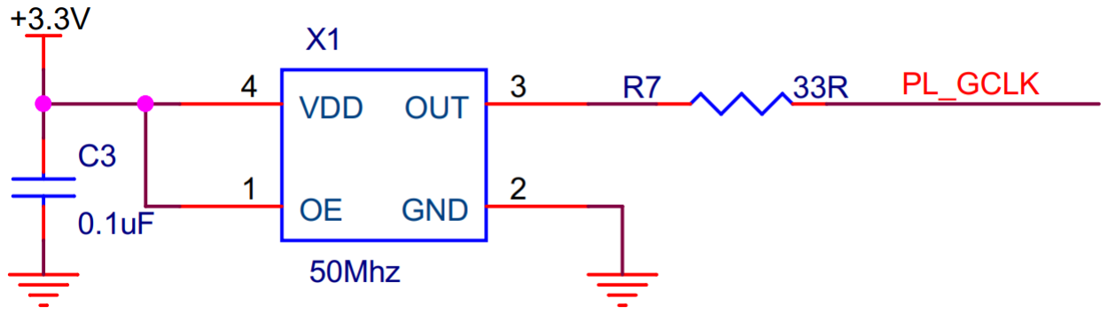
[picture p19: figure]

图 1.7.3 PL 系统时钟源

### 1.8 LED 灯

ZYNQ 核心板板载四个 LED 灯，其中两个是功能 LED 灯，灯亮为红色，PS 端一个，PL 端 一个。另外两个 LED 灯，一个是电源指示灯，核心板正常上电该灯亮蓝色，一个是 PL 配置完

原子哥在线教学：https://www.yuanzige.com | 论坛：http://www.openedv.com/forum.php
成指示灯，当 FPGA 程序配置完成后，该灯会亮绿色。这个四个灯在核心板上的原理图如下图 所示：

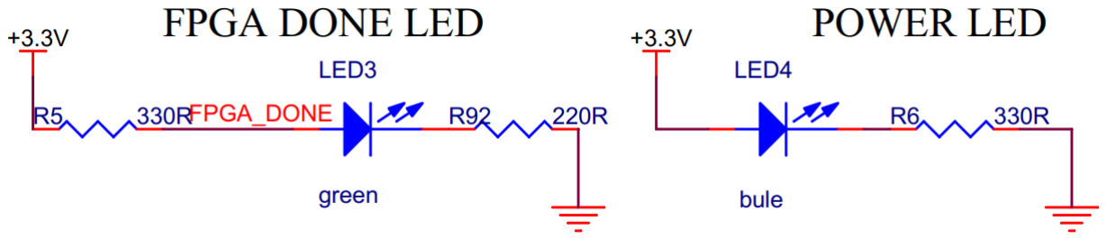
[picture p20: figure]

图 1.8.1 ZYNQ 核心板板载四个 LED 灯 上图除了电源指示灯（POWER LED）是核心板上电点亮，其余三个灯都是由 FPGA 控制 的，核心板板载的 LED 灯硬件连接示意图如下图所示：

U1

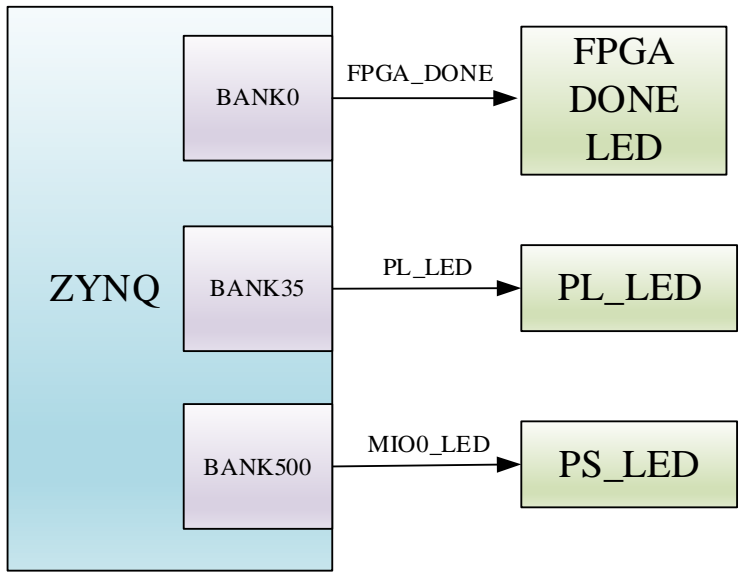
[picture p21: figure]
BANK0; ZYNQ; FPGA_DONE; MIO0_LED; FPGA DONE LED; PL_LED; BANK35; BANK500; PS_LED

图 1.8.2 ZYNQ 核心板板载四个 LED 灯硬件连接图

### 1.9 USB3320 芯片（邮票孔）

邮票孔核心板板载了 1 个连接 PS 端的 USB2.0 收发器芯片，USB2.0 收发器采用的是一个 1.8V 的，高速且支持 ULPI 标准接口的 USB3320C 芯片。USB2.0 PHY 芯片 USB3320C 工作在 1.8V 电压下，与 ZYNQ PS BANK 501 的 MIO 之间通过 ULPI 标准高速接口来进行通信。 USB3320 与 ZYNQ 之间的连接框图如下图所示：

原子哥在线教学：https://www.yuanzige.com | 论坛：http://www.openedv.com/forum.php

U1

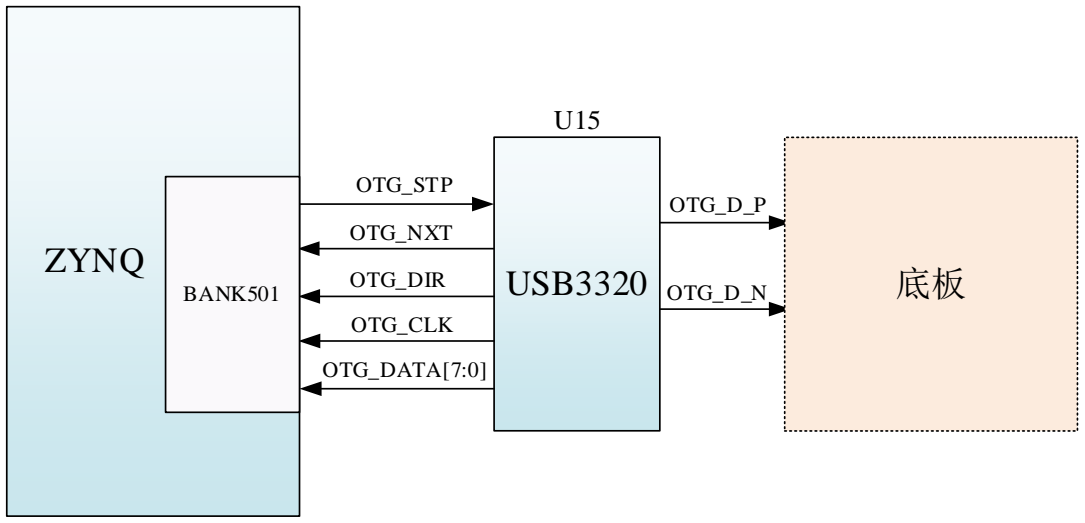
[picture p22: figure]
OTG_NXT; USB3320; OTG_DIR; OTG_CLK; OTG_STP; OTG_DATA[7:0]; OTG_D_P; OTG_D_N; ZYNQ; BANK501

图 1.9.1 USB 连接框图

原子哥在线教学：https://www.yuanzige.com | 论坛：http://www.openedv.com/forum.php

### 1.10 机械尺寸

BTB 核心板机械尺寸

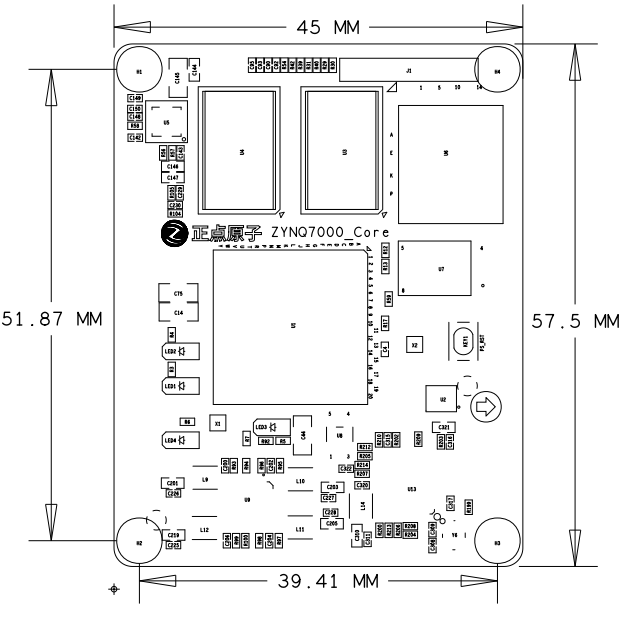
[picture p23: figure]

图 1.10.1 BTB 核心板机械尺寸图

原子哥在线教学：https://www.yuanzige.com | 论坛：http://www.openedv.com/forum.php
邮票孔核心板机械尺寸

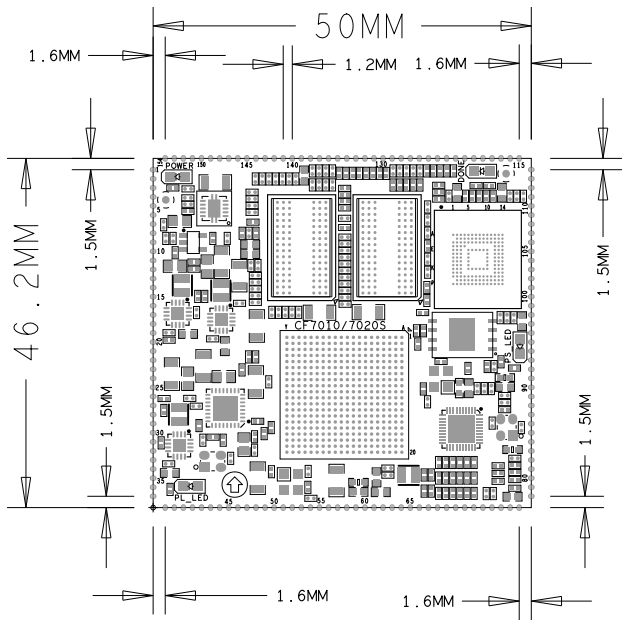
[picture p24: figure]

图 1.10.2 邮票孔核心板机械尺寸图

原子哥在线教学：https://www.yuanzige.com | 论坛：http://www.openedv.com/forum.php

### 2.1 最小系统设计

基于 ATK-CF7010/7020S 邮票孔核心板或 ATK-CF7010/7020B BTB 核心板进行底板设计 时，请务必满足最小系统设计要求，具体如下。

BTB 核心板电源设计说明

ZYNQ 芯片上各个电压的上电需要满足一定的上电顺序，而 BTB 核心板上 ZYNQ 芯片的 供电皆由核心板产生，我们在设计 BTB 核心板时已经考虑过芯片上电顺序的问题，因此大家基 于 BTB 核心板设计底板时无需再考虑如何满足 ZYNQ 芯片上电顺序的问题，这将大大降低底 板的电源设计难度。
当然在一些特殊场景下可能会要求底板的外设供电晚于核心板，因此我们在核心板上用最 后一个完成上电的电源做了一个 PG 信号（PW_GOOD），当该信号拉高时即说明核心板上的 所有电源全部完成了上电，且该信号是个 3.3V 的电平，足以作为绝大多数电源芯片使能信号， 大家只需将该信号作为底板上第一级电源芯片的使能信号，即可让底板上的外设上电晚于核心 板。值得一提的是由于启明星和领航者的底板并不需要使用 PG 信号，因此 BTB 核心板上的 PG 信号并未直接连到连接器上，当需要使用该信号时，大家一定要记得在 R217 上焊接一个 0 欧 姆的电阻，这样 PW_GOOD 才能连接到连接器上。R217 位于 BTB 核心板背面，其位置如下图 所示：


图 2.1.1 R217 电阻所在位置
接上 R217 电阻后，PW_GOOD 信号将会连接到 X4 连接器的 92 号引脚上，如下图所示：

原子哥在线教学：https://www.yuanzige.com | 论坛：http://www.openedv.com/forum.php


图 2.1.2 PW_GOOD 信号所在的连接器位置 需要特别说明的是，由于 BTB 核心板需要底板供电 5V 后才能正常工作，因此 PW_GOOD 信号不能作为 5V 电源的使能信号，否则将会导致整个板子都无法上电。如果底板上有 5V 外 设，且也要求上电晚于核心板的话，建议使用两个输出 5V 的电源芯片，一个仅用于给核心板 供电，另一个则用于给底板的 5V 外设供电。

邮票孔核心板电源设计说明

邮票孔核心板也同样需要满足 ZYNQ 芯片的上电顺序要求，而由核心板供电的电源皆以满 足上电要求，但是与 BTB 核心板不同的是邮票孔核心板没有给 BANK34 和 BANK35 供电，而 是将这两个 BANK 的供电引到了邮票孔引脚上，这么做的好处是 BANK 电源支持可调，大家 在设计底板时就可以按照外设的电平需求来给这两个 BANK 分别供电，例如底板设计时有些外

原子哥在线教学：https://www.yuanzige.com | 论坛：http://www.openedv.com/forum.php
设需要 LVDS 电平，有些外设只需要 COMS33 电平，那这时候就可以给 BANK34 和 BANK35 中的一个 BANK 供 2.5V 的电源来实现 LVDS 电平，另一个 BANK 则提供 3.3V 的电源来实现 COMS33 电平。
当然 BANK34 和 BANK35 的供电也需要满足 ZYNQ 芯片的上电顺序要求，不过作为 ZYNQ 芯片上电顺序中的最后一级，这两个 BANK 的供电只需要晚于邮票孔核心板即可，为此我们在 邮票孔核心板上 PG 信号（PW_GOOD），当该信号拉高时即说明核心板上的所有电源全部完 成了上电，且该信号是个 3.3V 的电平，足以作为绝大多数电源芯片使能信号，大家只需将该信 号作为底板上给BANK34和 BANK35供电的电源芯片的使能信号，即可让 BANK34和 BANK35 满足 ZYNQ 芯片的上电顺序要求。邮票孔核心板上 PG 信号（PW_GOOD）位于邮票孔的第 142 脚，其位置如下图所示：


图 2.1.3 PW_GOOD 信号所在的邮票孔位置 需要特别说明的是，由于邮票孔核心板需要底板供电 3.3V 后才能正常工作，因此 PW_GOOD 信号不能作为 3.3V 电源的使能信号，否则将会导致整个板子都无法上电。如果底 板上要对 BANK34 和 BANK35 提供 3.3V 的电源，建议使用两个输出 3.3V 的电源芯片，一个 仅用于给核心板供电，另一个则用于给 BANK34 和 BANK35 供电。

系统启动配置

ZYNQ 支持 4 种启动模式，分别是 JTAG、NAND、QSPI FLASH 和 SD Card。测试底板通 过 MIO4 和 MIO5 两个引脚进行控制，此外在测试板上 MIO4 与 QSPI_D2、MIO5 与 QSPI_D3 复用。

原子哥在线教学：https://www.yuanzige.com | 论坛：http://www.openedv.com/forum.php


图 2.1.4 引脚复用
PS 的模式选择开关 1（BOOT_MODE0）由 MIO4（和 QSPI_D2 引脚复用）引脚控制，PS 的模式选择开关 2（BOOT_MODE1）由 MIO5（和 QSPI_D3 引脚复用）引脚控制，底板上的两 个拨码开关用于设置 ZYNQ 的 BOOT 模式：
当拨开开关 1 设置为“ON”、拨开开关 2 设置为“ON”时，ZYNQ PS 端在上电后的启 动源被设置为 JTAG；
当拨开开关 1 设置为“OFF”、拨开开关 2 设置为“ON”时，ZYNQ PS 端在上电后的启 动源被设置为 NAND FLASH。
当拨开开关 1 设置为“ON”、拨开开关 2 设置为“OFF”时，ZYNQ PS 端在上电后的启 动源被设置为 QSPI FLASH；
当拨开开关 1 设置为“OFF”、拨开开关 2 设置为“OFF”时，ZYNQ PS 端在上电后的 启动源被设置为 SD Card。

系统复位信号

PS_POR_B_500 为 PS 端 Power On Reset 输入引脚，该复位信号不但复位所有寄存器，还 将复位所有调试环境。邮票孔测试底板上有一个复位电路，使用的复位芯片型号为 HX811T， 该复位芯片具有消抖功能，若使用邮票孔核心板用户需在底板自行添加该复位按键。BTB 核心 板复位输入信号连接到核心板的复位按键，复位输出连接到 ZYNQ 芯片 PS 复位管脚上，用户 可以使用这个核心板板载的按键来复位 ZYNQ 系统。BTB 核心板复位连接的示意图如下图所 示:

原子哥在线教学：https://www.yuanzige.com | 论坛：http://www.openedv.com/forum.php

U1

ZYNQ

PS_POR_B
BANK500 | HX811T | KEY1
| U2

图 2.1.5 复位按键


图 2.1.6 开机复位
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

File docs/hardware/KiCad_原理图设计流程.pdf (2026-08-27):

CORE 项目 · 硬件设计文档 | 第 1 页

# KiCad 原理图设计流程

CORE 项目 · 硬件设计文档 | KiCad 10.0.4 简体中文界面 | 中英术语对照

本文按实际执行顺序，梳理 KiCad 原理图（Eeschema）从新建工程到输出网表的完整流程。

环境：KiCad 10.0.4，简体中文界面。界面项以「中文 / English」成对给出；标注 [■■] 的表示该处界面显示的就是英文原文（官方中文翻译未覆盖）。快捷键取自本机实际配置。

## 0. 流程总览

阶段一 工程与图纸准备

新建工程 / 页面设置 / 图框

阶段二 符号库准备

标准库 / 自建符号 / 库路径

阶段三 绘制电路

放符号 / 连线 / 标签

阶段四 层次化拆分

按功能分图纸 / 层次标签

阶段五 批注位号

分配唯一 R1 C2 U3

阶段六 分配封装

与实际采购件对应

阶段七 ERC 检查

引脚冲突 / 未连接 / 电源

阶段八 输出

BOM / 网表 / 更新 PCB

阶段六、七出错会直接导致板子报废或返工，是全流程的两个卡点

图 1 原理图设计八阶段

原理图的产出物只有一个：一份准确描述电气连接、且每个元件都对应到可采购实物的网表。所有工作都服务于 这个目标。

其中阶段六（分配封装）和阶段七（ERC）是两个卡点：

- 封装错了，板子回来元件焊不上，直接报废
- ERC 没查干净，漏连、短路会一路带到 PCB，等调试时才发现

## 1. 阶段一：工程与图纸准备

### 1.1 新建工程

用 KiCad 项目管理器新建工程，会同时生成 .kicad_pro、.kicad_sch、.kicad_pcb。

不要单独打开 .kicad_sch 文件工作——脱离工程时，库路径、网络类等工程级设置不会生效。

### 1.2 页面设置

■■(F) / File → ■■■■... / Page Settings...

- 选择图幅（A4 / A3）。电路复杂时优先用层次化拆分成多张 A4，而不是硬塞进一张 A3
- 填写标题栏：图纸标题、版本号、日期、作者、公司

标题栏是后续版本管理的依据，每次改动改版本号，比事后翻 git log 直观。

CORE 项目 · 硬件设计文档 | 第 2 页

### 1.3 原理图配置

■■(F) / File → ■■■■■... / Schematic Setup...

重点是两项：

- 格式化：字号、线宽、字段可见性的全局默认值
- 电气规则：ERC 各类违规的严重级别（错误 / 警告 / 忽略）

### 1.4 栅格

原理图必须在栅格上绘制。KiCad 默认符号引脚间距是 2.54 mm（100 mil），连线时栅格也应保持 2.54 mm 或 1.27 mm。

栅格不对齐是新手最常见的隐性错误：看上去线连到引脚上了，实际差几个像素，电气上没连接。放大后能看到 引脚末端的小方块没有变成连接点。

### 1.5 常见错误

- 用极小的栅格画线，导致连线与引脚"看起来连上了"但实际没连
- 一张图纸塞下整个系统，后期无法阅读也无法维护
- 标题栏留空，多版本迭代后分不清哪张是最新的

## 2. 阶段二：符号库准备

### 2.1 管理符号库

■■■■ / Preferences → ■■■■■... / Manage Symbol Libraries...

分全局库和工程库两级。工程专用的自建符号应放工程库，跟着工程走，换电脑不会丢。

### 2.2 什么时候需要自建符号

标准库覆盖不了的情况：

- 特定型号的芯片（本项目的 ZYNQ7010&7020_CB 核心板座）
- 非标连接器
- 需要按功能拆分成多个单元（Unit）的复杂器件
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

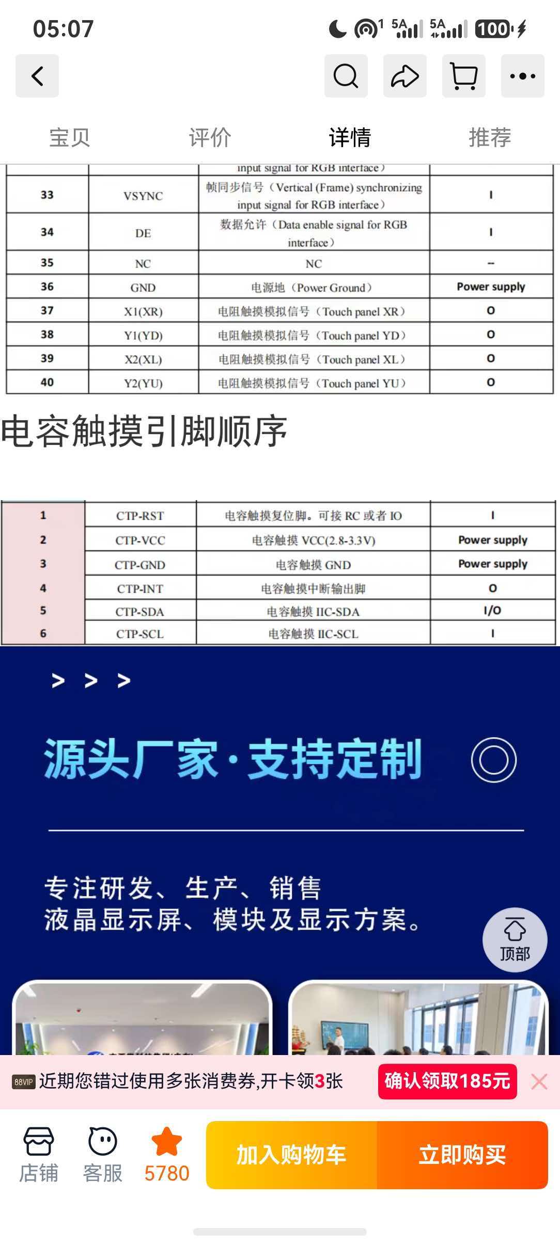
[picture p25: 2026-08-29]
docs/hardware/触摸屏接口.jpg

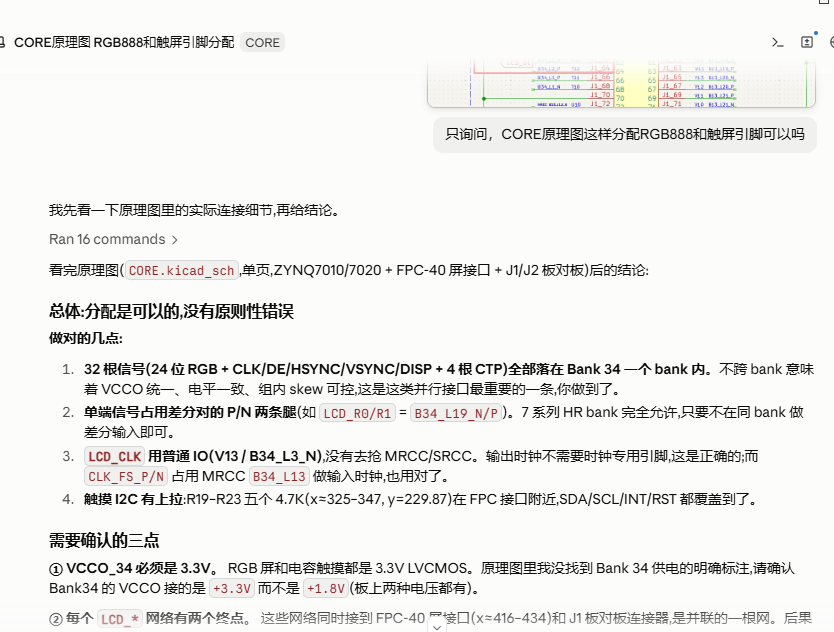
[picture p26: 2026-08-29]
docs/hardware/RGB888引脚分配.png

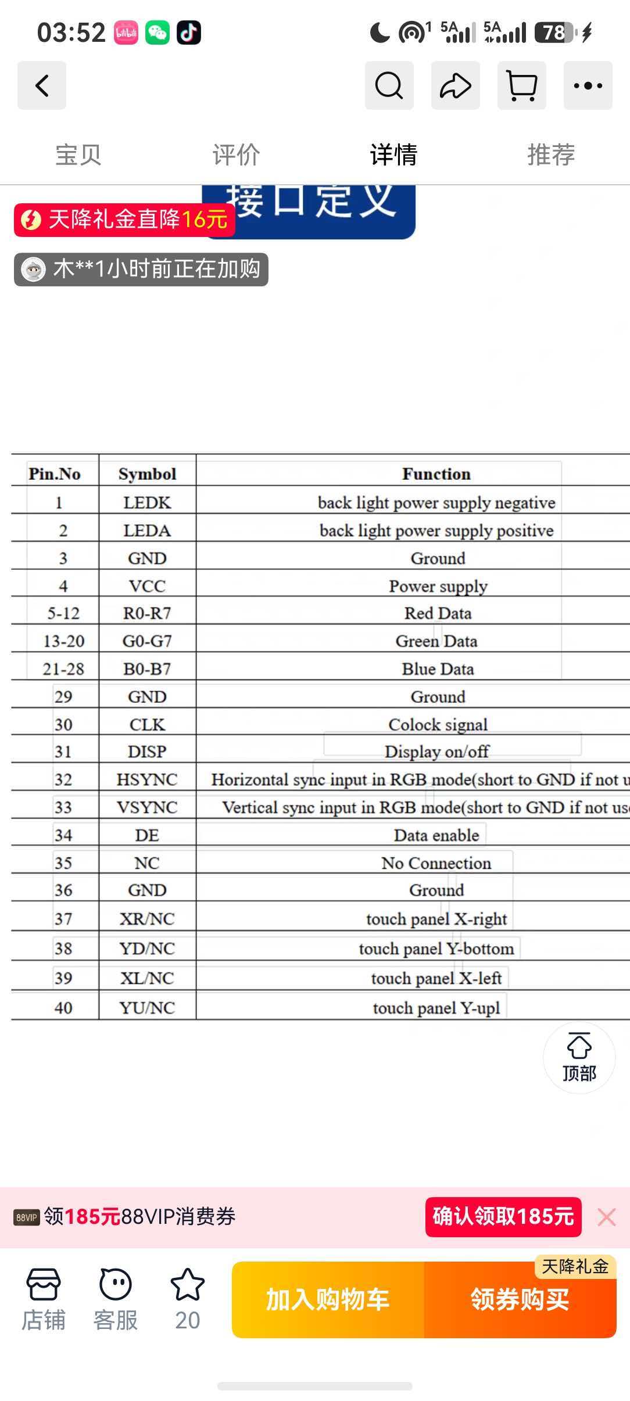
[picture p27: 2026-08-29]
docs/hardware/LCD接口.jpg

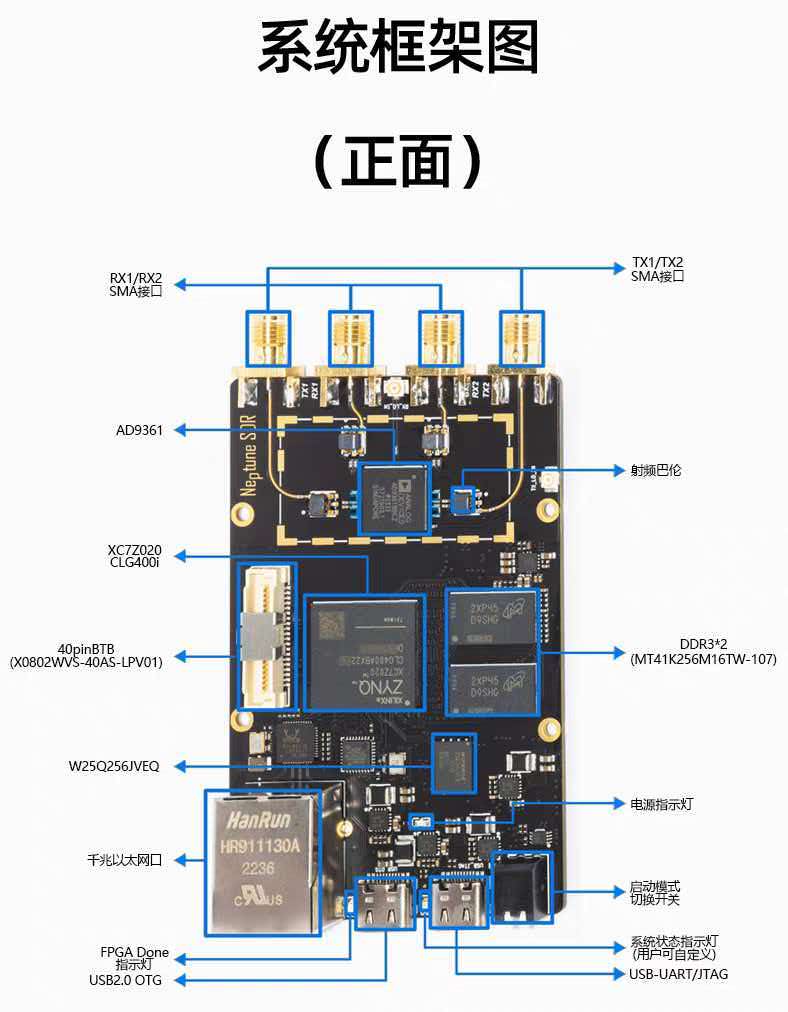
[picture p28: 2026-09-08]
docs/references/参考核心板1.jpg

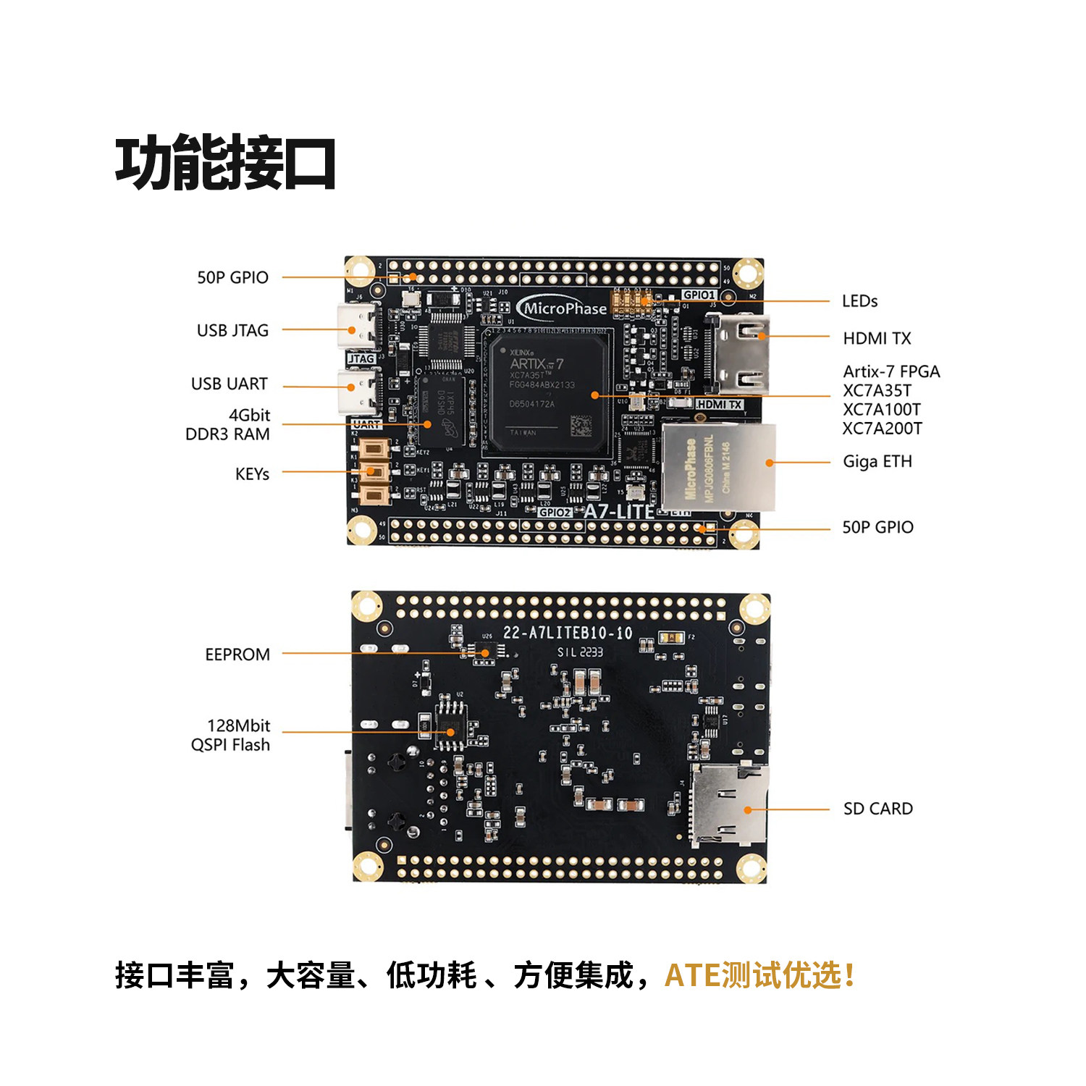
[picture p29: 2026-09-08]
docs/references/参考核心板2.jpg

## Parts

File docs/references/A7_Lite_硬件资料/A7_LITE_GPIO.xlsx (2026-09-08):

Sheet: Sheet1
GPIO1
引脚编号 | 引脚名称 | 对应管脚
1 | GPIO1_0P | F13
2 | GPIO1_0N | F14
3 | GPIO1_1P | E13
4 | GPIO1_1N | E14
5 | GPIO1_2P | D14
6 | GPIO1_2N | D15
7 | GPIO1_3P | E16
8 | GPIO1_3N | D16
9 | GPIO1_4P | D17
10 | GPIO1_4N | C17
11 | VCC_5V | 5V电源
12 | GND | 电源地
13 | GPIO1_5P | C13
14 | GPIO1_5N | B13
15 | GPIO1_6P | A13
16 | GPIO1_6N | A14
17 | GPIO1_7P | C14
18 | GPIO1_7N | C15
19 | GPIO1_8P | A15
20 | GPIO1_8N | A16
21 | GPIO1_9P | B15
22 | GPIO1_9N | B16
23 | GPIO1_10P | F16
24 | GPIO1_10N | E17
25 | GPIO1_11P | A18
26 | GPIO1_11N | A19
27 | GPIO1_12P | B17
28 | GPIO1_12N | B18
29 | VCC_3V3 | 3.3V电源
30 | GND | 电源地
31 | GPIO1_13P | B20
32 | GPIO1_13N | A20
33 | GPIO1_14P | F19
34 | GPIO1_14N | F20
35 | GPIO1_15P | E19
36 | GPIO1_15N | D19
37 | GPIO1_16P | C18
38 | GPIO1_16N | C19
39 | GPIO1_17P | F18
40 | GPIO1_17N | E18
41 | VCCIO_A | BNAK16可选电压
42 | GND | 电源地
43 | GPIO1_18P | D20
44 | GPIO1_18N | C20
45 | GPIO1_19P | B21
46 | GPIO1_19N | A21
47 | GPIO1_20P | D21
48 | GPIO1_20N | G21
49 | GPIO1_21P | C22
50 | GPIO1_21N | B22

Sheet: Sheet2
GPIO2
引脚编号 | 引脚名称 | 对应管脚
1 | GPIO2_0P | W21
2 | GPIO2_0N | W22
3 | GPIO2_1P | N17
4 | GPIO2_1N | P17
5 | GPIO2_2P | P19
6 | GPIO2_2N | R19
7 | GPIO2_3P | R18
8 | GPIO2_3N | T18
9 | GPIO2_4P | T21
10 | GPIO2_4N | U21
11 | 电源 | 5V电压
12 | GND | 电源地
13 | GPIO2_5P | U22
14 | GPIO2_5N | V22
15 | GPIO2_6P | Y21
16 | GPIO2_6N | Y22
17 | GPIO2_7P | AA20
18 | GPIO2_7N | AA21
19 | GPIO2_8P | AB21
20 | GPIO2_8N | AB22
21 | GPIO2_9P | AA19
22 | GPIO2_9N | AB20
23 | GPIO2_10P | U20
24 | GPIO2_10N | V20
25 | GPIO2_11P | Y18
26 | GPIO2_11N | Y19
27 | GPIO2_12P | W19
28 | GPIO2_12N | W20
29 | 电源 | 3.3V电源
30 | GND | 电源地
31 | GPIO2_13P | AA18
32 | GPIO2_13N | AB18
33 | GPIO2_14P | V18
34 | GPIO2_14N | V19
35 | GPIO2_15P | V17
36 | GPIO2_15N | W17
37 | GPIO2_16P | U17
38 | GPIO2_16N | U18
39 | GPIO2_17P | P14
40 | GPIO2_17N | R14
41 | NC | 不连接
42 | GND | 电源地
43 | GPIO2_18P | P16
44 | GPIO2_18N | R17
45 | GPIO2_19P | N13
46 | GPIO2_19N | N14
47 | GPIO2_20P | P15
48 | GPIO2_20N | R16
49 | GPIO2_21P | AB7
50 | GPIO2_21N | AB6

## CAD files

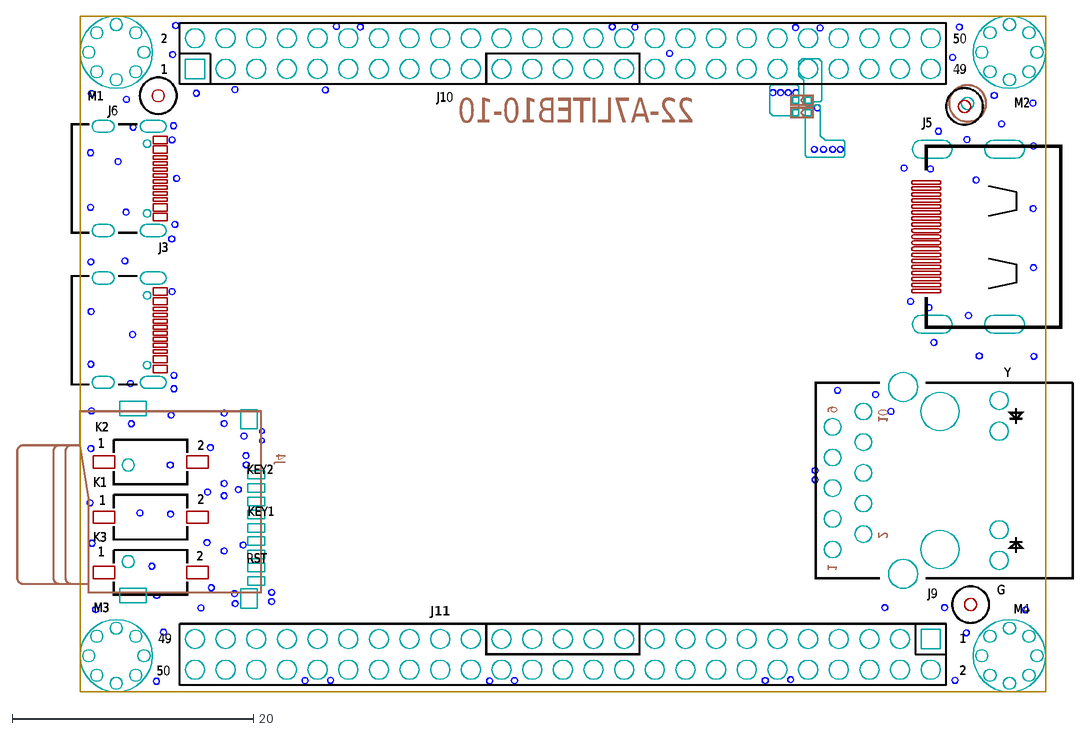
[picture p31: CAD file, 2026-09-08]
docs/references/A7_Lite_硬件资料/A7-LITE_Mechanical.dxf
M2
M4
M3
M1
2
1
K1
K3
K2
J4
J3
J6
J9
Y
G
9
10
J5
J11
49
50
J10
22-A7LITEB10-10
RST
KEY1
KEY2

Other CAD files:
tools/LC_3D_Module_Download-master/step/ANT-SMD_KH-IPEX-K501-29.step

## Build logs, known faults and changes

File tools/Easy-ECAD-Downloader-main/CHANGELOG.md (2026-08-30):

# Changelog

Notable changes are recorded here in reverse chronological order.

## Unreleased

This section summarizes the current `Development` branch compared with `main` as reviewed on 2026-05-08.

### Added

- Added Mouser SamacSys support for part detection, preview loading, upstream KiCad ZIP download, and KiCad library or loose-file export.
- Added Farnell SamacSys support through the shared SamacSys distributor flow.
- Added Firefox SamacSys relay support for preview and export requests through a user-managed relay URL.
- Added SamacSys authentication settings for relay auth and upstream username/password Basic auth generation.
- Added a configurable Downloads-relative KiCad library folder.
- Added runtime ZIP extraction for SamacSys archives, including KiCad symbols, footprints, STEP models, and WRL files already present in the archive.
- Added `systemDesign.md`, architecture notes, Firefox relay documentation, contribution guidance, and security reporting documentation.
- Added a Node/Vitest regression suite covering content-script detection, popup behavior, service-worker orchestration, EasyEDA conversion, and repository hygiene.
- Added CI, ESLint, dependency audit, `npm run validate`, `.nvmrc`, and `package-lock.json` for repeatable local and GitHub Actions validation.
- Added repository hygiene checks for source footers, governance docs, validation wiring, high-confidence secret patterns, generated archives, local environment files, logs, editor files, and temporary files.
- Added repository hygiene checks for conventional file naming, lower camelCase function declarations, and maintained-file line-count limits.

### Changed

- Renamed the extension to Easy ECAD Downloader, including package metadata, UI labels, documentation links, generated KiCad metadata, and the default library folder name.
- Split the service worker into a thin Manifest V3 entrypoint plus a runtime/router module with source adapters and shared core helpers.
- Split the EasyEDA-to-KiCad converter into focused parser, emitter, shared conversion, and OBJ-to-WRL modules while keeping `src/kicad_converter.js` as the public facade.
- Split the oversized service-worker regression file into focused core, EasyEDA, direct SamacSys, and Firefox SamacSys test files backed by a shared harness.
- Reworked the popup into a provider-aware UI that shows fixed manufacturer metadata plus source-specific part metadata and advanced SamacSys/Firefox settings.
- Moved persistent download layout, Firefox relay, and SamacSys auth settings from the popup into a dedicated extension settings page.
- Grouped Firefox helper controls into a Firefox-only advanced settings menu.
- Added explicit `Save` and `Discard` controls to the settings page.
- Made helper tokens and SamacSys passwords session-only by default, with explicit remember-on-this-device opt-ins and warning copy.
- Removed hidden upstream `Authorization` capture, manual override handling, and automatic Firefox auth-refresh retry behavior.
- Updated the manifest for Chrome service-worker operation and Firefox background-document fallback on Firefox `121+`.
- Updated README and project docs to describe supported providers, setup, settings, auth behavior, browser support, validation, and repository layout.

### Fixed

- Treated WRL-only SamacSys ZIP archives as valid 3D model exports.
- Preserved SamacSys library footprint model references when an archive provides only a WRL model.
- Replaced repeated KiCad footprint template fields so generated vias and text sizes no longer leave raw placeholders.
- Corrected EasyEDA WRL placement by centering OBJ geometry, bottom-aligning Z, and writing KiCad 3D-unit offsets.
- Rendered EasyEDA footprint previews for oval pads and solid-region geometry used by several LCSC footprints.
- Detected JLCPCB manufacturer part numbers when product pages use compact labels such as `MFR.Part #`.
- Improved provider-aware page detection for JLCPCB, LCSC, Mouser, and Farnell product pages.
- Reconciled EasyEDA footprint model references with exported STEP/WRL artifacts and removed stale model blocks when no 3D artifact is exported.
- Preserved SamacSys KiCad library relationships by rewriting symbol footprint properties and footprint model paths in library mode.
- Handled SamacSys ZIP structures where `KiCad/` and `3D/` folders appear either at the archive root or under a part-specific parent folder.
- Reworked SamacSys ZIP `401` handling into clearer sign-in-required errors and retry behavior.
- Kept relay auth separate from upstream SamacSys auth so relay credentials are not forwarded to upstream providers.
- Saved EasyEDA datasheets in the documented library-mode `datasheets/` folder and warned when selected export assets are unavailable.
- Removed real-looking SamacSys auth values from tests and fixtures.
- Removed a stale repository review plan from tracked docs so `systemDesign.md` remains the design source of truth.

### Security

- Documented credential storage, relay responsibility, vulnerability reporting, and stored credential clearing in `SECURITY.md`.
- Added automated checks for common secret/token formats and private-key material in text files.
- Added ignore rules and hygiene checks for local secret files, generated extension archives, logs, editor backups, OS metadata, and temporary files.
- Added full-history security hygiene validation for reachable Git commits.

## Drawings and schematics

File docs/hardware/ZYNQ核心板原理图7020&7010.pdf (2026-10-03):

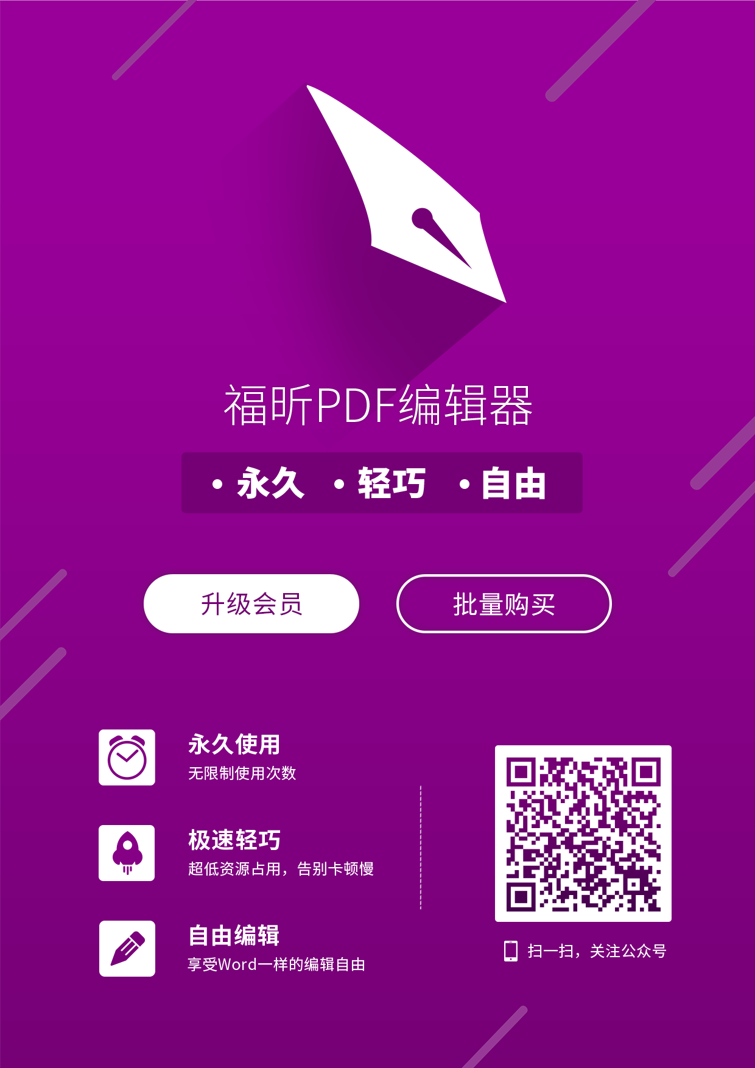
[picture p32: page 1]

## QSPI Flash [Winbond]

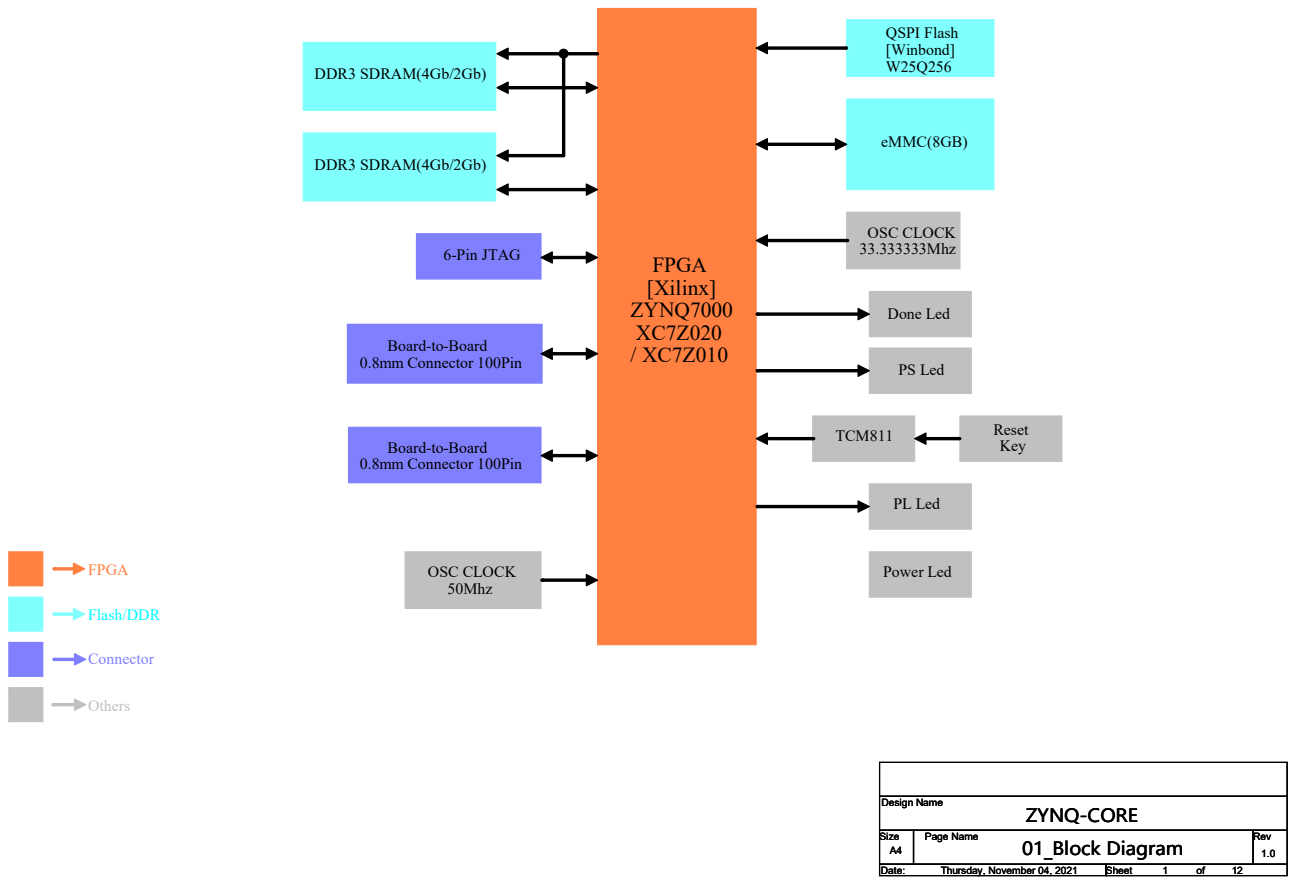
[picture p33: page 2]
eMMC(8GB); DDR3 SDRAM(4Gb/2Gb); 6-Pin JTAG; FPGA; OSC CLOCK; 50Mhz; Flash/DDR; OSC CLOCK 33.333333Mhz; Done Led; PS Led; TCM811; Reset; Key; PL Led; Power Led; FPGA [Xilinx] ZYNQ7000 XC7Z020 / XC7Z010; Connector; Others; Design Name; ZYNQ-CORE

Board-to-Board
0.8mm Connector 100Pin

Size A4 | Page Name 01_Block Diagram 01_Block Diagram 01_Block Diagram | Rev 1.0

Date: Thursday, November 04, 2021 Thursday, November 04, 2021 Thursday, November 04, 2021 | Sheet 1 1 1 of 12 12 12

# BANK0

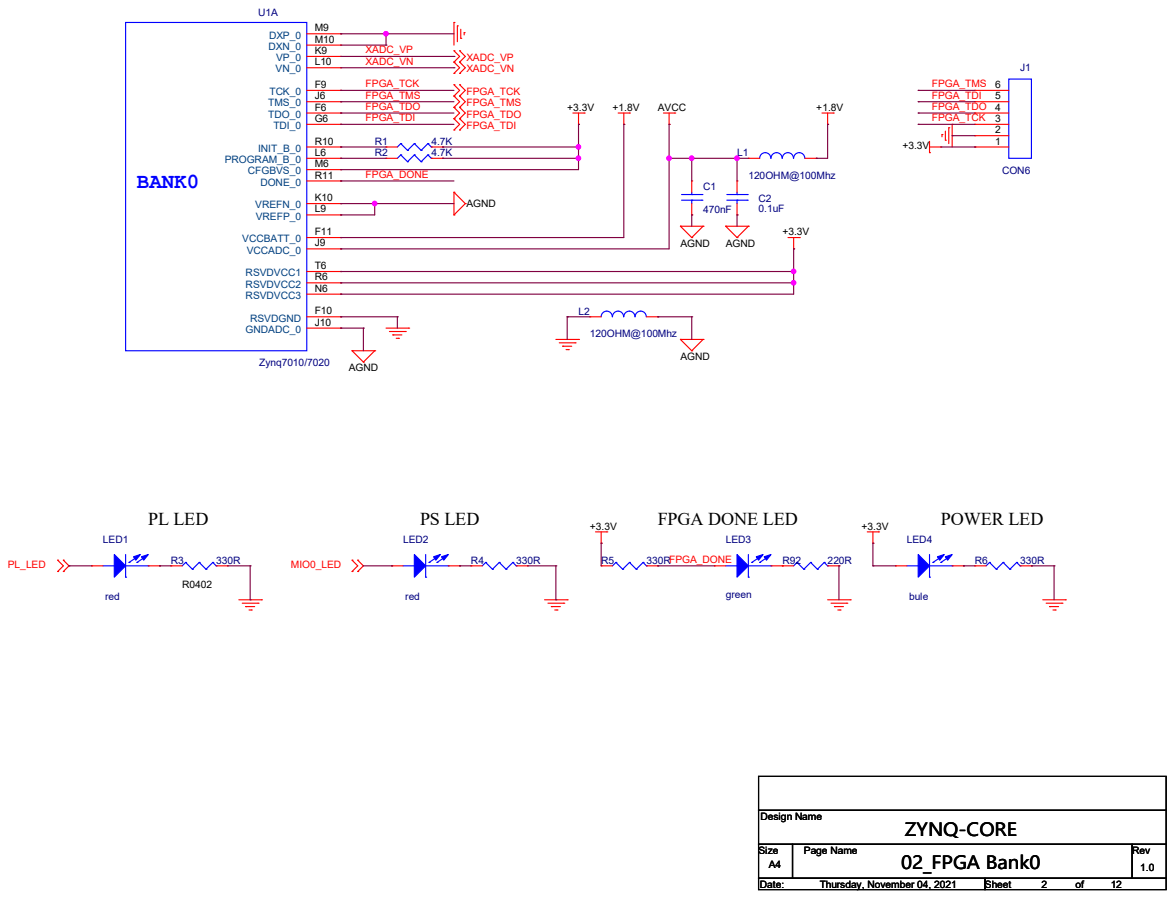
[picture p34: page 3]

## BANK34

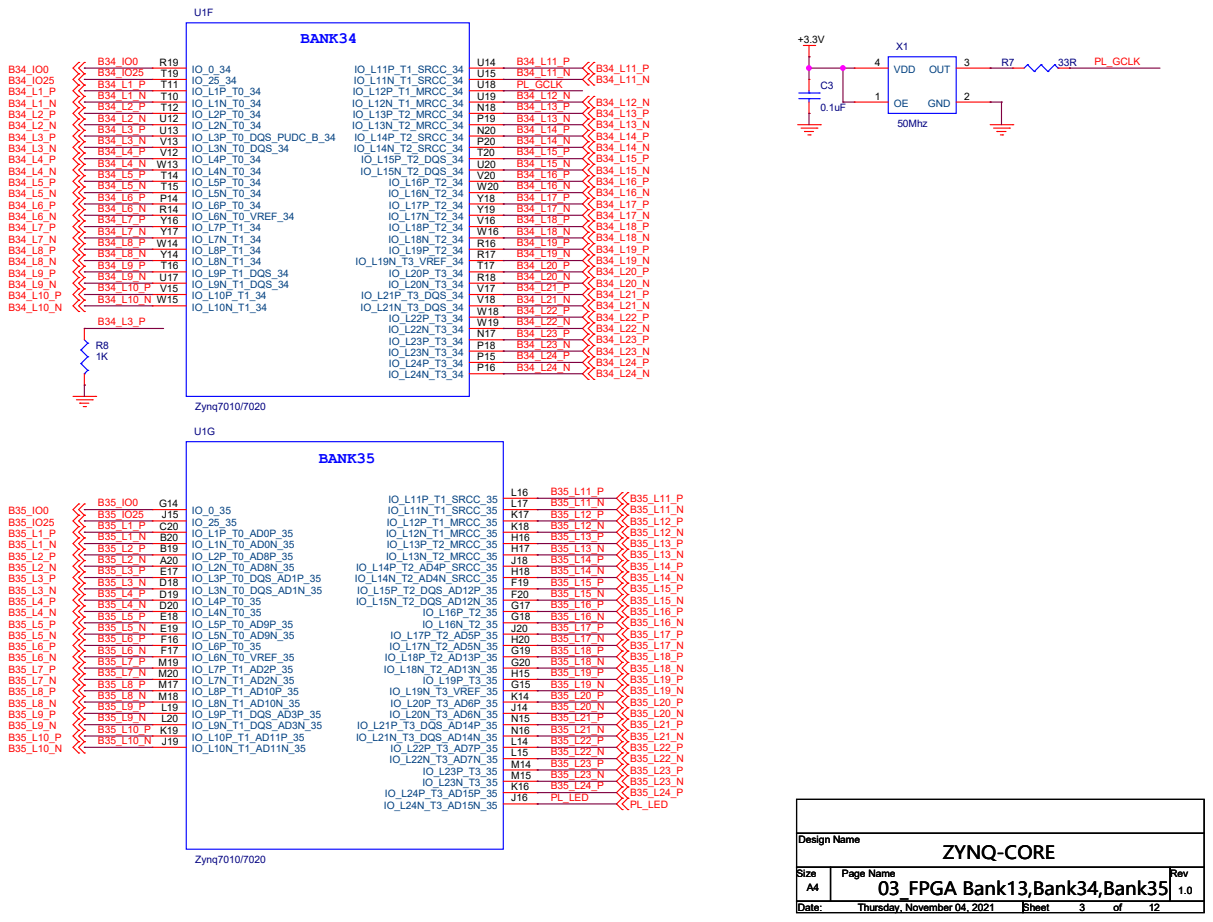
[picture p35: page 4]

# VOLTAGE/JTAG/PLL OPTION

# BANK500

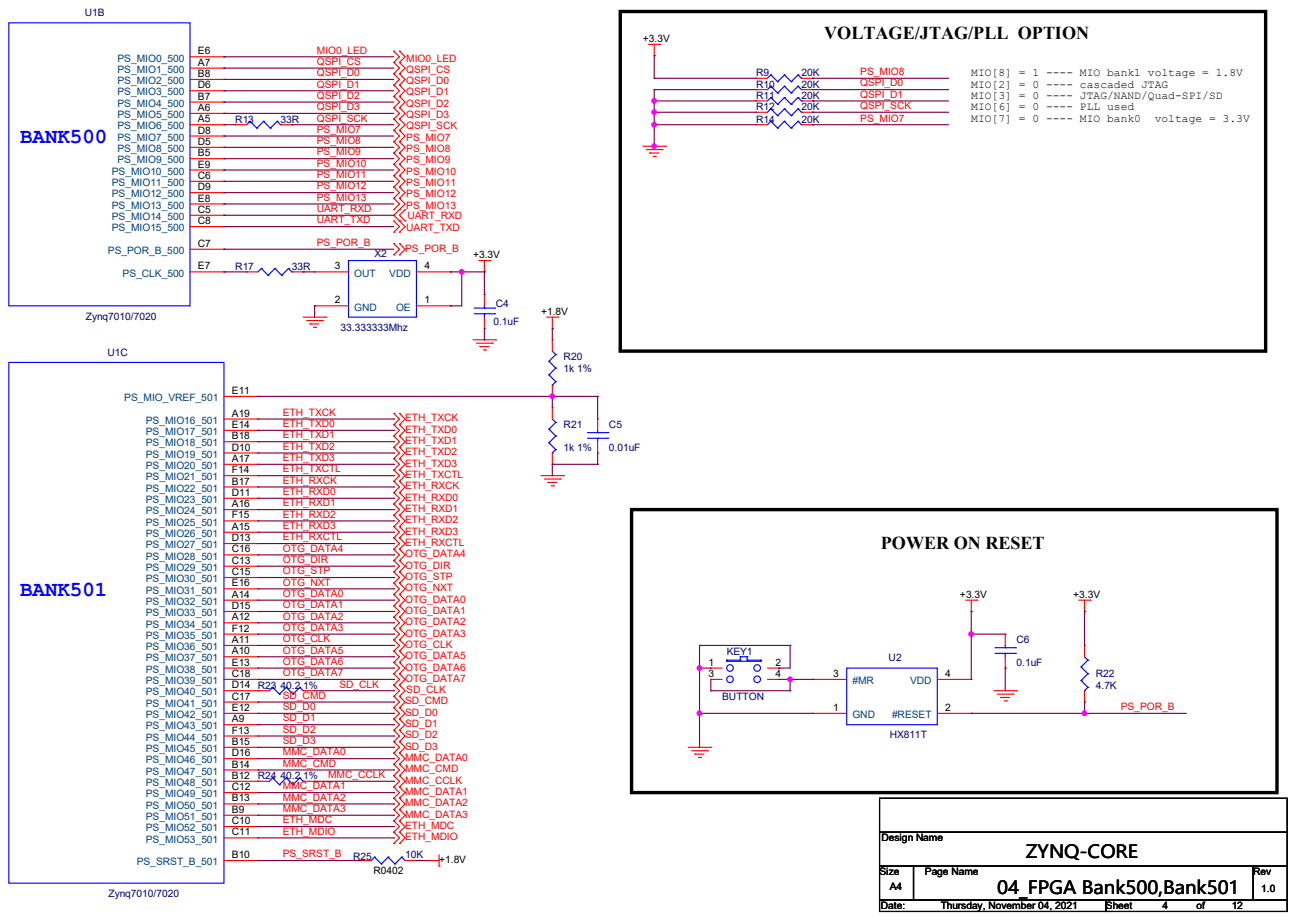
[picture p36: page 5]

MIO[8] = 1 ---- MIO bank1 voltage = 1.8V
MIO[2] = 0 ---- cascaded JTAG
MIO[3] = 0 ---- JTAG/NAND/Quad-SPI/SD
MIO[6] = 0 ---- PLL used
MIO[7] = 0 ---- MIO bank0 voltage = 3.3V

# BANK502

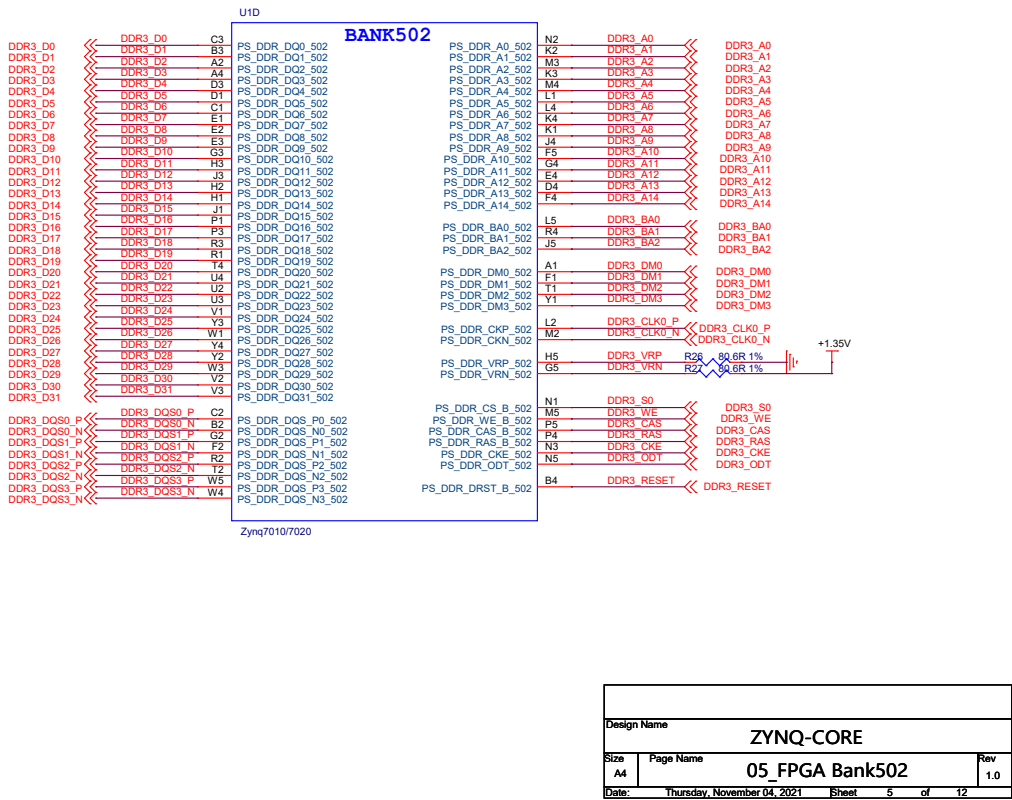
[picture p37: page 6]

05_FPGA Bank502 05_FPGA Bank502 05_FPGA Bank502

Thursday, November 04, 2021 Thursday, November 04, 2021 Thursday, November 04, 2021 | 5 5 5 12 12 12

5

4

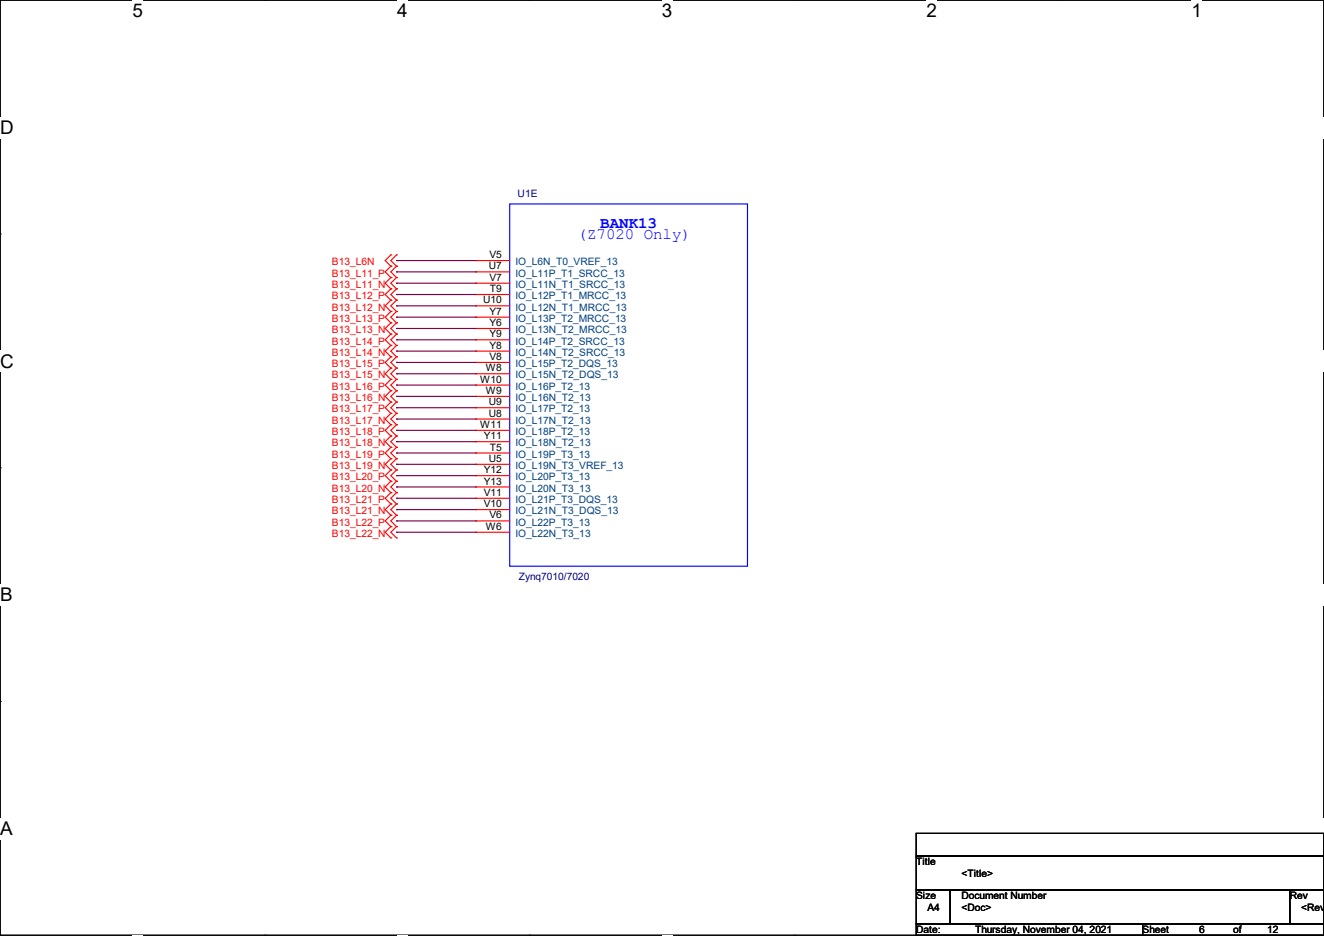
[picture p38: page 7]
Title; Size; Document Number; Rev; <Doc>; <RevCode>; <Title>; Thursday, November 04, 2021; BANK13 (Z7020 Only); Zynq7010/7020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

### VCCO_13

VCCINT | VCC_PAUX

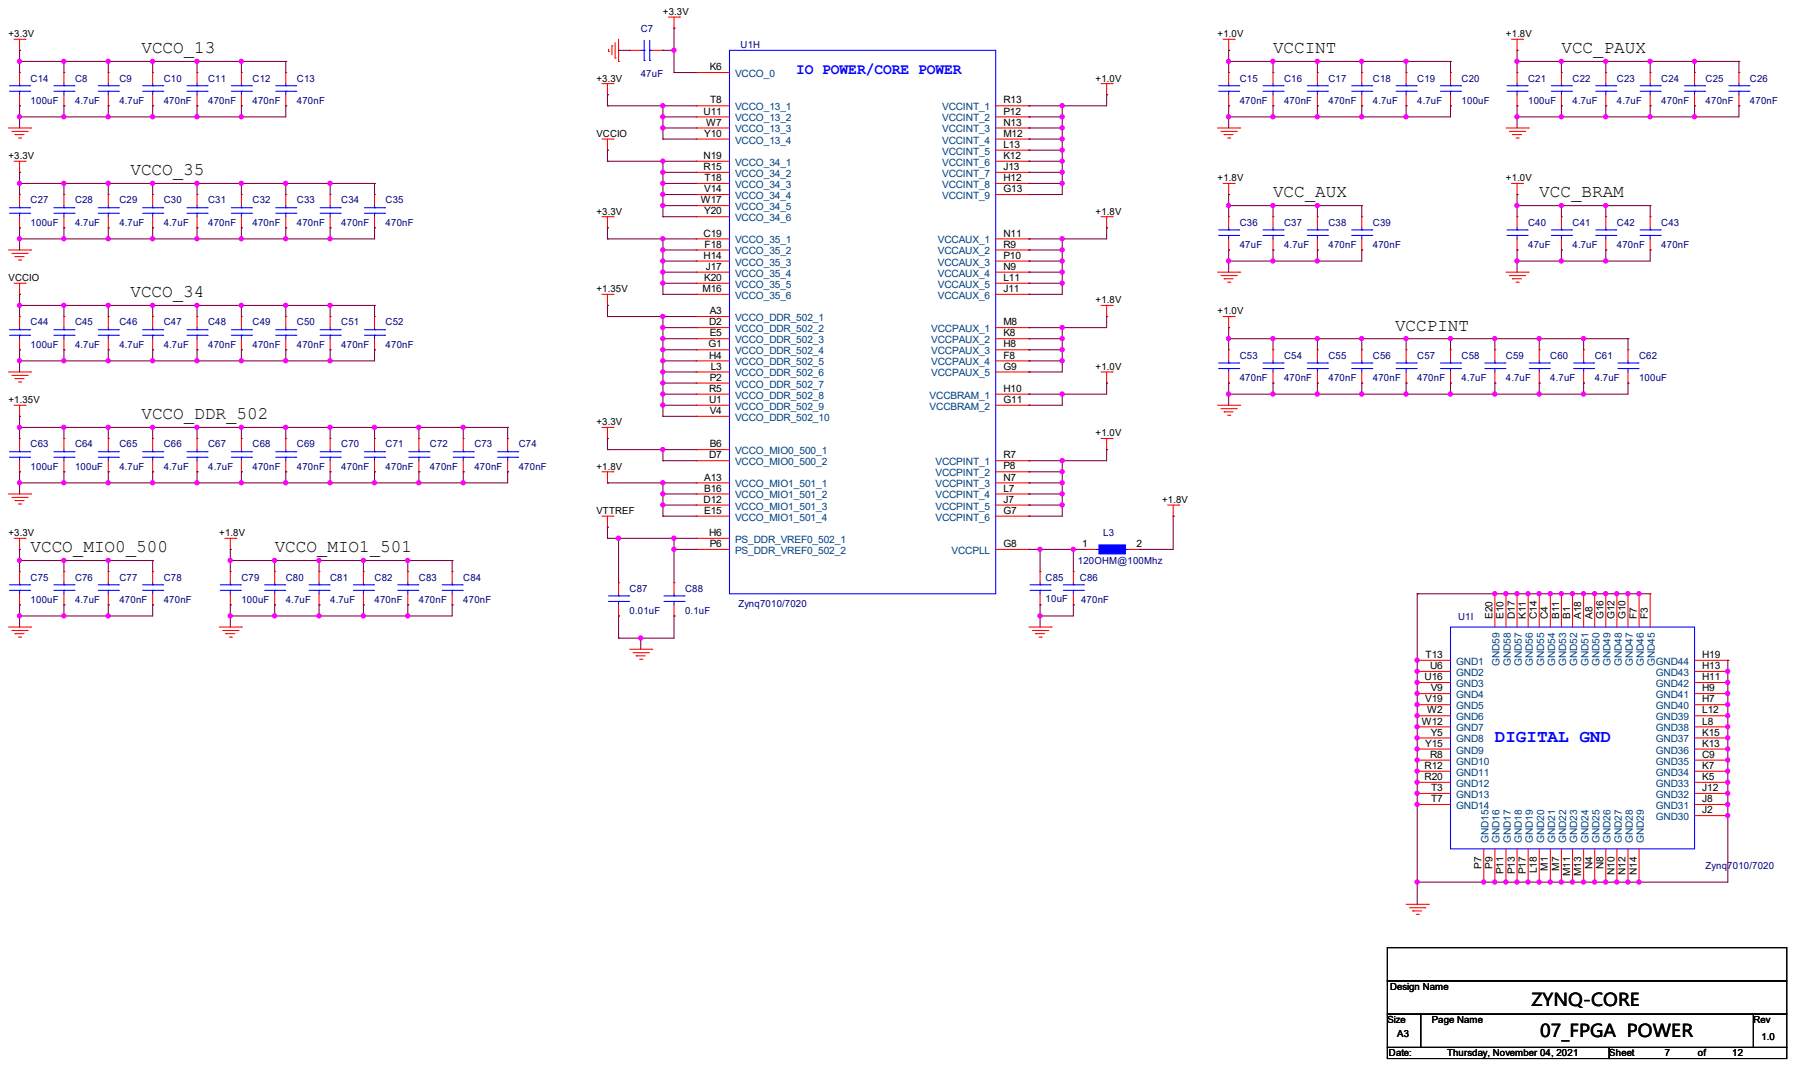
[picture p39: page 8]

IO POWER/CORE POWER U1H

DDR3_DQS0_P DDR3_D6 DDR3_D5 DDR3_D2 DDR3_D0 DDR3_D3 DDR3_D4 DDR3_D1 DDR3_D7 DDR3_D14 DDR3_D8 DDR3_D12 DDR3_D9 DDR3_D13 DDR3_D11 DDR3_D15 DDR3_D10 DDR3_DM0 DDR3_DM1

DDR3_A0 DDR3_A1 DDR3_A2 DDR3_A3 DDR3_A4 DDR3_A5 DDR3_A6 DDR3_A7 DDR3_A8 DDR3_A9 DDR3_A10 DDR3_A11 DDR3_A12 DDR3_A13 DDR3_A14 DDR3_BA0 DDR3_BA1 DDR3_BA2 DDR3_CLK0_P DDR3_CLK0_N

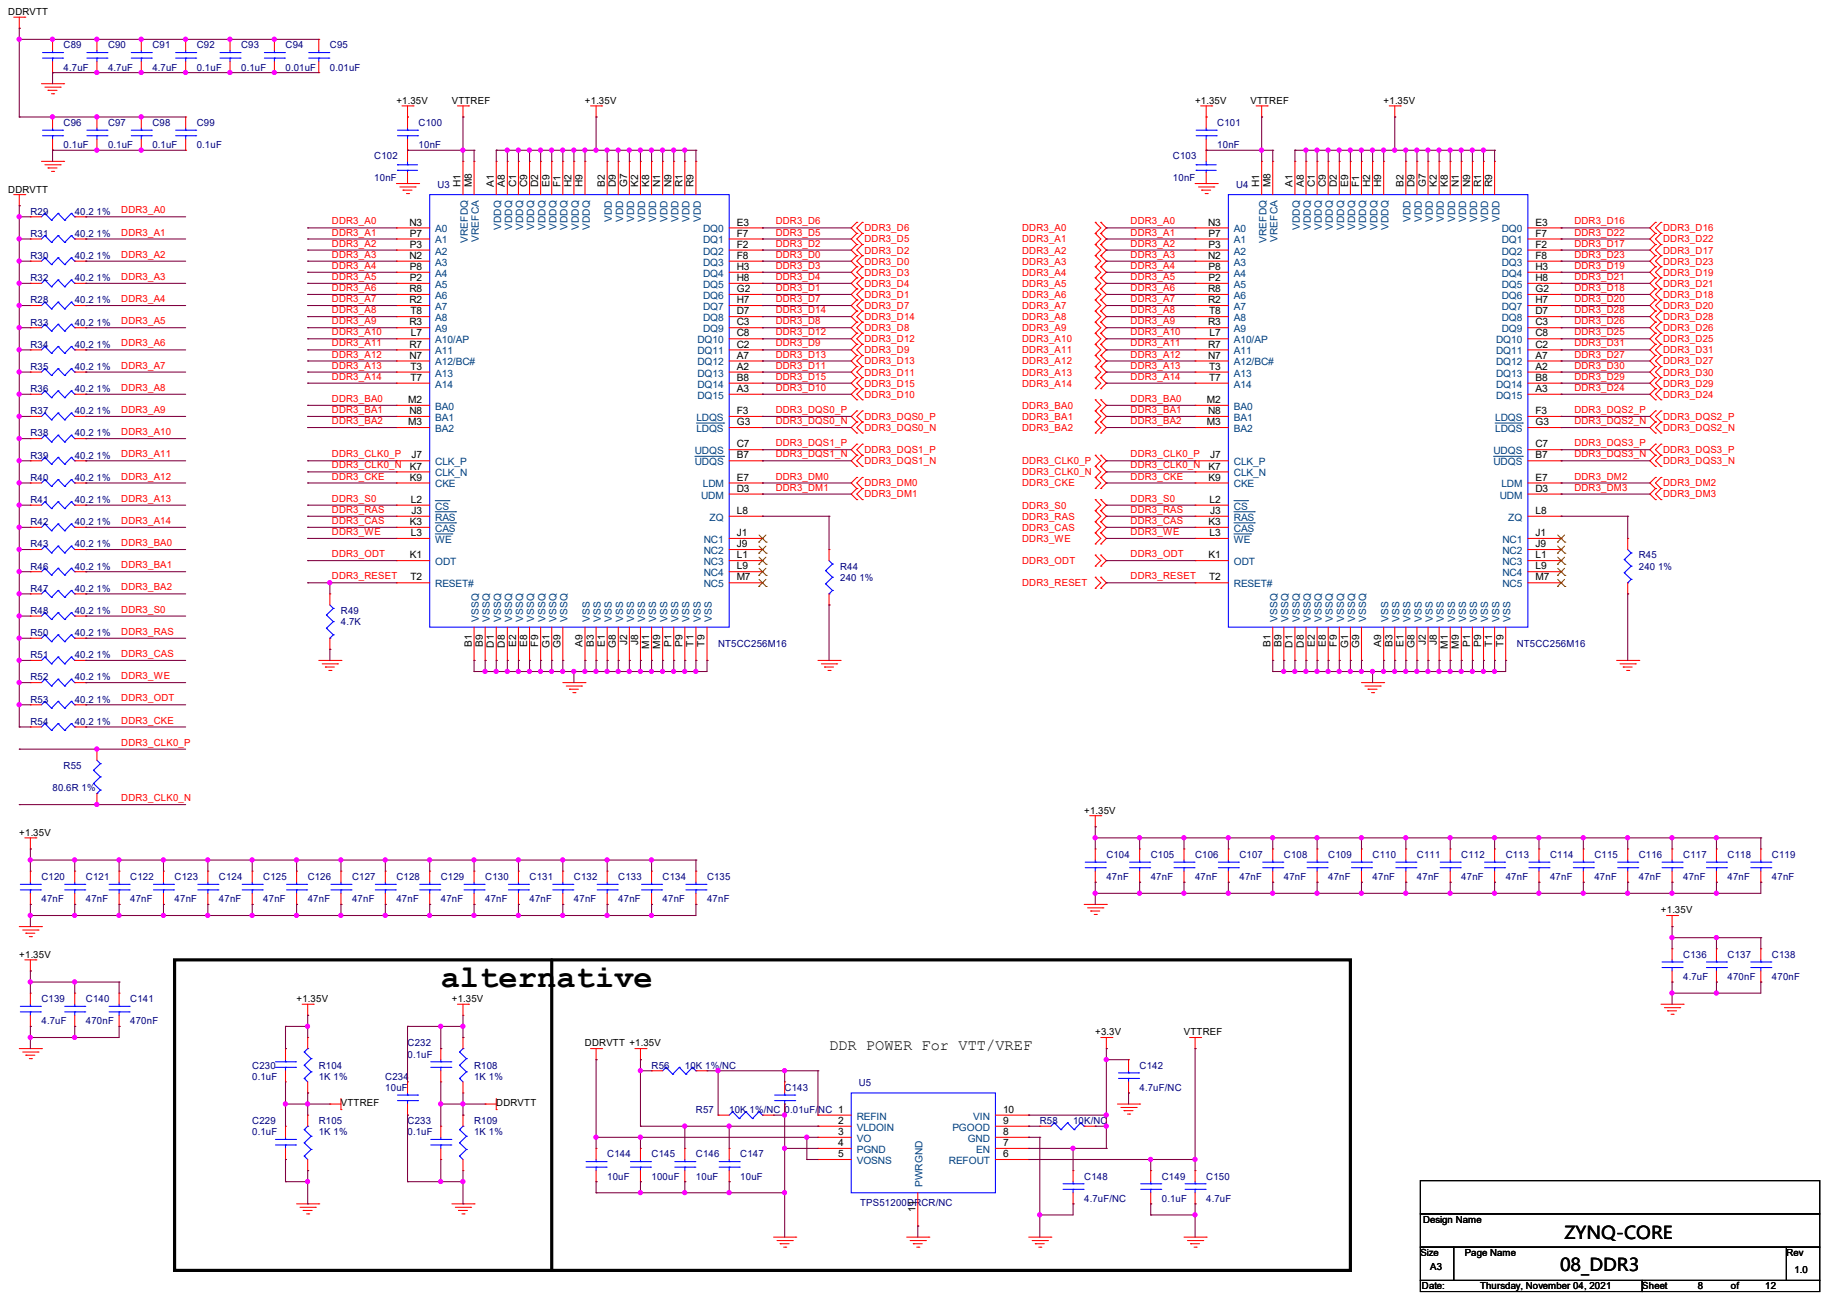
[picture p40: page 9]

DDR POWER For VTT/VREF

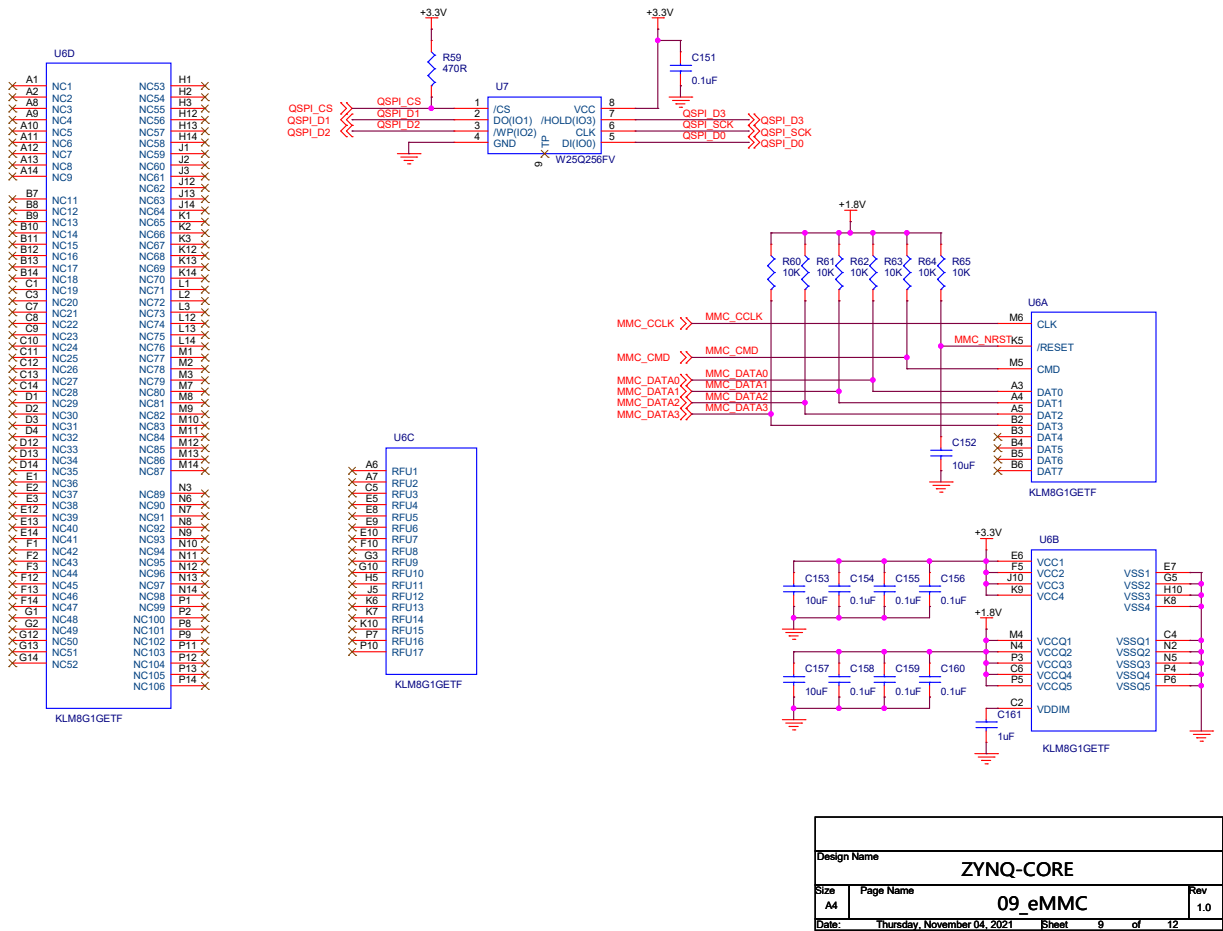
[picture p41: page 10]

## 1.0V POWER@2A

## Vout=0.6*R1/R2+0.6

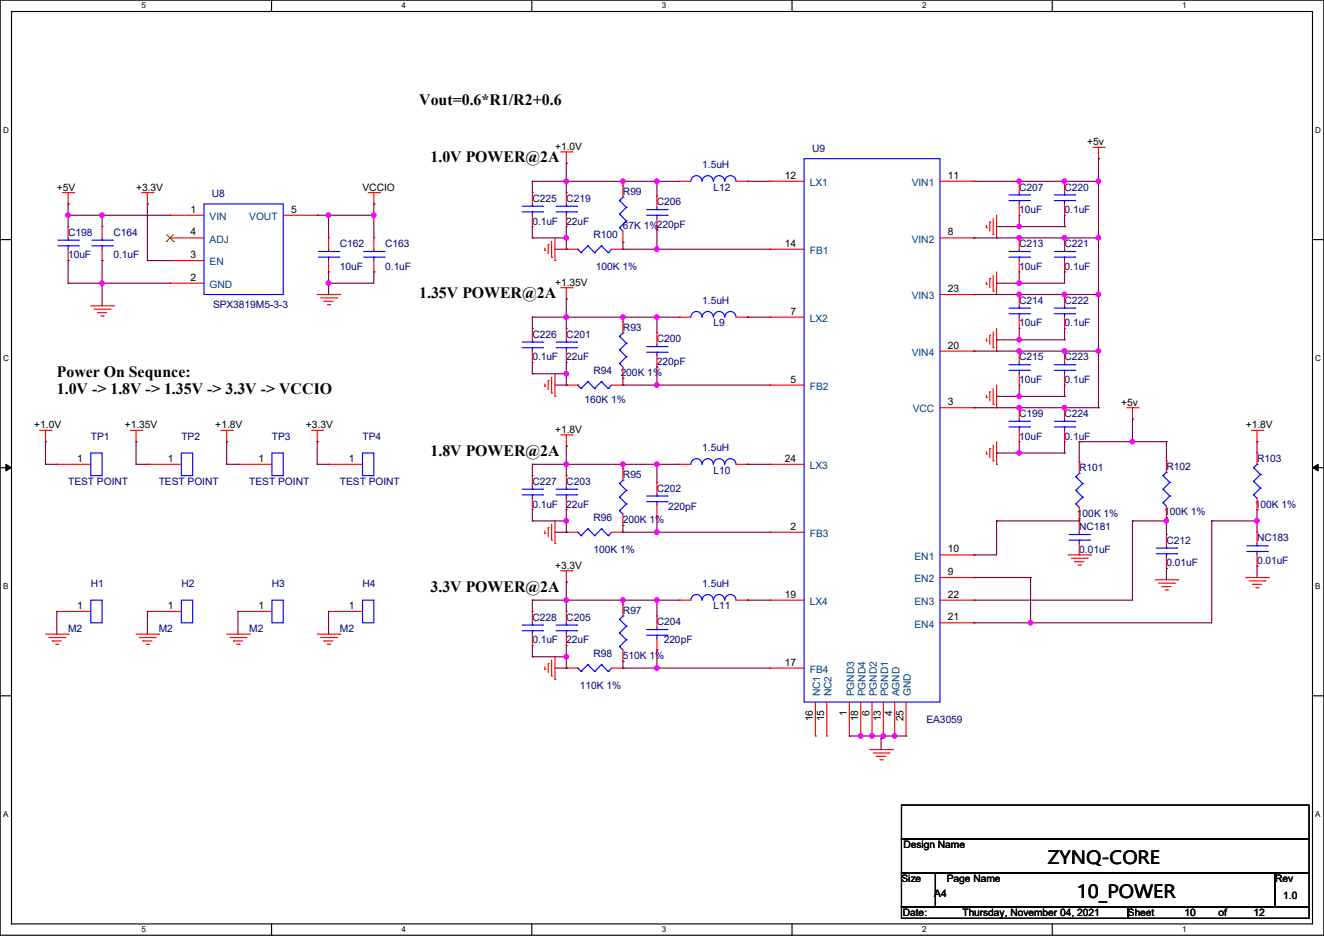
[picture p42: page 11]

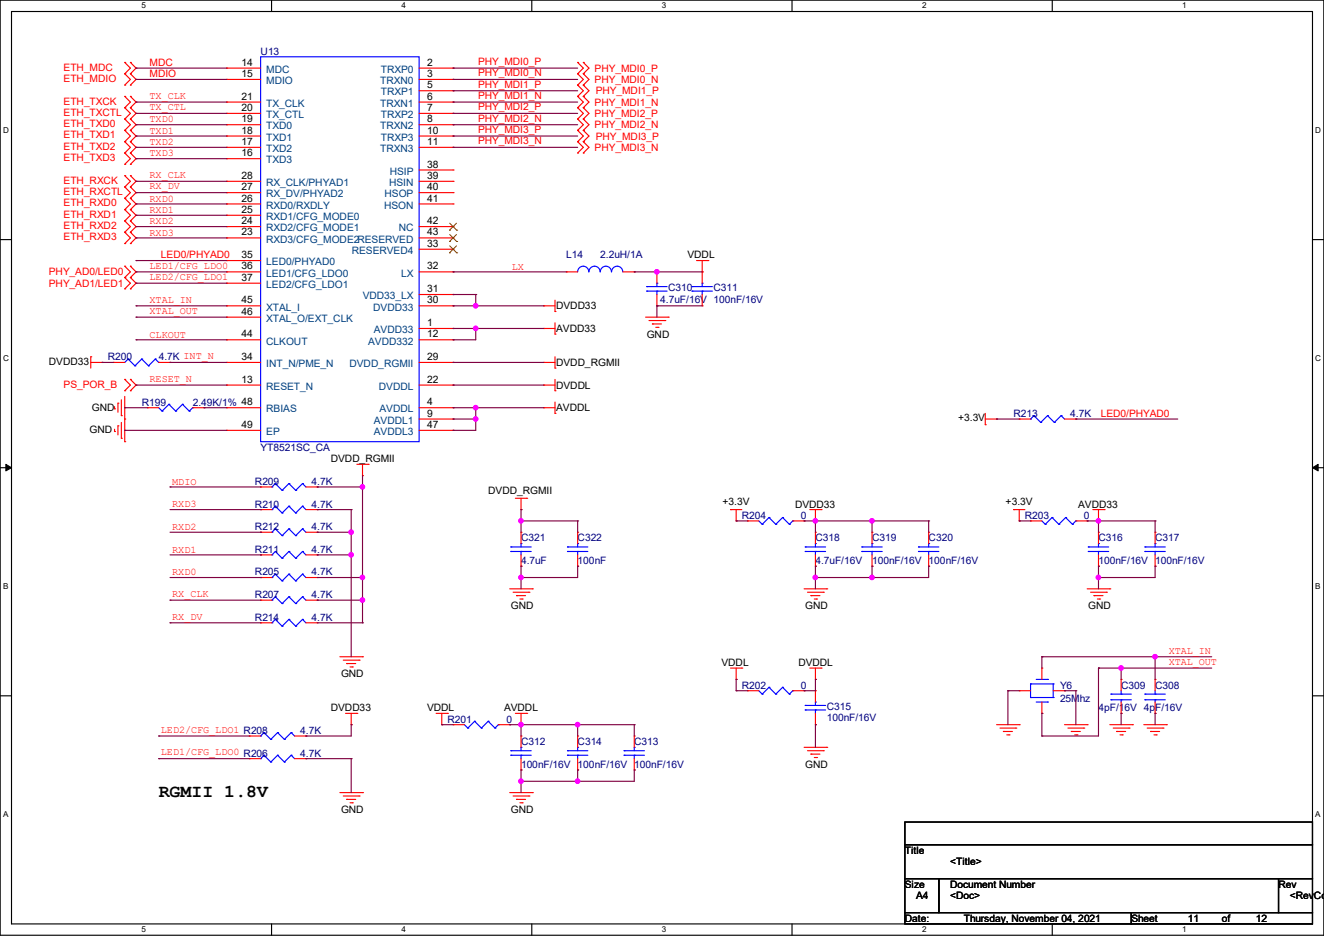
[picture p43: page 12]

Header_2X50_0.8mm 1 1 | 3 3 | 4 | 4 5 5 | 6 | 6 7 7 | 8 | 8 9 9
10 | 10 11 11 | 12 | 12 13 13 | 14 | 14 15 15 | 16 | 16 17 17 | 18 | 18 19 19 | 20 | 20 21 21 | 22 | 22 23 23 | 24 | 24 25 25 | 26 | 26 27 27 | 28 | 28 29 29 | 30 | 30 31 31 | 32 | 32 33 33 | 34 | 34 35 35 | 36 | 36 37 37 | 38 | 38 39 39 | 40 | 40 41 41 | 42 | 42 43 43 | 44 | 44 45 45 | 46 | 46 47 47 | 48 | 48 49 49 | 50 | 50 51 51 | 52 | 52 53 53 | 54 | 54 55 55 | 56 | 56 57 57 | 58 | 58 59 59 | 60 | 60 61 61 | 62 | 62 63 63 | 64 | 64 65 65 | 66 | 66 67 67 | 68 | 68 69 69 | 70 | 70 71 71 | 72 | 72 73 73 | 74 | 74 75 75 | 76 | 76 77 77 | 78 | 78 79 79 | 80 | 80 81 81 | 82 | 82 83 83 | 84 | 84 85 85 | 86 | 86 87 87 | 88 | 88 89 89 | 90 | 90 91 91 | 92 | 92 93 93 | 94 | 94 95 95 | 96 | 96 97 97 | 98 | 98 99 99 | 100 | 100 2 | 2

UART_RXD UART_TXD; QSPI_D2 QSPI_D3; OTG_NXT; OTG_DATA1; PHY_MDI2_N; PHY_AD1/LED1; PHY_MDI1_P; PHY_AD0/LED0; PHY_MDI1_N; PHY_MDI2_P; OTG_DATA0; OTG_STP; OTG_CLK; OTG_DATA3 OTG_DATA6; OTG_DIR; OTG_DATA7; OTG_DATA4; OTG_DATA2; OTG_DATA5; PS_MIO12; XADC_VP XADC_VN; SD_CMD; SD_CLK; PHY_MDI0_P; PHY_MDI0_N; PHY_MDI3_N PHY_MDI3_P; FPGA_TDO; FPGA_TCK; FPGA_TMS; FPGA_TDI; PS_MIO9; PS_MIO7 PS_MIO13; PS_MIO11; PS_MIO8; PS_MIO10; Design Name; ZYNQ-CORE; Tuesday, January 18, 2022; 12_CONNECTOR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

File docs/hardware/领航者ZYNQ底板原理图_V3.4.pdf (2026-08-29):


USB UART&USB POWER

DC-DC POWER IN

Size A4 | Number | Revision

Date: 2022/7/2 | Sheet of
File: E:\ZYNQ\..\01_POWER&UART.SchDoc | Drawn By:



LED 1 KEY 2 RXD 3 TXD 4


PHY1_MDI1_N

PHY1_MDI2_P | TX3- 8 TX3+ 7

PHY1_MDI2_N

PHY1_MDI3_N | TX4- 10

VSS 6

SPKR+和SPKR-连接开发板自带的喇叭，在开发板底部。 AGND

SPKGND1 24

DGND 9


R8 | 5 | 4.7 K RGMII_RXD1 | RXD1 28
R8 | 6 | 4.7 K RGMII_RXD2 | RXD2 26

LED_ACT(IPU) RXD1(IPD) RXD0(IPD) RXD3(IPD) LED_1000(IPU) RXD2(IPD) RX_DV(IPD) LED_10_100(IPU) RX_CLK(IPD) | PHY_ADDR(2) PHY_ADDR(1) PHY_ADDR(0) MODE_SEL(1) MODE_SEL(0) PLLON 3.3V/2.5V_SEL RXC_delay_en CLK_25M_en | PHY Addr=00000+PHYA(2:0) 01=force low power mode; 11=normal mode; 0=PLL OFF in hibernation; 1=PLL ON in hibernation; 0=RGMll 1O 3.3V; 1=RGMll 1O 2.5V ; 0=RXC delay disable; 1=RXC delay enable; 0=CLK_25M enable; 1=CLK_25M disable;

PLL OFF in hibernation

File: E:\ZYNQ\..\05_ETH.SchDoc | Drawn By:



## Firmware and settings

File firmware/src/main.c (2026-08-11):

/**
 * @file main.c
 * @brief 固件入口点
 *
 * 职责:
 *   - 系统初始化 (时钟/电源/外设)
 *   - 启动各服务模块
 *   - 进入主循环或 RTOS 调度
 */

#include "hal/hal_init.h"
#include "app/app_main.h"
#include "services/service_manager.h"

int main(void)
{
    /* 1. 硬件抽象层初始化 */
    hal_init();

    /* 2. 服务层启动 */
    service_manager_init();

    /* 3. 应用层入口 */
    app_run();

    /* 不应到达此处 */
    while (1) {
        /* idle / WFI */
    }

    return 0;
}

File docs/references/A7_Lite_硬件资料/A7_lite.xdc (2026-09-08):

# ----------------------------------------------------------------------------
# 
#  Created With Xilinx Vavado 2021.1 
#   Date : 2022.09.01
# 
#  This design is the property of MicroPhase.  Publication of this
#  design is not authorized without written consent from MicroPhase.
# --------------------------------------------------------------------
#           
#               MicroPhase Technologies Inc
#               Shanghai, China
#
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
# ----------------------------------------------------------------------------
#################时钟信号和复位信号##########################
set_property PACKAGE_PIN J19 [get_ports CLK_50M]
set_property PACKAGE_PIN L18 [get_ports RESET]

set_property IOSTANDARD LVCMOS33 [get_ports CLK_50M]
set_property IOSTANDARD LVCMOS33 [get_ports RESET]
#################按键信号##########################
set_property PACKAGE_PIN AA1 [get_ports KEY1]
set_property PACKAGE_PIN W1 [get_ports KEY2]

set_property IOSTANDARD LVCMOS33 [get_ports KEY1]
set_property IOSTANDARD LVCMOS33 [get_ports KEY2]
#################LED#################
set_property PACKAGE_PIN M18 [get_ports LED1]
set_property PACKAGE_PIN N18 [get_ports LED2]

set_property IOSTANDARD LVCMOS33 [get_ports LED1]
set_property IOSTANDARD LVCMOS33 [get_ports LED2]
#################HDMI#################
set_property PACKAGE_PIN L19 [get_ports HDMI1_CLK_P]
set_property PACKAGE_PIN K21 [get_ports HDMI1_D0_P]
set_property PACKAGE_PIN J20 [get_ports HDMI1_D1_P]
set_property PACKAGE_PIN G17 [get_ports HDMI1_D2_P]
set_property PACKAGE_PIN H15 [get_ports HDMI1_HPD_CON]

set_property IOSTANDARD TMDS_33  [get_ports HDMI1_CLK_P]
set_property IOSTANDARD TMDS_33  [get_ports HDMI1_D0_P]
set_property IOSTANDARD TMDS_33  [get_ports HDMI1_D1_P]
set_property IOSTANDARD TMDS_33  [get_ports HDMI1_D2_P]
set_property IOSTANDARD LVCMOS33 [get_ports HDMI1_HPD_CON]
#################UART#################
set_property PACKAGE_PIN  U2      [get_ports UART_RX]
set_property PACKAGE_PIN  V2      [get_ports UART_TX]

set_property IOSTANDARD   LVCMOS33 [get_ports UART_RX]
set_property IOSTANDARD   LVCMOS33 [get_ports UART_TX]
#################EEPROM#################
set_property PACKAGE_PIN  J22    [get_ports EEPROM_I2C_SCL]
set_property PACKAGE_PIN  H22    [get_ports EEPROM_I2C_SDA]

set_property IOSTANDARD LVCMOS33 [get_ports EEPROM_I2C_SCL]     
set_property IOSTANDARD LVCMOS33 [get_ports EEPROM_I2C_SDA]   
#################sd card#################
set_property PACKAGE_PIN   U7    [get_ports SD_CLK]
set_property PACKAGE_PIN   AA8   [get_ports SD_CMD]
set_property PACKAGE_PIN   W9    [get_ports SD_DATA0]
set_property PACKAGE_PIN   Y9    [get_ports SD_DATA1]
set_property PACKAGE_PIN   Y7    [get_ports SD_DATA2]
set_property PACKAGE_PIN   Y8    [get_ports SD_DATA3]

set_property IOSTANDARD LVCMOS33 [get_ports SD_CLK]   
set_property IOSTANDARD LVCMOS33 [get_ports SD_CMD]
set_property IOSTANDARD LVCMOS33 [get_ports SD_DATA0]   
set_property IOSTANDARD LVCMOS33 [get_ports SD_DATA1]
set_property IOSTANDARD LVCMOS33 [get_ports SD_DATA2]   
set_property IOSTANDARD LVCMOS33 [get_ports SD_DATA3]

########################ethernet port######################
set_property PACKAGE_PIN N22 [get_ports ETH_nRST]
set_property PACKAGE_PIN M22 [get_ports ETH_MDC]
set_property PACKAGE_PIN M20 [get_ports ETH_MDIO]
set_property PACKAGE_PIN K18 [get_ports ETH_RXCK]
set_property PACKAGE_PIN K19 [get_ports ETH_RXCTL]
set_property PACKAGE_PIN M16 [get_ports {ETH_RXD[3]}]
set_property PACKAGE_PIN L16 [get_ports {ETH_RXD[2]}]
set_property PACKAGE_PIN M15 [get_ports {ETH_RXD[1]}]
set_property PACKAGE_PIN L14 [get_ports {ETH_RXD[0]}]
set_property PACKAGE_PIN K17 [get_ports ETH_TXCK]
set_property PACKAGE_PIN N20 [get_ports ETH_TXCTL]
set_property PACKAGE_PIN M13 [get_ports {ETH_TXD[3]}]
set_property PACKAGE_PIN L13 [get_ports {ETH_TXD[2]}]
set_property PACKAGE_PIN L15 [get_ports {ETH_TXD[1]}]
set_property PACKAGE_PIN K16 [get_ports {ETH_TXD[0]}]

set_property IOSTANDARD LVCMOS33 [get_ports ETH_nRST]
set_property IOSTANDARD LVCMOS33 [get_ports ETH_MDC]
set_property IOSTANDARD LVCMOS33 [get_ports ETH_MDIO]
set_property IOSTANDARD LVCMOS33 [get_ports ETH_RXCK]
set_property IOSTANDARD LVCMOS33 [get_ports ETH_RXCTL]
set_property IOSTANDARD LVCMOS33 [get_ports {ETH_RXD[*]}]
set_property IOSTANDARD LVCMOS33 [get_ports ETH_TXCK]
set_property IOSTANDARD LVCMOS33 [get_ports ETH_TXCTL]
set_property IOSTANDARD LVCMOS33 [get_ports {ETH_TXD[*]}]

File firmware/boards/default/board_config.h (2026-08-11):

/**
 * @file board_config.h
 * @brief 默认板级配置
 *
 * 此文件定义默认硬件引脚映射和参数。
 * 不同硬件版本应创建独立的 boards/<board_name>/board_config.h
 */

#ifndef BOARD_CONFIG_H
#define BOARD_CONFIG_H

/* ---- MCU 配置 ---- */
#define BOARD_NAME              "default"
#define MCU_TYPE                "STM32F407"
#define SYSTEM_CLOCK_HZ         168000000

/* ---- UART 引脚映射 ---- */
#define UART_DEBUG_TX_PIN       GPIO_PIN_9    /* PA9  */
#define UART_DEBUG_RX_PIN       GPIO_PIN_10   /* PA10 */
#define UART_DEBUG_BAUDRATE     115200

/* ---- SPI 引脚映射 ---- */
#define SPI_SCK_PIN             GPIO_PIN_5
#define SPI_MISO_PIN            GPIO_PIN_6
#define SPI_MOSI_PIN            GPIO_PIN_7
#define SPI_CS_PIN              GPIO_PIN_4

/* ---- I2C 引脚映射 ---- */
#define I2C_SCL_PIN             GPIO_PIN_6    /* PB6 */
#define I2C_SDA_PIN             GPIO_PIN_7    /* PB7 */

/* ---- LED / 按键 ---- */
#define LED_STATUS_PIN          GPIO_PIN_13   /* PC13 */
#define BTN_USER_PIN            GPIO_PIN_0    /* PA0  */

#endif /* BOARD_CONFIG_H */

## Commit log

2026-08-11 sch update commit
    [CORE.kicad_pcb, CORE.kicad_sch]
2026-08-12 sch update
    [CORE.kicad_sch]
2026-08-22 shc update
    [CORE.kicad_pcb, CORE.kicad_sch]
2026-08-27 core update
    [CORE.kicad_pcb, CORE.kicad_sch]
2026-08-27 add CORE_CAST
    [CORE_CAST.kicad_pcb, CORE_CAST.kicad_sch]
2026-08-27 update core_cast sch
    [CORE_CAST.kicad_sch]
2026-08-28 sch updaate
    [CORE_CAST.kicad_sch]
2026-08-28 sch upate
    [CORE_CAST.kicad_sch]
2026-10-13 sch and pcb update

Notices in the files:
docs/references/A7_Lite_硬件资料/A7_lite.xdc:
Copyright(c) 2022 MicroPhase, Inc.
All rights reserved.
